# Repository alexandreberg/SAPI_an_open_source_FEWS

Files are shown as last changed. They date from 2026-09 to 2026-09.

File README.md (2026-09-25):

# SAPI — Sistema de Alerta Prévio de Inundações

**Flood Early Warning System** — a low-cost, open-source, LoRa-based platform for water-level
and rainfall monitoring, machine-learning flood forecasting and multi-channel alerts,
developed and validated as a Master's dissertation project (IFSC, Florianópolis, Brazil).

## Read this README in your language / Leia este README no seu idioma

| Language | File |
|---|---|
| 🇬🇧 English | **[README-en.md](README-en.md)** |
| 🇧🇷 Português | **[README-pt.md](README-pt.md)** |

> **Note / Nota** — The code, comments and most technical documentation in this repository
> are in **English**; the README and some documents in `docs/` are also in **Portuguese**,
> the language of the dissertation.
>
> O código, os comentários e a maior parte da documentação técnica deste repositório estão
> em **inglês**; o README e alguns documentos em `docs/` estão também em **português**, o
> idioma da dissertação.

## Quick links / Links rápidos

- Releases (firmware, models, hardware, web interface):
  <https://github.com/alexandreberg/SAPI_an_open_source_FEWS/releases>
- Project specification / Especificação do projeto: [`docs/system-overview.md`](docs/system-overview.md)
- Changelog: [`CHANGELOG.md`](CHANGELOG.md)
- Predictive models / Modelos preditivos:
  [`predictive-models/`](predictive-models/README.md)
- How this repository was built / Como este repositório foi construído:
  [`docs/PROVENANCE.md`](docs/PROVENANCE.md)

## License / Licença

<a href="LICENSE">AGPL v3</a>
<a href="LICENSES/CERN-OHL-S-2.0.txt">Open Source Hardware</a>

Software: [AGPL-3.0-or-later](LICENSE) · Hardware (`hardware/`):
[CERN-OHL-S-2.0](LICENSES/CERN-OHL-S-2.0.txt) · Third-party credits / Créditos: [`NOTICE`](NOTICE)

Copyright (C) 2024–2026 Alexandre Nuernberg.

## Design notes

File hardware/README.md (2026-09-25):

# Hardware — KiCad projects

KiCad 9 projects of the two custom shields used by the SAPI stations. Both are
fabrication-ready (gerbers in `gerber_to_order/`) and licensed under
[CERN-OHL-S-2.0](../LICENSES/CERN-OHL-S-2.0.txt).

| Project | Release | What it does |
|---|---|---|
| [`morpho-shield-v1.2/`](morpho-shield-v1.2/) | `shield-morpho-v1.2.0` | ST Morpho interface board: tipping-bucket rain-gauge pulse counting, serial and trigger/echo ultrasonic sensor interfaces (US-100, HC-SR04, AJ-SR04M), I²C sensor bus (SHT20, BMP280), ADC for solar-panel and battery voltages, ST-Link connector, switched 3.3 V/5 V rails, 5 spare GPIOs |
| [`lora-arduino-shield-v1.0/`](lora-arduino-shield-v1.0/) | `shield-lora-arduino-v1.0.0` | Arduino-footprint radio shield for RFM69HC and LilyGo LoRa32 modules (any frequency; SAPI uses 915 MHz), with a debug LED that can be disabled for low power, a reset button and reconfigurable GPIOs |

## Git LFS and the 3D models

The 3D models (`*.step`, `*.stp`, `*.stl`, `*.wrl`, and zipped models) are stored in
**Git LFS**, ~0.9 GB in total. To clone without them:

```bash
GIT_LFS_SKIP_SMUDGE=1 git clone https://github.com/alexandreberg/SAPI_an_open_source_FEWS.git
```

KiCad opens the projects without the models; only the 3D viewer needs them. Each release
also has the complete project, models included, as a `.tar.gz` attachment.

## Third-party content

The SAPI design files (schematics, layouts, gerbers, BOM) are the author's work. The
projects also contain material **not** authored here, which keeps its original terms and
is not covered by the CERN-OHL-S licence:

- **3D models** (80 files per project) downloaded from CAD-sharing sites — folders named
  `*.snapshot.N` follow their download naming — made in SolidWorks, CATIA, FreeCAD,
  PRO/ENGINEER, the ASCON kernel and KiCad StepUp. Among them: the STM32 BluePill model,
  BME280/BMP280 modules, an SW868 antenna, 2.54 mm jumpers and pin headers, tactile and
  push switches, an optocoupler.
- **Symbol and footprint libraries** from SnapEDA and Digi-Key (`Project_Libraries/`,
  `Libraries/`).
- **Datasheets** of the 74HC166, CD4020BC, CD4040BEE4 and TIL133
  (`morpho-shield-v1.2/datasheets/`).

Their licences were not individually verified. If you are a rights holder and want a file
removed, please open an issue.

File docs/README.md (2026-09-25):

# Documentation

Documents are in English unless marked **(pt)**; a few were written in Portuguese, the
language of the dissertation, and are kept as they are.

## Start here

- [`system-overview.md`](system-overview.md) — stations, gateway, communication,
  requirements, software stack, known limitations
- [`PROVENANCE.md`](PROVENANCE.md) — how this repository was built from the private
  development repository, what was changed and what was left out
- [`architecture/`](architecture/) — network topology and station location map
  ([PDF](architecture/mapa-localizacao-estacoes.pdf))

## Web interface

- [`webserver/deployment-guide.md`](webserver/deployment-guide.md) — installing on shared hosting
- [`webserver/webserver-design.md`](webserver/webserver-design.md) — design and database
- [`webserver/alert-systems-overview.md`](webserver/alert-systems-overview.md) — the alert
  systems (observed-level thresholds and predictive alerts)
- [`webserver/predictions-forecast-verification.md`](webserver/predictions-forecast-verification.md)
  — retrospective verification of fired forecasts
- [`webserver/compare-tool-guide.md`](webserver/compare-tool-guide.md) — the station comparison tool

## Predictive models

- [`predictive-models/production_pipeline_guide.md`](predictive-models/production_pipeline_guide.md) — M4 (LightGBM) in production
- [`predictive-models/production_pipeline_m6_guide.md`](predictive-models/production_pipeline_m6_guide.md) — M6 (MLR) in production
- [`predictive-models/limiares_e_catalogo_v3.md`](predictive-models/limiares_e_catalogo_v3.md) **(pt)** — thresholds and the v3 event catalogue
- [`predictive-models/artefatos_catalogo_v3.md`](predictive-models/artefatos_catalogo_v3.md) **(pt)** — the sensor artifacts excluded from the catalogue

The code, results and audit report are in [`../predictive-models/`](../predictive-models/).

## Hardware

- [`hardware/BOM_custos.md`](hardware/BOM_custos.md) **(pt)** — bill of materials and costs
- [`hardware/station-03-power-instability-2026-08/`](hardware/station-03-power-instability-2026-08/README.md)
  — diagnosis of the Station-03 power/connector fault of August 2026

The KiCad projects are in [`../hardware/`](../hardware/).

## Bench and field tests

- [`tests/us-100/`](tests/us-100/) — US-100 ultrasonic sensor, serial mode (tests 01–04) and
  trigger/echo mode, with photos and readings
- [`tests/m2m/`](tests/m2m/M2M_Test_Report.md) — NB-IoT/LTE-M cellular tests of the gateway
  ([pt](tests/m2m/M2M_Test_Report_Portuguese.md)); modem logs in the same folder, SIM and
  modem identifiers masked
- [`tests/notifications-m4-m6/`](tests/notifications-m4-m6/notification_test_m4_m6.md) —
  Telegram and e-mail notifications of the predictive alerts

## Licensing

- [`licensing/SAPI_Licensing_Report.md`](licensing/SAPI_Licensing_Report.md) — why
  AGPL-3.0-or-later for software and CERN-OHL-S-2.0 for hardware, and the dependency
  compatibility audit

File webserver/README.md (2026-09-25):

# Web interface

PHP/MariaDB application of SAPI: real-time and historical monitoring, station, contact and
alert management, the predictions dashboard, the endpoint that receives the gateway's
data, and the alert cron jobs. In operation at <https://ilha3d.com/sapi/>.

Releases: `webserver-v1.0.0` (first release, 2026-07-06) and `webserver-v1.1.0` (the
version deployed today).

## Layout

| Path | Contents |
|---|---|
| `public_html/sapi/` | The application: dashboard, admin panel, predictions, API, the gateway endpoint (`sensorData/receive-data.php`) |
| `cron/` | Alert engine (e-mail, Telegram) and level-filter cron jobs |
| `private_configs/` | **Templates only** (`*-sample.*`) of the files that hold the database, mail, API and Telegram credentials; they live outside the web root |
| `database/schema_20260313.sql` | Schema snapshot (structure only) |
| `migration_*.sql` | Schema migrations, applied after the snapshot in issue order |

## Deploying

The full guide is [`docs/webserver/deployment-guide.md`](../docs/webserver/deployment-guide.md).
In short:

1. Every path in the code uses `/home/<HOSTINGER_USER>/…`; replace `<HOSTINGER_USER>` with
   your own hosting account (or adapt the paths to your server).
2. Copy each `*-sample.*` file in `private_configs/` and `cron/credenciais-sample.php` to
   its real name (without `-sample`) and fill in your own values. The real names are in
   `.gitignore` — never commit them.
3. The API key in `private_configs/sapi/db_config.php` must match the gateway's
   `apiKey` (see [`../firmware/gateway-01/`](../firmware/gateway-01/README.md)).
4. Create the database from `database/schema_20260313.sql`, then apply
   `migration_issue52.sql` → `migration_issue57.sql` → `migration_issue108.sql` →
   `migration_issue110.sql` → `migration_m6_mlr.sql`.
5. Install the PHP dependencies with Composer (`composer.json`).

Design notes: [`docs/webserver/`](../docs/webserver/).

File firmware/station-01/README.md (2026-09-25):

# SAPM_Sensor_BluePill
This is a code for a flood alert system, FEWS (Flood Early Warning System) or in Portuguese SAPI (Sistema de Alerta Prévio de Inundações) the "M" in SAPM comes from de "Modular" version that will accept other types of sensors.
This version runs on STM32 BluePill.

It connects to a LoRa Gateway build with ESP32 **LILYGO-SIM7000G** wich code can be found [here:](https://github.com/alexandreberg/LILYGO-SIM7000G_LoRa_Gateway)

This is the code that is running in the Sensor-01 installed in the Bridge-02 in 01/01/2025.

The objective of this code is to generate data for the PCAM master thesis to have at least one year of data for analysis.

The code will be improved in the other sensors that will be installed.

## Folder structure:
```
C:.
├───Documentation                           // Documentation Folder
│   ├───Pictures                                    
│   │   └───SAPI_sensor_01                  // Pictures from the sensor PCB, case and fixing structure
│   └───Schematics
│       └───Transmissor_STM32_BluePill_V1   // Schematics of the board
├───src
PS C:\Projetos_GitHub\SAPM\SAPM_Sensor_BluePill>
```

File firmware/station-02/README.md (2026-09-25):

# Rain Gauge Nucleo F103RB (Estação-02)

This is the main production code for the Rain Gauge Station **estacao-02**, developed for a master's degree project.  
The station has been operational since **January 3rd, 2026**.

## 🛠 Hardware Architecture

The station is based on the **STM32 Nucleo F103RB** MCU and utilizes two specialized shields:
* **SAPI LoRa Arduino Shield**: Responsible for long-range wireless communication.
* **SAPI Morpho Shield**: Used for sensor interfacing and power management.

---

## 📊 Live Data & Graphics

You can monitor the real-time sensor data through the following links:

| Variable | Data Visualization Link |
| :--- | :--- |
| 🌡️ **Temperature** | [View Temperature (°C)](https://ilha3d.com/sapi/view.php?id_station=2&var=temperature_C) |
| 🎈 **Pressure** | [View Atmospheric Pressure](https://ilha3d.com/sapi/view.php?id_station=2&var=pressure) |
| 🌧️ **Precipitation** | [View Precipitation Pulses](https://ilha3d.com/sapi/view.php?id_station=2&var=precipitation_pulses) |
| 📡 **Signal (RSSI)** | [View Radio Signal Strength](https://ilha3d.com/sapi/view.php?id_station=2&var=rssi) |
| ☀️ **Panel Voltage** | [View Solar Panel Voltage](https://ilha3d.com/sapi/view.php?id_station=2&var=panel_voltage) |
| 🔋 **Battery** | [View Battery Voltage](https://ilha3d.com/sapi/view.php?id_station=2&var=bat_voltage) |

---

## 📷 Documentation

### General Overview
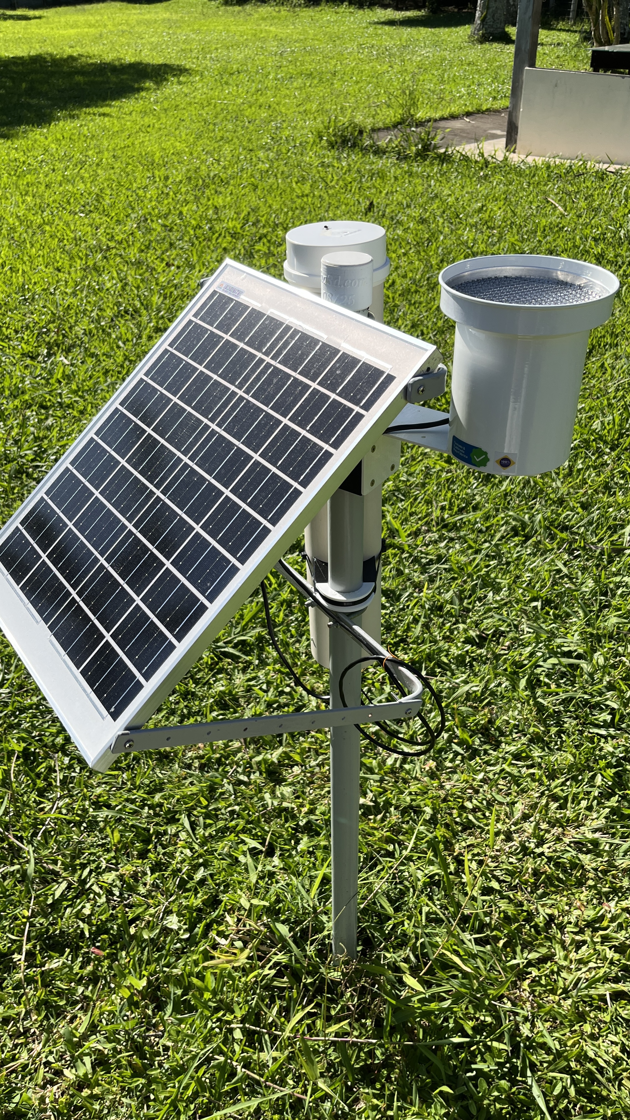
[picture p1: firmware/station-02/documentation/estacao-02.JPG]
General Overview


### MCU and Radio Shield
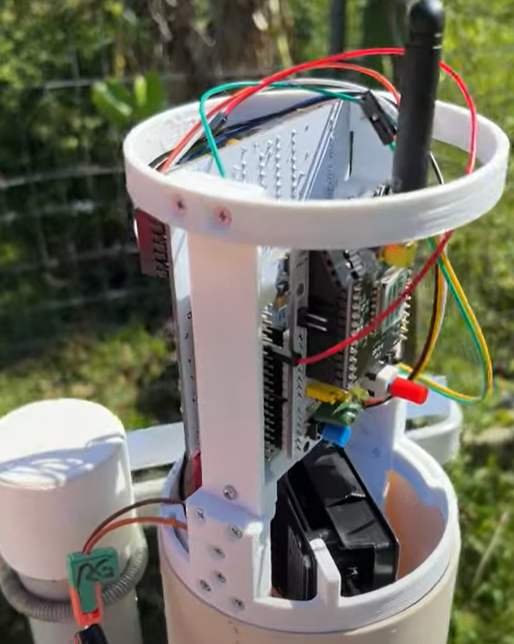
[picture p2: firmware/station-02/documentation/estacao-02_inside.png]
Inside View


### Internal Components
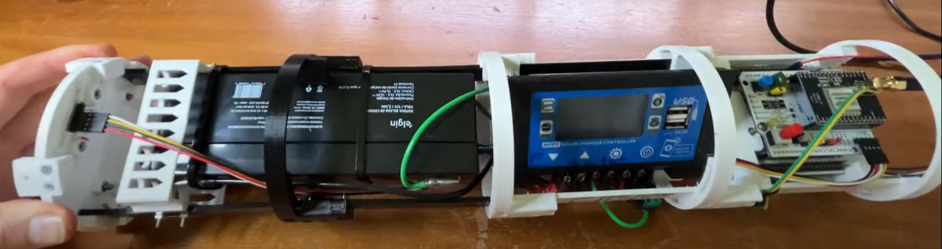
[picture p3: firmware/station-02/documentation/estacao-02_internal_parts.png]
Internal Parts


---
*Developed as part of a Master's Degree

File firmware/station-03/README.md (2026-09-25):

# Water Level Station - Nucleo L476RG (Estacao-03)

This is the main production code for the Water Level Station **estacao-03**, developed for a master's degree project.

## Hardware Architecture

The station is based on the **STM32 Nucleo L476RG** MCU and utilizes two specialized shields:
* **SAPI LoRa Arduino Shield**: Responsible for long-range wireless communication.
* **SAPI Morpho Shield**: Used for sensor interfacing and power management.

---

## GPIO Pin Mapping

### LoRa Radio (SX1276/RFM95W) - SPI Interface

| Pin | Function | Description |
|---|---|---|
| PA4 | LoRa_NSS | SPI Chip Select |
| PA5 | LoRa_SCK | SPI Clock |
| PA6 | LoRa_MISO | SPI Data In (Master In Slave Out) |
| PA7 | LoRa_MOSI | SPI Data Out (Master Out Slave In) |
| PA1 | LoRa_RST | Radio Reset |
| PB0 | LoRa_DIO0 | Interrupt (hardware interrupt pin) |
| PB3 | LoRa_Pwr_enable | Power supply enable (HW-613 module)  |

### Ultrasonic Sensor - Multi-sensor Support

The module supports 3 ultrasonic sensor types with a unified API:

| Sensor | Mode | Range | Baud | Command | Notes |
|---|---|---|---|---|---|
| HC-SR04  | Echo | 2-400 cm  | - | - | Default sensor |
| US-100 | Serial | 2-450 cm  | 9600 | 0x55 | Jumper required for serial mode |
| AJ-SR04M | Serial | 20-800 cm | 9600 | 0x01 | 120K resistor on R19 for mode 2 |

**Pin mapping:**

| Pin | Echo Mode | Serial Mode |
|---|---|---|
| PC11  | Trigger output | UART TX |
| PC10  | Echo input | UART RX |

**Sensor selection:** Change `US_SENSOR_TYPE` in `ultrasonic.cpp` or add build flag:
```ini
build_flags = -D US_SENSOR_TYPE=US_SENSOR_US100
```

**US-100 Serial Mode Note:** To use US-100 in serial mode, the jumper on the back of the sensor board must be installed (short the two pads). Without the jumper, the sensor operates in Echo mode (like HC-SR04).

### BME280/BMP280 Sensor - I2C Interface

| Pin | Function | Description |
|---|---|---|
| PB8 | SCL | I2C Clock |
| PB9 | SDA | I2C Data |

I2C Address: `0x76` (default, may be `0x77` depending on sensor)

### ADC Voltage Measurement

| Pin | Function | Description |
|---|---|---|
| PC0 | Vpanel (A5) | Solar panel voltage (20V max) |
| PC1 | Vbat (A4) | Battery voltage (15V max) |

Note: Uses voltage dividers for level shifting to 3.3V ADC range.

### Rain Gauge Interface (CD4040 Counter + 74HC166 Shift Register)

| Pin | Function | Description |
|---|---|---|
| PA8 | Counter Reset  | CD4040 reset (active HIGH) |
| PB10  | Clock | 74HC166 clock (CLK) |
| PB4 | Shift/Load | 74HC166 SH/!LD control |
| PB5 | Serial Out | 74HC166 QH (serial data output) |

### Status LED

| Pin | Function | Description |
|---|---|---|
| PA0 | LED | Status LED on SAPI Arduino Shield |

---

## Board Configuration

### VBAT Solder Bridge (SB45) - Recommended

On both **Nucleo L476RG** and **Nucleo F103RB** boards, solder the **SB45** jumper to connect VDD to VBAT.

**Why:** The RTC uses the LSE (Low Speed External) 32.768 kHz crystal oscillator. Without VBAT powered, the LSE oscillator must restart from scratch on every boot, which can take several hundred milliseconds to several seconds. During this time, the system may appear to hang at "Tentando inicializar o RTC com LSE..." message.

**Benefits of closing SB45:**
- LSE oscillator remains running during resets (watchdog, software reset)
- Instant RTC startup instead of waiting for crystal stabilization
- Backup registers are preserved across resets
- Only a complete power loss requires LSE to restart

**Location:** SB45 is located on the bottom side of the Nucleo board, near the STM32 MCU.

---

## GPIO Summary by Port

| Port A | Port B | Port C |
|---|---|---|
| PA0 - LED | PB0 - LoRa DIO0 | PC0 - Vpanel ADC |
| PA1 - LoRa RST | PB3 - LoRa Power | PC1 - Vbat ADC |
| PA4 - LoRa NSS | PB4 - RG Shift/Load | PC10 - US Echo |
| PA5 - LoRa SCK | PB5 - RG Serial Out | PC11 - US Trigger |
| PA6 - LoRa MISO | PB8 - I2C SCL | |
| PA7 - LoRa MOSI | PB9 - I2C SDA | |
| PA8 - RG Reset | PB10 - RG Clock | |

---

## Live Data & Graphics

You can monitor the real-time sensor data through the following links:

| Variable | Data Visualization Link |
| :--- | :--- |
| **Water Level** | [View Level (cm)](https://ilha3d.com/sapi/view.php?id_station=33&var=level) |
| **Temperature** | [View Temperature (C)](https://ilha3d.com/sapi/view.php?id_station=33&var=temperature_C) |
| **Pressure** | [View Atmospheric Pressure](https://ilha3d.com/sapi/view.php?id_station=33&var=pressure) |
| **Precipitation** | [View Precipitation Pulses](https://ilha3d.com/sapi/view.php?id_station=33&var=precipitation_pulses) |
| **Signal (RSSI)** | [View Radio Signal Strength](https://ilha3d.com/sapi/view.php?id_station=33&var=rssi) |
| **Panel Voltage** | [View Solar Panel Voltage](https://ilha3d.com/sapi/view.php?id_station=33&var=panel_voltage) |
| **Battery** | [View Battery Voltage](https://ilha3d.com/sapi/view.php?id_station=33&var=bat_voltage) |

---

*Developed as part of a Master's Degree project - SAPI (Sistema de Alerta Previo de Inundacoes)*

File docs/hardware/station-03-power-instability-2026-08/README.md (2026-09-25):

# Station-03 — intermittent power instability causing bad ~335cm readings (2026-08-20/22)

Field/bench notes for a real hardware incident on Station-03 (Nucleo L476RG,
US-100 ultrasonic sensor, serial mode). Documented here so the affected
period is clearly understood as a **hardware problem**, not a sensor
calibration error or a software bug in the delta filter / alert system.

## 1. Symptom

Starting ~2026-08-20 13:46, Station-03 began intermittently transmitting a
fixed, exact **335 cm** level reading, interleaved with the genuine ~46-48cm
level. The bad value never varied — always exactly `335`, never `334` or
`336` — which was itself a clue that this was not ordinary ultrasonic echo
noise (real echo noise, even spurious reflections, is expected to jitter at
least slightly). This caused a cascade of false "flood" alert emails from
`check_alerts.php` throughout 2026-08-20 evening and most of 2026-08-21 (see
Issue references below for the alerting-side fixes that were needed
regardless of the hardware cause).

## 2. Root cause investigation

Cross-referencing the `measurements` table's `reading_number` column against
`level_cm` was the key diagnostic step. `reading_number` is not an arbitrary
sequence — the firmware sets it directly from a persistent boot counter
(`sensorData.reading_number = bootCounter;`, `main.cpp:1056`) stored in an
STM32 RTC backup register (BR4), incremented on every `setup()` run and
**never cleared anywhere in the firmware**. Station-03 deliberately goes
through a full chip reset every reading cycle via `LowPower.shutdown()`
(STANDBY-equivalent deep sleep, woken by the RTC alarm) — this is normal,
by-design behavior, and `reading_number` climbing by ~2 every ~5 minutes
cycle-to-cycle reflects it correctly. Backup registers survive that kind of
reset. They only reset to 0 on a genuine loss of power to the backup domain
itself (VDD/VBAT dropping out) — not a normal RTC-wake reset, and not a
plain external reset (NRST/reset button) either.

Every time `reading_number` was observed dropping back down to a low number
in the DB (i.e. a genuine backup-domain power loss, not the normal wake
cycle), the very next reading was **deterministically** `level_cm = 335`,
self-correcting within 1-2 further readings (about one minute). This
happened at least 6 separate times across the incident:

- 4 times the evening of 2026-08-21, within a ~25-minute window, with no
  user action involved (spontaneous)
- Once more on 2026-08-22 morning, immediately following the sequence
  described in section 3 below

This is strong evidence that the bad reading is not sensor/echo noise at
all, but an artifact of the **very first** ultrasonic read attempt right
after a real power interruption — most likely the sensor (or its serial
link) not yet being ready/warmed-up at that exact moment, with the failure
response landing on `level_cm = 335` after being run through the firmware's
`level_cm = levelZero − distance_raw` conversion (Station-03's `levelZero` =
236cm; `236 + 99 = 335` matches the shape of a known US-100 error/timeout
sentinel value, `-99`, though this exact numeric path has not yet been
confirmed against the current `ultrasonic.cpp` source — see Issue #203).

## 3. What actually happened physically (confirmed with the user, 2026-08-22)

The 2026-08-22 morning occurrence was initially unclear — it looked like a
plain reset-button press alone had triggered the same backup-domain-clear
symptom, which would have been surprising (a plain NRST reset does not
normally clear STM32 backup registers). Clarified afterward: the actual
sequence was **power off → physically reconnect wiring for field
installation → power on** (producing the bad `335` reading as the first
sample after this genuine power cycle) **→ reset button pressed
afterward** (redundant, not the actual trigger). This is consistent with —
not contradictory to — the "genuine power loss" diagnosis; no NRST-only
anomaly needs to be assumed.

Prior to that, on 2026-08-21, the user found and reseated a loose
connection at the ultrasonic sensor's connector/cable. A ~30 minute test
with the enclosure open showed clean readings; closing the enclosure
brought the fault back — pointing at a mechanical contact issue sensitive
to the pressure/flex of closing the case. The connector/cable was
subsequently reseated more carefully and the enclosure resealed.

## 4. Confirmation the fix held

An unattended overnight test (enclosure sealed, ~2026-08-21 23:20 through
2026-08-22 09:31) showed `reading_number` climbing **continuously and
monotonically** from 1 to 233 — the normal +2-per-cycle pattern, ~5:19
between readings — across the full ~10 hour, 100+-cycle window, with
**zero** backup-domain resets and **zero** bad readings (`level_cm` stayed
stable at 30-31cm throughout). This is a clean, strong confirmation that
resealing the connector resolved the intermittent power dropout, at least
under bench/lab conditions.

The station was then moved to field (re)installation on 2026-08-22 (see
section 3's power-cycle event, which is part of that reinstallation).

## 5. Affected data marked invalid

All `measurements` rows for `id_station = 3` between **2026-08-20 13:46:00**
(when the noise began) and **2026-08-22 10:07:46** (the first reading after
the final field-reconnection power-up, `reading_number = 3`, exclusive —
that reading and everything after it is valid field data) were nulled out
and flagged `flag = 'b'` — **513 rows** — because the station was on the
bench for troubleshooting during that whole window, not deployed in the
field: none of that period's data (level, RSSI, temperature, humidity,
voltages) reflects real field/installation conditions, not just the level
readings that happened to look obviously wrong.

## 5b. Recurrence (2026-08-25)

The same `335 cm` fault signature reappeared on 2026-08-25, this time as a
sustained multi-hour oscillation rather than isolated blips, with no
power/reset signature observed on the battery-voltage trace this time. See
`2026-08-25-recurrence.md` in this same directory for the full observation
notes (documentation only — root-cause investigation deferred).

## 6. Follow-up (open)

- **Issue #202** — Station-03 has no simple, reliable way to get a live
  serial console when the ST-Link segment is detached (three
  partially-working paths exist; none worked cleanly this session). This
  made the whole investigation slower than necessary — root cause was
  reconstructed from DB timestamps after the fact instead of observed live.
- **Issue #203** — whether a firmware fix is warranted regardless of the
  hardware root cause (e.g. logging STM32 reset-cause flags at boot to
  distinguish power-on vs. external reset definitively going forward, and/or
  discarding or delaying the first ultrasonic reading after any detected
  backup-domain reset so a recurrence of this kind of power event — e.g. from
  field conditions the bench test didn't cover: rain, vibration, thermal
  cycling — can't reach the database again even if the mechanical fix
  doesn't hold forever).

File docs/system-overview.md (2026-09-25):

# SAPI — System overview

Technical specification of the SAPI flood early-warning system: stations, gateway,
communication, requirements and software stack. The dissertation is the authoritative
source; this document summarises it for people working with the code.

## Project

| | |
|---|---|
| Institution | Federal Institute of Santa Catarina (IFSC) — Florianópolis Campus |
| Program | Master's Program in Climate and Environment (*Stricto Sensu*) |
| Research line | Instrumentation and Technological Development |
| Author | Alexandre Nuernberg |
| Qualification | 2025-05-19 |

**General objective:** develop and validate a flood monitoring and early-warning system.

**Specific objectives:** (1) implement real-time monitoring of water level and
precipitation; (2) apply a machine-learning model to predict the flood water level;
(3) validate the system's prediction and alert performance in a real environment.

## Functional requirements

- Easy installation and operation
- Ultra-low-power components
- Grid-independent operation
- Water level **and** precipitation measurement (non-contact ultrasonic sensing and a
  tipping-bucket rain gauge)
- Multi-level alerts (Atenção / Alerta / Inundação) automatically sent to registered
  contacts — see [`webserver/alert-systems-overview.md`](webserver/alert-systems-overview.md)
- Long-range communication: the target is 5–10 km, enough to cover a stream's course or
  several points of a neighbourhood (LoRa reaches 1–15 km depending on terrain)
- Web interface for management, data visualisation and alert registration
- Low-cost components (the most expensive single item is the R$ 956 tipping-bucket rain
  gauge — see [`hardware/BOM_custos.md`](hardware/BOM_custos.md))

## Field deployment

All stations are in the Cachoeira do Bom Jesus neighbourhood, Florianópolis (north of the
island), on one urban stream. Two water-level stations are mounted on bridges; the rain
gauge stands on the lawn in front of the residence that also houses the gateway.

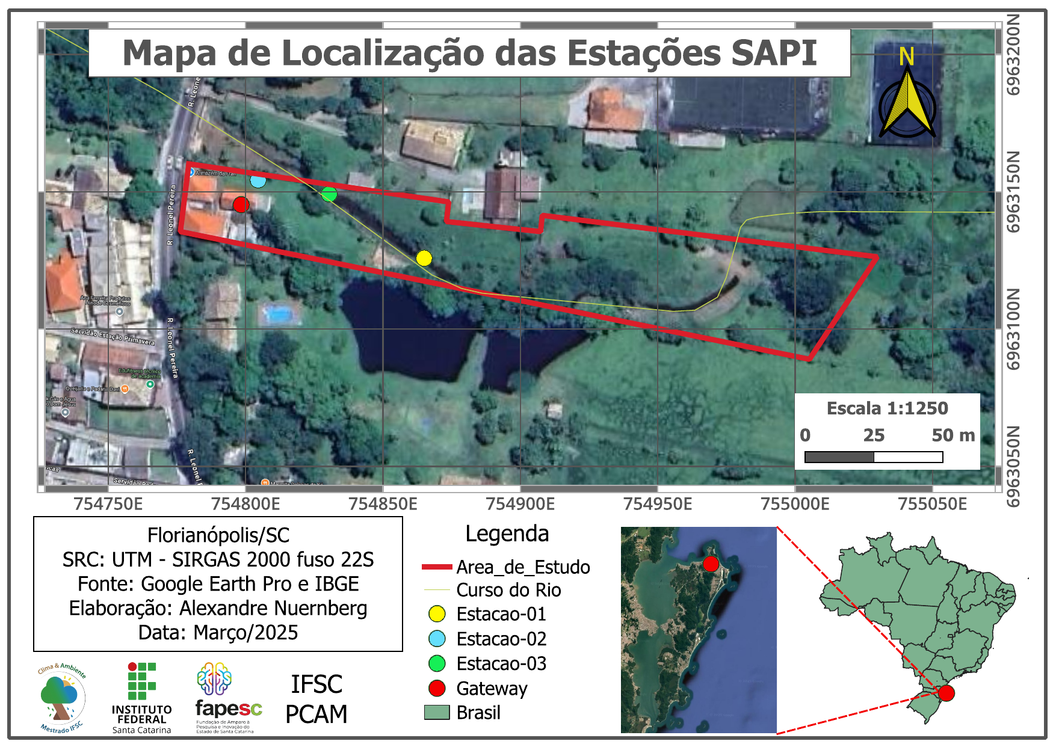
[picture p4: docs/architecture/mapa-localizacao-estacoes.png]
Station locations


### Station-01 — water level

| | |
|---|---|
| In operation since | 2024-12-30 |
| MCU | STM32F103C8T6 (BluePill, 64 KB flash) |
| Sensor | HC-SR04 ultrasonic (max. range 4.5 m), 11-reading median filter |
| Radio | LoRa RFM95W (SX1276), 915 MHz |
| Power | Grid, with a 4,200 mAh battery backup |
| Sampling | ~1 min |
| Installation | Bridge, ~70 m from the gateway |
| Position | 27°25'53.13"S, 48°25'18.83"W |
| Calibration | `levelZero` = 291.0 cm |
| Source / release | [`firmware/station-01/`](../firmware/station-01/) · `station-01-v1.0.0` |

### Station-02 — precipitation

| | |
|---|---|
| In operation since | 2026-01-02 |
| MCU | STM32 Nucleo F103RB |
| Shields | SAPI Shield Morpho V1.2 (power control, rain-gauge pulse storage) and SAPI LoRa Arduino Shield V1.0 |
| Sensors | Tipping-bucket rain gauge PB10 (0.25 mm/pulse), BMP280 (temperature, pressure), ADC for Vpanel and Vbat |
| Radio | LilyGo LoRa32 |
| Power | Solar, 12 V / 2.3 Ah sealed lead-acid battery, deep sleep |
| Sampling | ~15 min |
| Installation | Lawn in front of the residence (not on a bridge) |
| Source / release | [`firmware/station-02/`](../firmware/station-02/) · `station-02-v1.0.0` |

### Station-03 — water level

| | |
|---|---|
| In operation since | 2026-03-01 |
| MCU | STM32 Nucleo L476RG (ultra-low-power L4 series) |
| Sensors | US-100 ultrasonic in **serial mode** (its firmware compensates the speed of sound for temperature internally), SHT20 (ambient temperature and humidity, reported as telemetry only), ADC for Vpanel and Vbat |
| Radio | LilyGo LoRa32 |
| Power | Solar, 12 V / 4.3 Ah Li-ion battery, EPEVER Tracer2606BP charger |
| Sampling | ~5 min |
| Installation | Second bridge, ~30 m from the gateway (41 m from Station-01) |
| Calibration | `levelZero` = 236 cm (reads 199 cm at a river level of 37 cm, 2026-03-01) |
| Note | The ST-Link was removed from the Nucleo board to save power; flashing needs external SWD wiring |
| Source / release | [`firmware/station-03/`](../firmware/station-03/) · `station-03-v1.0.0` |

A power/connector fault in August 2026 produced spurious ~335 cm readings and a burst of
false alerts; it was diagnosed and repaired, and the affected data flagged invalid — see
[`hardware/station-03-power-instability-2026-08/`](hardware/station-03-power-instability-2026-08/README.md).

### Gateway-01

| | |
|---|---|
| Hardware | LilyGO T-SIM7000G (ESP32 + SIM7000G modem) with a LoRa32 radio |
| Location | Indoors, next to the Wi-Fi router |
| Function | Receives the LoRa packets, validates them and forwards them to the web server over HTTPS |
| Links | Wi-Fi (primary) and NB-IoT cellular failover |
| Source / release | [`firmware/gateway-01/`](../firmware/gateway-01/) · `gateway-01-v2.0.0` |

The NB-IoT failover (SSLClient/BearSSL, TLS 1.2 on both links) was validated in production
on 2026-03-08: 260 transmissions, 247 over Wi-Fi and 13 over NB-IoT, 100 % delivered. It is
inactive today because the M2M SIM used in the test was on loan and has been returned; the
gateway runs on Wi-Fi only until a permanent SIM is installed. LTE-M-only SIMs do not work
with this firmware. Test report: [`tests/m2m/`](tests/m2m/M2M_Test_Report.md).

## Communication

| | |
|---|---|
| Frequency | 915 MHz (Brazilian ISM band, ANATEL) |
| Serialisation | MessagePack (40–60 % smaller than JSON) |
| Authentication | HMAC-SHA256 with a pre-shared key |
| Payload | Binary sensor readings + timestamp + station id |
| Sampling interval | Configurable per station, 1–15 min |

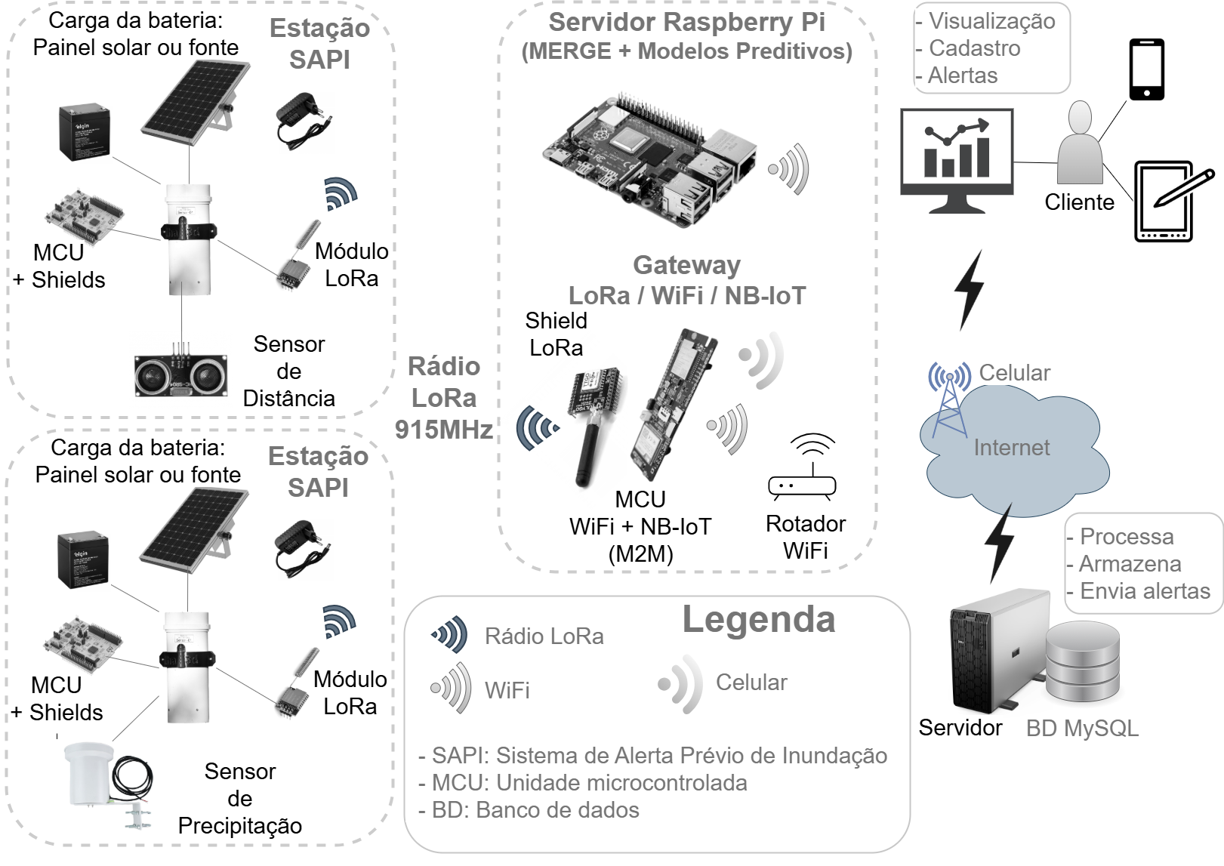
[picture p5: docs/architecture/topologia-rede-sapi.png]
Network topology


## Sensors

- **HC-SR04** (Station-01): low cost, 4.5 m range.
- **US-100** (Station-03): in serial mode it read reliably to 350–420 cm in the bench
  tests; in trigger/echo mode only to ~165 cm, too short for a bridge. See
  [`tests/us-100/`](tests/us-100/).
- **AJ-SR04M**: supported by the Morpho shield's interface, not yet tested.
- Ultrasonic sensors are prone to spurious readings from reflections and need in-situ
  calibration against a staff gauge.

## Microcontroller selection

Evaluated for the stations: deep-sleep consumption, processing capacity, ecosystem
support and physical volume — the 100 mm PVC housing limits the battery to ≤ 6.0 Ah, far
below the ≤ 22 Ah of larger professional stations, so active-mode consumption matters.

- **Rejected:** generic Arduino boards (auxiliary components keep sleep current in the mA
  range); Nordic nRF52/nRF53 (lowest active consumption, but a separate SDK ecosystem);
  ESP32 for the stations (higher active consumption in that energy budget — it is used for
  the grid-powered gateway).
- **Chosen:** STM32L476RG (Station-03, ultra-low-power L4 series); STM32F103C8T6 BluePill
  (Station-01, ~4 mA average in its operating cycle); STM32F103RB Nucleo (Station-02).

## Software stack

**Station firmware:** PlatformIO (Arduino framework for STM32), ARM GCC; libraries
`sandeepmistry/LoRa`, `hideakitai/MsgPack`, ArduinoJson; STOP2 low-power mode with RTC
alarm wake-up, unused pins set to analog, peripheral clock gating.

**Gateway firmware:** Arduino/ESP-IDF on the ESP32; continuous LoRa RX with
interrupt-driven packet handling, Wi-Fi auto-reconnect, NB-IoT failover.

**Gateway flow:** receive the LoRa packet → validate the HMAC → decode MessagePack →
forward to the server over Wi-Fi (or NB-IoT) → log the result.

**Server side:** PHP/MariaDB web interface and alert cron jobs on shared hosting
([`../webserver/`](../webserver/)); MERGE/CPTEC precipitation ingestion
([`../pipelines/merge2mysql/`](../pipelines/merge2mysql/)); M4 (LightGBM) and M6 (MLR)
forecasts on a Raspberry Pi ([`../predictive-models/`](../predictive-models/)).

## Known limitations and roadmap

- Firmware: no watchdog in every station yet; no persistent error log; the 48 h offline
  buffer in flash is specified but not implemented; LoRa retries without exponential
  backoff; firmware not yet unified across station types.
- Gateway: no packet acknowledgement; no local offline queue; no OTA updates; a permanent
  M2M SIM is still needed to use the NB-IoT failover.
- Web interface: mobile layout, data export formats and a station-health dashboard are
  pending.
- Hardware: AJ-SR04M sensor still to be tested; EPEVER charger still to be configured for
  lithium batteries.

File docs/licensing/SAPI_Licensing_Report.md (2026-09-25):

# SAPI — Open-Source Licensing Report

**Author**: Alexandre Nuernberg  
**Institution**: IFSC — Federal Institute of Santa Catarina, Florianópolis Campus  
**Program**: Master's Program in Climate and Environment  
**Date**: April 2026  
**Tracking issue**: #80

---

## 1. Introduction

The SAPI (Sistema de Alerta Prévio de Inundações) project is being published as open source as part of a master's thesis. The project encompasses several artifact types:

- **Embedded firmware** — C/C++ code for STM32 and ESP32 microcontrollers (PlatformIO/Arduino framework)
- **Web interface** — PHP server-side application for data visualization and alert management
- **Data processing scripts** — Python scripts for MERGE ingestion, data quality, and predictive modeling
- **Hardware designs** — KiCAD 9 PCB schematics (added in issue #151); Fusion 360 CAD files TBD

Choosing the correct license matters for three reasons specific to this project:

1. **Scientific reproducibility** — The thesis committee, reviewers, and future researchers must be able to inspect, replicate, and verify every component of the system that generated the thesis data.
2. **Public-good protection** — A flood early warning system serves the public interest. Keeping the ecosystem open ensures that improvements made by governments, NGOs, or companies flow back to the community.
3. **Academic traceability** — The license is part of the permanent record of what was published, when, and under what terms.

---

## 2. License Categories

### 2.1 Permissive Licenses (MIT, Apache 2.0, BSD)

Permissive licenses place almost no restrictions on what recipients can do with the code.

| Property | Detail |
|---|---|
| Can use commercially | Yes |
| Can modify | Yes |
| Must share modifications | **No** |
| Must credit original author | Yes (attribution) |
| Patent protection | Apache 2.0 includes explicit patent grant; MIT/BSD do not |

**Examples**: Arduino core, most Arduino libraries, Python packages (NumPy, pandas, scikit-learn), the Linux kernel modules ecosystem.

**Pro**: Maximum adoption. Zero friction for companies or governments wanting to use the code.  
**Con**: Nothing legally prevents a company from taking the code, improving it, and never sharing those improvements.

---

### 2.2 Weak Copyleft (LGPL — GNU Lesser General Public License)

LGPL is designed for **libraries**. It allows using the library inside proprietary software without triggering copyleft, but modifications *to the library itself* must be released.

| Property | Detail |
|---|---|
| Use as library in proprietary code | Yes (this is the key relaxation) |
| Modify and redistribute | Must share modifications to the LGPL component |
| Link dynamically from proprietary code | Allowed |

**Example**: Ultimaker's Cura slicer uses LGPL, which allows third-party plugin developers to sell proprietary paid plugins.

**Relevance to SAPI**: TinyGSM (LGPL 2.1) is used in the gateway firmware. SAPI's own code can be under AGPL v3 and still use TinyGSM because LGPL libraries are compatible with AGPL.

---

### 2.3 Strong Copyleft (GPL v3 — GNU General Public License)

GPL is the classic copyleft license. If you distribute a product that contains GPL code, you **must** release the complete corresponding source code under GPL v3.

| Property | Detail |
|---|---|
| Distribute binary product | Must release all source code |
| Modify and redistribute | Must release under GPL v3 |
| Network use (SaaS/server) | **Not covered** — the server-side loophole |
| Patent retaliation | Included |

**Server-side loophole**: If someone runs GPL software on a server and users access it over a network, they are not "distributing" the software in the legal sense. They are not required to release the source code. This is a significant gap for a project like SAPI that has a web interface.

---

### 2.4 Network Copyleft (AGPL v3 — GNU Affero General Public License)

AGPL v3 is GPL v3 with one additional clause (Section 13): if you run a modified version of the software **over a network** and users interact with it, you must offer them the complete source code. This closes the server-side loophole.

| Property | Detail |
|---|---|
| Distribute binary product | Must release source under AGPL v3 |
| Run modified version as web service | **Must offer source code to users** |
| Patent retaliation | Included (inherits from GPL v3) |
| Compatible with GPL v3 | Yes (one-way: AGPL can use GPL; GPL cannot use AGPL) |

**Why this matters for SAPI**: The web interface (PHP) runs on a server. If a municipal government or company deploys a modified version of SAPI's web interface, AGPL v3 requires them to publish their modifications. GPL v3 alone would not cover this scenario.

---

### 2.5 Hardware Licenses (for future reference)

Software licenses were not designed for hardware designs. Two dedicated options exist:

#### CERN Open Hardware Licence v2 (CERN OHL v2-S — Strongly Reciprocal)

The hardware equivalent of AGPL v3. Developed by CERN for scientific instruments.

- If you manufacture and distribute a product based on CERN OHL v2-S hardware designs, you must release the design sources.
- Covers: schematics, PCB layouts, mechanical drawings, BOMs (bills of materials).
- Widely used in open scientific hardware (particle physics, astronomy instruments).
- Website: [ohwr.org/cernohl](https://ohwr.org/cernohl)

#### Creative Commons BY-SA 4.0

Simpler and more widely understood. The "SA" (ShareAlike) clause is the copyleft equivalent for creative works including hardware documentation and schematics.

- Easier to communicate to non-engineers.
- Used by: Arduino (hardware), many maker community projects.
- **Limitation**: Not specifically designed for hardware; less precise about what "source files" means for PCBs.

#### Recommendation for SAPI hardware (when KiCAD/CAD files are added)

**CERN OHL v2-S** for PCB schematics and layouts (KiCAD files).  
**CC BY-SA 4.0** is an acceptable alternative if simplicity is preferred.  
For Fusion 360 / STEP files: publish both `.f3d` (full parametric editability) and `.step` (open ISO 10303 standard, readable by any CAD tool including FreeCAD). Fusion 360 licenses the tool, not your designs — you own and can freely distribute what you create.

---

## 3. Real-World Examples: The 3D Printer Case Study

The 3D printer ecosystem illustrates all license types in practice and the consequences of each choice.

| Company / Project | License | Behavior | Outcome |
|---|---|---|---|
| **Marlin firmware** | GPL v3 | Base firmware for most FDM printers | Everyone who builds on Marlin must release source |
| **Prusa Research** | GPL v3 | Fully embraces open source; publishes all firmware modifications on GitHub | True open source; community trusts and contributes back |
| **Creality** | GPL v3 (violated) | Used Marlin for years without releasing modifications | Community called them out; eventually released incomplete code under sustained pressure |
| **Ultimaker / Cura** | LGPL v3 | Slicer software; uses LGPL so plugin ecosystem can be proprietary | Paid plugins exist legally; base slicer stays open |
| **BambuLab** | Proprietary | Closed-source firmware; only recently opened parts under pressure | Community cannot audit or modify the printer |

**Key insight from Creality**: GPL copyleft enforcement depends on the community applying social and legal pressure. It is not automatic. For a public-good project like SAPI, the copyleft clause is most valuable as a clear signal of intent — and as a legal mechanism if a well-resourced actor ever commercializes the system.

---

## 4. Third-Party Dependency Audit

All SAPI dependencies must be **compatible** with AGPL v3. A dependency is compatible if its license allows it to be combined with AGPL v3 code. MIT, BSD, Apache 2.0, and LGPL are all compatible with AGPL v3.

### 4.1 Firmware (C/C++ — PlatformIO)

| Library | Author | License | Component | Compatible with AGPL v3 |
|---|---|---|---|---|
| Arduino-LoRa | Sandeep Mistry | MIT | Station-02, 03, Gateway-01 | ✅ Yes |
| TinyGSM | Volodymyr Shymanskyy | LGPL 2.1 | Gateway-01 | ✅ Yes |
| StreamDebugger | Volodymyr Shymanskyy | MIT | Gateway-01 | ✅ Yes |
| ArduinoJson | Benoit Blanchon | MIT | Gateway-01 | ✅ Yes |
| SSLClient | Open Source Labs (OSU) | MIT | Gateway-01 | ✅ Yes |
| ArduinoHttpClient | Arduino Libraries | Apache 2.0 | Gateway-01 | ✅ Yes |
| NewPing | Tim Eckel | MIT | Station-02 | ✅ Yes |
| RTClib | Adafruit / JeeLabs | MIT | Station-02, 03 | ✅ Yes |
| Adafruit BMP280 | Adafruit | BSD | Station-02, 03 | ✅ Yes |
| STM32duino Low Power | STMicroelectronics | BSD | Station-02, 03 | ✅ Yes |
| STM32duino RTC | STMicroelectronics | BSD | Station-02, 03 | ✅ Yes |
| DFRobot SHT20 | DFRobot | MIT | Station-03 | ✅ Yes |

### 4.2 Web Interface (PHP)

| Package | Author | License | Compatible with AGPL v3 |
|---|---|---|---|
| rybakit/msgpack | Eugene Batyaev | MIT | ✅ Yes |
| phpunit/phpunit (dev) | Sebastian Bergmann | BSD 3-Clause | ✅ Yes |
| phpmailer/phpmailer | PHPMailer contributors | LGPL-2.1 | ✅ Yes |

> Added `phpmailer/phpmailer` during issue #80 implementation — used by
> `webserver/composer.json` and `webserver/cron/composer.json` for
> alert emails, but was missing from the original April audit above.

### 4.3 Data Processing (Python)

| Package | License | Compatible with AGPL v3 |
|---|---|---|
| pandas | BSD 3-Clause | ✅ Yes |
| numpy | BSD 3-Clause | ✅ Yes |
| scipy | BSD 3-Clause | ✅ Yes |
| scikit-learn | BSD 3-Clause | ✅ Yes |
| matplotlib | PSF/BSD-style | ✅ Yes |
| sqlalchemy | MIT | ✅ Yes |
| python-dotenv | BSD 3-Clause | ✅ Yes |
| pymysql | MIT | ✅ Yes |
| mysql-connector-python | GPL 2.0 | ✅ Yes (GPL is compatible with AGPL) |
| darts | Apache-2.0 | ✅ Yes |
| lightgbm | MIT | ✅ Yes |
| requests | Apache-2.0 | ✅ Yes |

> Added `darts`, `lightgbm`, and `requests` during issue #80 implementation —
> these are the actual pinned dependencies of the production predictive-model
> pipelines (`predictive-models/production/requirements_production.txt`
> for Model4-LGBM, issue #108; `.../production_m6/requirements_production_m6.txt`
> for Model6-MLR, issue #120), which were deployed after the original April
> audit above and were missing from it.

**Conclusion**: All dependencies are compatible with AGPL v3. No license conflicts exist.

---

## 5. Decision and Rationale

### Chosen License: GNU Affero General Public License v3.0 (AGPL v3)

**Applied to**: All software components — embedded firmware (C/C++), web interface (PHP), data processing scripts (Python).

**Hardware**: **CERN OHL v2-S** applied to KiCAD 9 PCB designs (issue #151). Fusion 360 CAD files deferred.

### Why AGPL v3

| Factor | Analysis |
|---|---|
| Public-good mission | SAPI serves communities at flood risk. Copyleft ensures improvements by governments or companies flow back, not into proprietary products. |
| Web interface exists | GPL v3 alone has the server-side loophole. AGPL v3 covers it: if someone deploys a modified SAPI web interface, they must publish the source. |
| All dependencies compatible | Every library used (MIT, BSD, LGPL, Apache 2.0) is compatible with AGPL v3. No conflicts, no re-licensing required. |
| Single license for everything | One AGPL v3 covers firmware + web + Python. Simpler to communicate, simpler to enforce. |
| IP ownership clear | The project IP belongs entirely to the student/author. No institutional approval needed. |
| Academic reproducibility | The copyleft clause guarantees that derivative works remain inspectable — important for scientific verification. |

### What AGPL v3 does NOT restrict

- Reading, running, and studying the code — always free
- Contributing back via pull requests — always welcome
- Using the system for flood monitoring — always free, commercial or not
- Publishing papers that cite the system — always free

What it *does* require: anyone who **distributes** a modified version or **runs it as a network service** must publish their source code under AGPL v3.

---

## 6. Implementation Checklist

The following tasks must be completed to properly apply AGPL v3 to the repository. Tracked in issue #80.

- [x] Add `LICENSE` file at repository root — full AGPL v3 text (from [gnu.org/licenses/agpl-3.0.txt](https://www.gnu.org/licenses/agpl-3.0.txt))
- [x] Add SPDX license identifier header to each source file:
  - C/C++ firmware files: `// SPDX-License-Identifier: AGPL-3.0-or-later`
  - PHP files: `// SPDX-License-Identifier: AGPL-3.0-or-later`
  - Python files: `# SPDX-License-Identifier: AGPL-3.0-or-later`
- [x] Add copyright line to each file header: `// Copyright (C) 2024–2026 Alexandre Nuernberg`
- [x] Add license badge and section to `README.md`
- [x] Add `NOTICE` file at root crediting key third-party dependencies and their licenses
- [x] Add `LICENSES/` directory with CERN OHL v2-S text (hardware files now published in issue #151)

> Items above implemented in issue #80 (branch `feature/issue-80-agpl-license`).

### Recommended file header (C/C++ example)

```cpp
/**
 * @file    main.cpp
 * @brief   Station-03 firmware — water level monitoring with US-100 sensor
 *
 * SPDX-License-Identifier: AGPL-3.0-or-later
 * Copyright (C) 2024–2026 Alexandre Nuernberg <alexandreberg@gmail.com>
 *
 * This program is free software: you can redistribute it and/or modify
 * it under the terms of the GNU Affero General Public License as published by
 * the Free Software Foundation, either version 3 of the License, or
 * (at your option) any later version.
 *
 * This program is distributed in the hope that it will be useful,
 * but WITHOUT ANY WARRANTY; without even the implied warranty of
 * MERCHANTABILITY or FITNESS FOR A PARTICULAR PURPOSE. See the
 * GNU Affero General Public License for more details.
 *
 * You should have received a copy of the GNU Affero General Public License
 * along with this program. If not, see <https://www.gnu.org/licenses/>.
 */
```

### Recommended file header (Python example)

```python
# SPDX-License-Identifier: AGPL-3.0-or-later
# Copyright (C) 2024–2026 Alexandre Nuernberg <alexandreberg@gmail.com>
#
# This program is free software: you can redistribute it and/or modify
# it under the terms of the GNU Affero General Public License as published
# by the Free Software Foundation, either version 3 of the License, or
# (at your option) any later version.
```

---

## 7. Hardware Licensing

KiCAD 9 PCB designs (SAPI LoRa Arduino Shield V1.0 and Rain Gauge ST Morpho Shield V1.2) were added to the repository in issue #151 under **CERN OHL v2-S**. Fusion 360 / STEP mechanical CAD files are still to be added.

### Applied License — CERN OHL v2-S

- Full name: *CERN Open Hardware Licence Version 2 — Strongly Reciprocal*
- Hardware equivalent of AGPL v3 (strong copyleft for physical designs)
- Requires: anyone who manufactures and distributes a product based on the designs must release their design sources
- Used by: CERN scientific instruments, many open scientific hardware projects
- Text: [ohwr.org/project/cernohl](https://ohwr.org/project/cernohl)

### Alternative considered — Creative Commons BY-SA 4.0

- Simpler, more widely understood
- ShareAlike clause is the copyleft equivalent for creative works
- Less precise about what constitutes "source" for hardware (gerber files? KiCAD project? BOM?)
- Used by: Arduino hardware, many maker projects

### Note on Fusion 360 and STEP files

Autodesk licenses the **software** (Fusion 360), not the **designs** you create with it. You own your designs and may distribute them under any license. For maximum compatibility:

- Publish `.f3d` files for full parametric editability (requires Fusion 360)
- Publish `.step` files (ISO 10303) for tool-agnostic compatibility — readable by FreeCAD, SolidWorks, Onshape, and any other CAD application

This is analogous to writing a document in Microsoft Word and distributing the PDF — Microsoft owns Word, but you own the document.

---

## 8. License Logos (for presentations)

Official-source logo files (not tiny web badges) are kept in
[`docs/licensing/logos/`](logos/) for use in slides, posters, and the
dissertation defense presentation.

| File | Represents | Size | Source | License of the logo itself |
|---|---|---|---|---|
| `logos/agplv3-with-text-162x68.png` | Software license (AGPL-3.0-or-later) | 162×68 px, the largest raster size FSF publishes | [gnu.org/graphics/agplv3-with-text-162x68.png](https://www.gnu.org/graphics/agplv3-with-text-162x68.png) | Public domain (FSF license-logos page) |
| `logos/lgpl-agpl-v3-logos.svg` | Software license (AGPL-3.0-or-later), vector source | Scalable — crop/extract the AGPL mark in Inkscape/Illustrator for print-quality enlargement beyond 162×68 | [gnu.org/graphics/lgpl-agpl-v3-logos.svg](https://www.gnu.org/graphics/lgpl-agpl-v3-logos.svg) | Public domain (FSF license-logos page) |
| `logos/open-source-hardware-logo.svg` | Hardware license (CERN-OHL-S-2.0) — generic stand-in, see note below | Scalable vector | [Wikimedia Commons](https://commons.wikimedia.org/wiki/File:Open-source-hardware-logo.svg) | CC-SA / public domain (simple geometric mark) |

**Important note on the hardware logo**: unlike the GNU project, **CERN does not
publish a dedicated logo/mark for CERN-OHL-S-2.0** specifically (checked
[ohwr.org/licences](https://ohwr.org/licences/), CERN's OHL site, and the
Wikipedia article — none carry a license-specific graphic, only the license
text/PDF). The gear logo above is the community "Open Source Hardware" (OSHW)
mark designed by Macklin Chaffee, used generically to indicate hardware that
complies with the Open Source Hardware Definition — it is **not**
CERN-specific and doesn't name the exact license variant. If the presentation
needs the license identified unambiguously, pair the gear icon with the text
"CERN-OHL-S-2.0" rather than presenting the gear alone as if it were an
official CERN mark.

---

## 9. References

| Resource | URL |
|---|-----|
| AGPL v3 full text | https://www.gnu.org/licenses/agpl-3.0.html |
| GPL v3 full text | https://www.gnu.org/licenses/gpl-3.0.html |
| LGPL v2.1 full text | https://www.gnu.org/licenses/lgpl-2.1.html |
| Choose a License (GitHub) | https://choosealicense.com |
| SPDX License List | https://spdx.org/licenses/ |
| CERN OHL v2 | https://ohwr.org/cernohl |
| Creative Commons BY-SA 4.0 | https://creativecommons.org/licenses/by-sa/4.0/ |
| Open Source Initiative | https://opensource.org/licenses |
| License compatibility chart | https://www.gnu.org/licenses/license-compatibility.html |

---

*This document was produced as part of the SAPI master's thesis research. It serves as both a decision record and a reference for contributors and reviewers.*

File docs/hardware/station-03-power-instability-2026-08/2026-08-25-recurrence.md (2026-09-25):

# Station-03 — recurrence of bad ~335cm level readings (2026-08-25)

Follow-up to the original incident writeup in this same directory
(`README.md`, 2026-08-20/22). The same fault signature — a fixed, exact
**335 cm** level reading — reappeared today, 2026-08-25. This note records
what was observed from the web dashboard (screenshots reviewed at
`/tmp/prob-est-03/`, taken ~07:04–07:11 local time) **before** any
troubleshooting action was taken, per the user's request to document first
and investigate later. No root cause is claimed here — see "Open questions"
below.

## 1. Symptom this time: sustained oscillation, not isolated blips

Unlike the 2026-08-20/22 incident (isolated bad `335` samples,
self-correcting within 1-2 cycles after a backup-domain power-loss reset),
today's level chart shows a **sustained square-wave oscillation** between
the genuine baseline (~47-48 cm) and the clamped `335 cm` ceiling, repeating
across many consecutive cycles from **~05:28 UTC through at least ~10:04
UTC** (the end of the available window at screenshot time) — roughly 4.5+
hours. `335.00` is also the exact all-time max in the chart's stats panel
(N=113, Média 133.99, Min 47.00, Máx 335.00), confirming every bad sample
hit the same clamp value as before, not a range of noisy values.

This produced the expected cascade of false alerts: the alert inbox shows
`[SAPI] FLOOD` emails at 04:35 and 05:20 (reporting the `335 cm` value and
an "INUNDAÇÃO" threshold crossing), interleaved with `[SAPI] Normalizado`
emails — consistent with the alert system correctly reacting to bad data
it has no way to distinguish from a real level, not a bug in the alerting
logic itself (see the existing `check_alerts.php` debounce/hysteresis work,
Issues #193/#195/#197, for that separate concern).

## 2. Everything else on the station stayed fully operational

Cross-checking every other channel transmitted by Station-03 over the exact
same time window:

- **Surface temperature** (read from the *same* US-100 sensor's internal
  temperature-compensation function, over the same serial link as the
  distance measurement): continuous throughout, no dropouts, no clamping —
  tracked a plausible slow diurnal curve (13°C → 10°C overnight, back up to
  ~12°C by mid-morning). This is the strongest single piece of evidence that
  the US-100 module itself was powered and its serial link was alive and
  responding correctly — only the *echo-distance* half of the sensor's
  function failed, not the sensor as a whole.
- **Air temperature**: continuous, unaffected, normal diurnal shape.
- **Relative humidity**: continuous, unaffected, smooth curve 78% → ~98%.
- **RSSI**: stable around -73 dBm (min -74, max -69) for the entire window —
  no LoRa link dropouts, no correlation with the level oscillation.
- **Battery voltage**: smooth, monotonic discharge from 12.10V to 11.71V —
  no brownout dips, no discontinuities that would suggest a power-loss/reset
  event (contrast with the previous incident, where bad readings tracked
  backup-domain resets visible via `reading_number`).
- **Panel voltage**: normal solar profile — flat ~0V overnight, ramping up
  to ~13V starting ~09:00 UTC as the sun rose. Normal, unaffected.

**Conclusion of this observation pass**: the fault is isolated to the US-100
ultrasonic **distance/echo** measurement path specifically. The station's
power system, MCU, LoRa radio/gateway link, and even the *other* function of
the same US-100 module (its internal temperature reading) all continued
operating normally through the entire affected window. This is consistent
with the framing needed for the dissertation/incident record: this is not a
station-wide outage, and not (on this evidence alone) a station power
problem — it did not reproduce the previous incident's power/reset
signature.

## 3. Action taken / planned (not yet done as of this note)

- User plans to press the physical reset button on Station-03 this evening
  after arriving home, to see whether that alone normalizes the readings.

## 4. Open questions for later investigation (explicitly deferred — not being pursued now)

Per the user, this note is observation-only; the following is recorded so it
isn't lost, not as a plan being executed:

- **US-100 hardware fault**: the *original* US-100 unit (in service since
  station install) is the one currently installed. Notably, the
  *replacement* unit swapped in at some point reportedly showed the *same*
  symptom, then the original was put back and the symptom is recurring again
  now — i.e. two different physical US-100 units have both exhibited this
  failure mode at different times. That weakens (but doesn't rule out) a
  single-defective-unit explanation and points more toward something shared
  between both units' installations (wiring, connector, bus noise, or
  firmware) — worth keeping in mind when this is investigated, without
  concluding it here.
- **Wiring / SPI-bus noise**: the cabling from the SAPI Shield Morpho to the
  US-100 connector was fully redone last time using wire-wrap connections.
  Worth checking for noise/continuity issues on that signal path.
- **Firmware**: whether this is a recurrence of the same root cause tracked
  in Issue #203 (bad first-reading-after-reset), a related firmware issue,
  or something new — cannot be determined from the dashboard screenshots
  alone; needs `reading_number` continuity from the `measurements` table
  (as was done for the original incident) and/or live serial console access
  (Issue #202, still open) to investigate properly.

No `measurements` rows have been flagged invalid for this recurrence yet —
that should happen once the affected window is confirmed bounded (i.e. after
tonight's reset and any further troubleshooting settles the station back to
normal), following the same procedure as section 5 of the original
`README.md`.

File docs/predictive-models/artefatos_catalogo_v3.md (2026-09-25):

# Artefatos de sensor no catálogo v3 — exclusão e remoção do treino (Issue #227, 2026-09-11)

> Resumo das decisões e dos números vigentes para a dissertação:
> `base_reescrita_dissertacao.md`.

## 1. Como foi encontrado

O PDF de auditoria (`output_audit/auditoria_eventos_A3.pdf`) foi regenerado para o
catálogo v3 (35 eventos) com uma informação nova por evento: a chuva acumulada nas
6, 12 e 24 h anteriores ao pico, somada da mesma série que alimenta M4/M6 (MERGE
antes de 02/01/2026, Estação-02 depois). Ver `limiares_e_catalogo_v3.md`, Seção 8.

Com isso, o autor fez a inspeção visual de todos os eventos, comparando o nível
bruto com o filtrado. O resultado está na Seção 2.

## 2. Inspeção visual, evento a evento (nível bruto × filtrado)

| Evento | Observação do autor | Classificação |
|---|---|---|
| E01, E02, E04, E05, E08, E10, E18 | Pequena queda do nível logo antes da subida (Seção 7) | Evento real |
| E09 | Nível bruto muito ruidoso; o ruído somado criou uma falsa elevação | **Artefato** |
| E11 | Quatro picos espúrios passaram pelo filtro | Evento real, com ruído residual |
| E12 | Dado faltante antes da subida; queda antes de subir | Evento real |
| E13, E14, E15, E16, E17, E19, E21, E23 | Outliers do bruto agrupados pelo filtro numa falsa subida; chuva zero | **Artefato** |
| E20 | Pico espúrio na descida; subida correta | Evento real |
| E22, E24 | Muito ruidosos; picos negativos não filtrados (E22 tem um pico positivo já na descida) | Evento real, com ruído residual |
| E25 | Dois picos distintos; alguns picos espúrios, positivos na subida | Evento real, com ruído residual |
| E26, E34 | Filtragem correta | Evento real |
| E32, E33 | Quase sem Estação-01 no bruto — série vinda da Estação-03 (87 % e 93 % da janela) | Evento real |
| E35 | Cinco picos em cerca de 12 h | Evento real |

O ruído que passa pelo filtro (E11, E20, E22, E24, E25) é tratado na Issue #228.
Os eventos com vários picos são tratados na Issue #229.

## 3. Premissa física

Conhecimento de campo do autor, que mora no local: **não existe inundação ali sem
chuva** de uma certa intensidade ou duração. Pelo barulho e pela intensidade da chuva,
ele consegue estimar se haverá risco de inundação. Logo, uma subida de nível sem chuva
registrada é um artefato de sensor ou uma falha no dado de precipitação, e nunca uma
cheia sem chuva.

## 4. Regra de exclusão

| Período | Fonte da chuva | Regra |
|---|---|---|
| A partir de 02/01/2026 (janela de 24 h inteira) | Estação-02, pluviômetro no local | Chuva em 24 h antes do pico < 5 mm → artefato, **automático** |
| Antes de 02/01/2026 | MERGE (satélite) | Só por **inspeção visual**, lista explícita no código (E09) |

**Validação.** A regra reproduz exatamente os 9 artefatos da inspeção visual. O único
evento extra que ela marcaria é o E12 (3,7 mm, período MERGE), que visualmente não é
artefato — e por isso a regra não é aplicada automaticamente no período MERGE.

**Por que o MERGE não pode decidir sozinho.** O E04 é uma cheia real de 98 cm com
só 5,3 mm em 24 h no MERGE. Nessa época não havia nem a Estação-02 nem o pluviômetro
de copo. Comparações anteriores já mostravam o MERGE errando o horário da chuva ou não
registrando chuva que houve.

**Por que 24 h e não 6 h.** Com 6 h, o E22 (evento real) seria excluído. A Estação-02
mediu 46 mm entre 00h e 06h de 20/03/2026 e depois ficou **sem leituras de 08h21 a
10h07**, justamente quando o MERGE registrou 4,8 + 4,0 mm. Nas 6 h antes do pico
(12h25), a série do modelo marca 0 mm. Neste caso quem perdeu a chuva foi o
pluviômetro, na lacuna, e não o MERGE.

**Eventos excluídos**

| Evento | Pico (UTC) | Pico (cm) | Chuva em 24 h (mm) | Fonte | Critério |
|---|---|---|---|---|---|
| E09 | 2025-12-26 23:25 | 59 | 1,6 | MERGE | Inspeção visual |
| E13 | 2026-01-05 05:00 | 58 | 0,0 | Estação-02 | Automático |
| E14 | 2026-01-08 09:45 | 74 | 0,0 | Estação-02 | Automático |
| E15 | 2026-01-16 06:10 | 68 | 0,0 | Estação-02 | Automático |
| E16 | 2026-01-17 09:10 | 69 | 0,0 | Estação-02 | Automático |
| E17 | 2026-01-18 03:35 | 69 | 0,8 | Estação-02 | Automático |
| E19 | 2026-02-03 21:15 | 68 | 0,2 | Estação-02 | Automático |
| E21 | 2026-03-13 21:30 | 60 | 0,0 | Estação-02 | Automático |
| E23 | 2026-03-30 03:15 | 52 | 0,0 | Estação-02 | Automático (lacuna de 6h46 na janela, mas 0 mm nas janelas completas de 6 e 12 h) |

Os 9 continuam no `event_windows_v3.csv`, marcados com `split_set = excluded` e
`exclusion = artifact`, com o motivo nas notas. Assim a numeração E01–E35 não muda e
continua batendo com o PDF e com os documentos anteriores. Duas colunas novas:
`p24h_mm` e `exclusion`.

Catálogo resultante: **17 eventos de treino, 9 de teste e 9 excluídos**. Nenhum evento
de teste foi afetado: todos têm pelo menos 18,5 mm em 24 h.

## 5. Por que tirar do catálogo não basta — e o que foi feito

Desde a Issue #223, M4 e M6 treinam em modo contínuo: sobre a série de nível inteira
até `TRAIN_END` (01/05/2026), e não sobre as janelas do catálogo. Tirar os eventos do
catálogo deixaria os artefatos no treino, ensinando ao modelo que o nível pode subir
até 74 cm sem chuva, o que enfraquece justamente a variável que dá antecipação à
previsão.

O que foi implementado (`real_utils.py`, idêntico nas pastas M4 e M6):

1. **Série de nível.** `load_real_data()` apaga o nível dentro das janelas de análise
   dos eventos com `exclusion = artifact`: 813 passos de 5 min (cerca de 68 h). O resto
   da série fica idêntico.
2. **Treino.** `build_continuous_training_segment()` preenchia qualquer lacuna repetindo
   o último valor válido, o que pintaria um nível plano inventado no lugar do artefato.
   Agora o período de treino é dividido em **10 trechos contínuos** em volta das 9
   janelas, e os modelos são ajustados sobre a lista de trechos, sem dado inventado. O
   treino passou de 140.013 para 139.200 passos.
3. **Inferência.** `mask_artifact_rows()` apaga o observado e as previsões dos dois
   modelos dentro das janelas. O M6 preenche as próprias entradas para prever, então
   sem isso ele teria previsões sobre um trecho que não é nível de rio. As janelas ficam
   fora de todas as métricas e da simulação de alertas.
4. **Catálogo.** `build_event_catalogue.py` calcula a chuva de 24 h de cada episódio
   (`real_utils.load_precip_5min()`, a mesma série dos modelos) e aplica a regra da
   Seção 4. Uma chave da lista manual que deixe de corresponder a um episódio após uma
   reconstrução gera aviso, em vez de ser ignorada em silêncio.
5. **PDF de auditoria.** Os 35 eventos continuam no relatório. Os 9 excluídos aparecem
   com selo vermelho "EXCLUÍDO" e um aviso explicando que o trecho foi removido. O
   painel filtrado mostra o que foi removido.

## 6. Resultado — métricas antes e depois

**Comparação justa.** Os artefatos estavam todos no período de treino. No registro
inteiro, eles contavam como "eventos" (um alerta dentro deles era verdadeiro positivo) e
tinham erros grandes, então os números do registro inteiro mudam só porque os artefatos
saíram. A comparação abaixo usa apenas o **período fora da amostra (a partir de
01/05/2026)**, com os mesmos instantes e os mesmos 9 eventos de teste antes e depois.
A REQM segue a definição de `scan_audit_findings.py --calibration`.

### 6.1 REQM fora da amostra (cm) — 37.857 a 37.893 passos

| Modelo | +30 | +60 | +90 | +120 |
|---|---|---|---|---|
| M4 antes → depois | 1,02 → 1,05 | 1,66 → 1,65 | 2,11 → 2,11 | 2,50 → 2,55 |
| M6 antes → depois | 0,80 → **0,72** | 1,39 → **1,28** | 1,89 → **1,80** | 2,32 → **2,24** |

- **M6 melhora em todos os horizontes**, de 0,08 a 0,11 cm (4 a 10 %), e o viés negativo
  diminui (+120: −0,67 → −0,63 cm).
- **M4 fica igual:** variação de ±0,05 cm, dentro do ruído.
- A REQM média por evento de teste segue o mesmo padrão: M6 cai de 1,99 para 1,71 cm em
  +30 e de 6,27 para 6,04 em +120; o M4 fica praticamente igual (2,46 → 2,52; 6,11 → 6,22).

### 6.2 Alarme no período de teste (persistência de 3 passos = 15 min)

| Modelo | Atenção 60 (VP/FP/FN) | Alerta 75 | Inundação 90 |
|---|---|---|---|
| M4 antes | 8 / 1 / 0 | 4 / 0 / 1 | 1 / 0 / 2 |
| M4 depois | 8 / 1 / 0 | 5 / 1 / 0 | 1 / 0 / 2 |
| M6 antes | 6 / 0 / 2 | 4 / 0 / 1 | 2 / 0 / 1 |
| M6 depois | **7 / 0 / 1** | **5 / 0 / 0** | **3 / 0 / 0** |

O M6 passa a detectar todos os eventos de teste em Alerta e em Inundação, sem nenhum
falso alarme. O M4 ganha um acerto em Alerta, mas também um falso alarme, e continua sem
alcançar Inundação em 2 de 3 eventos.

### 6.3 Lead time em Inundação (min, horizontes +30 / +60 / +90 / +120)

| Evento | M4 antes | M4 depois | M6 antes | M6 depois |
|---|---|---|---|---|
| E31 (97 cm) | nunca previu | nunca previu | −5 / −20 / −20 / −35 | **+5 / −5 / −5 / −5** |
| E33 (92 cm) | −60 / — / — / — | −60 / −30 / — / — | 0 / −5 / — / — | 0 / 0 / −5 / −5 |
| E35 (101 cm) | nunca previu | −50 / — / — / — | 0 / −15 / −15 / −15 | **+5 / 0 / 0 / 0** |

Em Alerta, os lead times do M6 também sobem para perto de zero (E32 e E35: de −15 para
0 min até +90), e os do M4 continuam positivos (de +10 a +145 min).

**Leitura.** A limitação central registrada em `limiares_e_catalogo_v3.md` §5.3
continua: **em Inundação, nenhum modelo antecipa de fato.** Mas o M6 deixa de avisar
atrasado (até −35 min) e passa a avisar em cima da hora (−5 a +5 min) em todos os 3
eventos.

O ganho concentrado no M6 é coerente com o mecanismo descrito na Seção 5: um modelo
linear usa os mesmos coeficientes no registro inteiro, e subidas sem chuva no treino
puxavam para baixo o peso da precipitação. Árvores (M4) conseguem isolar essas regiões,
então sofriam menos. É uma interpretação plausível, ainda não verificada diretamente (por
exemplo, comparando os coeficientes de chuva do M6 antes e depois).

### 6.4 Instabilidade do lead time do M4

Com o retreino, 37 valores de lead time do M4 nos eventos de teste mudaram, alguns em
mais de 3 horas: no E30, Atenção em +90 foi de −30 para +175 min; no E34, de 0 para
+180 min. O painel +90 min do E34 (PDF, Página B) mostra a causa. O "cruzamento
previsto" é um **pico isolado** da previsão do M4 às 11h35, no meio de uma curva ruidosa,
e não uma antecipação sustentada.

O cálculo de lead time usa o primeiro instante em que a previsão toca o limiar, sem
exigir persistência. A análise de alarme exige 15 min seguidos. Valores de lead time
próximos do limite de causalidade (180 min) devem ser conferidos no PDF antes de serem
citados. A correção (exigir persistência também no cruzamento previsto) foi registrada
na Issue #229, que já revisa a regra de cruzamento.

### 6.5 Registro inteiro (referência — a população mudou)

| | M4 antes | M4 depois | M6 antes | M6 depois |
|---|---|---|---|---|
| REQM +30 (cm) | 1,053 | 1,003 | 1,215 | 0,971 |
| REQM +120 (cm) | 1,875 | 1,827 | 2,366 | 2,239 |

Alarme no registro inteiro, depois (persistência de 15 min):

| Modelo | Limiar | VP | FP | FN | Precisão | Recall | F1 |
|---|---|---|---|---|---|---|---|
| M4 | Atenção 60 | 17 | 8 | 0 | 0,680 | 1,000 | 0,810 |
| M4 | Alerta 75 | 10 | 2 | 0 | 0,833 | 1,000 | 0,909 |
| M4 | Inundação 90 | 4 | 0 | 2 | 1,000 | 0,667 | 0,800 |
| M6 | Atenção 60 | 16 | 4 | 1 | 0,800 | 0,941 | 0,865 |
| M6 | Alerta 75 | 10 | 1 | 0 | 0,909 | 1,000 | 0,952 |
| M6 | Inundação 90 | 6 | 0 | 0 | 1,000 | 1,000 | 1,000 |

Não compare estas contagens com a tabela anterior da §5.2 de
`limiares_e_catalogo_v3.md`: lá, os artefatos contavam como eventos a detectar.

## 7. A queda antes da subida

Em vários eventos o nível cai um pouco imediatamente antes de subir. Medindo a queda na
1,5 h anterior ao início da subida, em todos os eventos:

| Série | Queda média | Eventos com queda ≥ 2 cm |
|---|---|---|
| Bruto (mediana de 5 min, sem filtro) | 0,5 cm | 6 |
| Filtrado (o que alimenta os modelos) | 0,7 cm | 7 |
| Estação-03 (US-100), onde há dado | ≤ 1 cm | 0 |

- A queda, de 1,5 a 3 cm, **já está no dado bruto** (E01–E03, E08, E10, E18). Não é
  efeito de plotagem nem, na maioria dos casos, do filtro.
- **Exceção — E05:** no início da subida, o sensor soltou um pico alto (139 cm) junto
  com leituras baixas (26 e 30 cm; linha de base 33 cm). O filtro rejeitou o pico alto
  (salto maior que 40 cm), mas não as leituras baixas (só ~7 cm abaixo), e a média de
  5 min puxou o nível para 28,7 cm. O mesmo par alto + baixo aparece no E10.
- **Causa física não estabelecida.** A hipótese de resfriamento do ar pela chuva
  afetando o HC-SR04 (sem compensação de temperatura) não foi confirmada: a queda não
  aparece nos eventos de 2026 em nenhuma das estações, e a temperatura (medida em graus
  inteiros) não acompanha.
- Impacto pequeno (1,5 a 3 cm em cerca de 7 de 35 eventos). Registrado na Issue #228.

## 8. Pendências relacionadas

- **Issue #228** — redesenho do filtro. Rajadas e picos, positivos e negativos, ainda
  passam. Premissa do autor: o nível de um rio nunca varia bruscamente num intervalo
  curto, nem para cima nem para baixo. Discussão ainda aberta: Kalman, filtro secundário
  ou restrição física de taxa de variação.
- **Issue #229** — lead time por ocorrência de cruzamento de limiar, para eventos com
  vários picos (E25, E31, E33, E34, E35). A folga de reativação a comparar é de 5, 8 ou
  10 cm.
- **Produção.** `production/` ainda treina só com janelas de evento (pendência da
  #223). A remoção dos artefatos precisa acompanhar quando a produção for retreinada.

## 9. Reprodução

```bash
cd predictive-models/
V=/home/ilha3d/SAPI/LightGBM_Production/.venv/bin/python3

$V build_event_catalogue.py                       # regra de exclusão -> event_windows_v3.csv
(cd results_final_m6_mlr && $V 01_model6_mlr_continuous.py)
(cd results_final_m4_lgbm && $V 01_model4_continuous.py)
(cd results_final_m4_lgbm && $V 04_lead_time_m4.py)
(cd results_final_m6_mlr  && $V 04_lead_time_m6.py && $V 05_rmse_per_event.py && $V 06_compare_fullsim.py)
$V scan_audit_findings.py --calibration
$V plot_events_audit_pdf.py
```

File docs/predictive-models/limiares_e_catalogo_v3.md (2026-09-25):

# Recalibração dos limiares e reconstrução do catálogo — Issue #225 (2026-09-09)

*Complementa `lead_time_horizontes_longos_investigacao.md` (Issue #223, viés de treino).
Aquela correção arrumou **como** o modelo era treinado; esta arruma **contra o que** ele é
avaliado.*

## 1. A linha de base do rio não é estacionária

| Estação-01 | Mediana | p90 | % do tempo ≥45 cm | % ≥50 cm |
|---|---|---|---|---|
| jul/2025 | 29 cm | 32 cm | 0 % | 0 % |
| dez/2025 | 35 cm | 42 cm | 8,3 % | 4,5 % |
| abr/2026 | 39 cm | 48 cm | 23,6 % | 6,6 % |
| jul/2026 | **45 cm** | 49 cm | **54,4 %** | 9,5 % |
| set/2026 | **47 cm** | 58 cm | **74,2 %** | **32,3 %** |

Subida de ~18 cm em 14 meses. A Estação-03 confirma: mediana de 50 cm em setembro,
acima de 45 cm 100 % do tempo. Como são **instrumentos diferentes medindo a mesma
água**, a concordância descarta deriva de instrumento — a subida está no rio. De maio a
setembro a E01 subiu +7,0 cm e a E03 +8,0 cm; se fosse artefato do sensor não
compensado da E01, ela teria subido *mais*, não menos.

**Consequência**: os limiares de 50/60/75 cm ficaram sem significado uniforme. Em
jul/2025 os 50 cm estavam 21 cm acima da mediana; em set/2026, 3 cm — e eram
ultrapassados 31 % do tempo. Deixaram de separar evento de escoamento normal.

## 2. Novos limiares: 60 / 75 / 90 cm

Escolhidos sobre a distribuição dos 42 episódios de dez/2024 a set/2026, ancorados nas
descontinuidades naturais em vez de números redondos:

```
162, 101, 101, 98, 97 │ 84, 79, 77, 75, 74 │ 69 ... 60 │ 59 ... 45
                       ↑ vão de 13 cm       ↑ vão de 5 cm
```

| Limiar | Eventos | Treino | Teste | % do tempo acima em set/26 |
|---|---|---|---|---|
| Atenção 60 cm | 23 | 16 | 7 | 9,0 % |
| Alerta 75 cm | 9 | 6 | 3 | 2,8 % |
| Inundação 90 cm | 5 | 3 | 2 | 1,1 % |

Qualquer valor entre 85 e 96 cm seleciona os mesmos 5 eventos maiores; 90 foi escolhido
por coincidir com a Atenção do sistema operacional, criando ponte entre a escala de
avaliação e a de alerta real.

**Os limiares são fixos por princípio.** Uma estação hidrometeorológica não move seus
níveis de alerta entre anos secos e chuvosos. A deriva da base fica documentada como
limitação, não é compensada.

**Trocar limiar não exige retreinar.** Os modelos preveem nível em centímetros; os
limiares entram depois, onde previsão vira alerta. Mudá-los re-roda os scripts de
avaliação, nunca o treino. Isso viabiliza um controle de operador para esses níveis,
ajustando-os em direção aos estágios reais à medida que o histórico cresce — registrado
aqui para virar requisito rastreável.

## 3. Detecção de episódios por amplitude, não por magnitude absoluta

Com a base derivando, um corte fixo se comporta de forma completamente diferente nas
duas pontas do registro. A 45 cm o detector devolveu **133 "eventos"**, 112 deles em
2026, pico mediano de 46 cm, alguns durando 11 dias — estava rastreando fluxo normal.

`build_event_catalogue.py` segmenta por **amplitude ≥12 cm sobre a mediana móvel de 7
dias**. Isso é dispositivo de recorte, não limiar: decide onde um episódio começa e
termina; os níveis de alerta seguem absolutos e o campo `level` sai deles.

Os dois critérios concordam no registro atual (31 eventos por absoluto ≥55 cm contra 36
por amplitude ≥15 cm, mesmo pico mediano de 65–66 cm nos dois anos), o que é o argumento
de que o limiar fixo continua defensável apesar da deriva.

`flash_flood` passa a ser decidido por taxa de subida ≥50 cm/h em 30 min, calibrada
contra os rótulos do v2: os três casos inequívocos atingem 67,9 / 70,5 / 155,0 cm/h
contra 32,0 da cheia gradual mais rápida. Isso reclassifica o E05 do v2 como `flood` —
ele mede 8,0 cm/h na própria janela, tendo herdado o rótulo do episódio do qual foi
separado.

**Catálogo v3: 35 episódios, 26 treino / 9 teste** (`event_windows_v3.csv`).

## 4. Emenda das lacunas da E01 com a E03

A Estação-01 ficou fora do ar de 13 a 16 de agosto (zero leituras) para conserto de
hardware, mais falhas parciais em 06, 07, 09, 10, 12 e 17 — exatamente durante os
maiores eventos de agosto, que a E03 registrou.

| | Cobertura (mai–set) | Maior lacuna |
|---|---|---|
| E01 sozinha | 93,6 % | **120,6 h** |
| E03 sozinha | 91,7 % | 44,3 h |
| **E01 ou E03** | **99,5 %** | — |

As lacunas quase não coincidem. **Redundância de estação leva a disponibilidade de
93,6 % para 99,5 %** — resultado de engenharia citável, e argumento direto a favor de o
projeto ter duas estações de cota.

### 4.1 Offset por faixa, não constante

| Faixa | n | Offset (E03 − E01) |
|---|---|---|
| 0–50 cm | 35.216 | **+2,00** |
| 50–60 cm | 4.030 | +2,00 |
| 60–75 cm | 1.026 | +1,00 |
| 75–90 cm | 265 | **−0,75** |
| ≥90 cm | 56 | **−1,80** |

A E01 lê progressivamente mais alto em relação à E03 conforme o rio sobe, invertendo o
sinal em cota de cheia. **Isso tem causa física**: a única régua linimétrica está
parafusada embaixo da E03; a E01 fica 30 m a montante, mais perto da chegada da água,
onde a superfície é mais turbulenta durante cheias. Um HC-SR04 sem compensação lendo
superfície agitada retorna o eco forte mais próximo — a crista de uma onda — e portanto
superestima o nível, tanto mais quanto mais agitada a superfície.

Isso **reconcilia a tabela de validação por régua com as estatísticas de sobreposição**:
o +2,65 cm da régua para a E01 vem de 26 leituras ponderadas para dias de inundação,
enquanto o +2,00 cm da sobreposição reflete as condições ordinárias que dominam o
registro. Os dois medem regimes diferentes, não se contradizem.

Validação cruzada em 5 blocos temporais:

| Método | REQM global | REQM ≥70 cm | Viés ≥70 cm |
|---|---|---|---|
| Constante | 2,58 | 4,10 | **−2,23** |
| **Por faixa** | 2,64 | **3,36** | **−0,02** |
| Regressão linear | 2,86 | 5,52 | −4,31 |

Escolher pelo REQM global escolheria errado. O offset por faixa é marginalmente pior no
global e decisivamente melhor onde a emenda é usada. **Isso mudou o E33 de 88 para
92 cm, ou seja de Alerta para Inundação.**

### 4.2 Proveniência é gravada

A lacuna está no período de **teste**, então um valor preenchido não é só entrada do
modelo — é a verdade contra a qual ele é pontuado. Cada amostra carrega `source` e cada
linha do catálogo carrega `donor_pct`.

Contexto que relativiza a ressalva: contra a régua, a **E01 tem REQM de 4,04 cm e viés
de +2,65 cm** (n=26), contra 0,90 / +0,40 da E03 (n=5). O resíduo de ~3,3 cm da emenda
**não é pior que o erro de medição da própria série hospedeira**. As colunas de
proveniência são transparência, não sinal de dado inferior. Qualquer evento a menos de
~4 cm de um limiar está dentro da incerteza instrumental, preenchido ou não.

A E01 segue como referência **por antiguidade de série, não por qualidade metrológica**:
20 meses contra 6 da E03, que é o instrumento calibrado e compensado.

## 5. Métricas finais

> **Atualização (2026-09-11, Issue #227):** os números desta seção são anteriores à
> exclusão dos 9 eventos que eram artefato de sensor (E09, E13–E17, E19, E21, E23) e à
> remoção desses trechos do treino. Os valores vigentes estão em
> `artefatos_catalogo_v3.md`, Seção 6. Resumo: o M6 melhora em todos os horizontes fora
> da amostra, e em Inundação passa a detectar os 3 eventos de teste em cima da hora; o M4
> fica igual. A conclusão da §5.3 (nenhum modelo antecipa em Inundação) continua valendo.

### 5.1 Calibração fora da amostra (37.857 passos, mai–set/2026)

| Modelo | Horiz. | Viés | REQM | Previsto ≥60 cm | Observado |
|---|---|---|---|---|---|
| M4 | +30 | −0,16 | 1,02 | 4,69 % | 5,15 % |
| M4 | +120 | −0,52 | 2,50 | 3,79 % | 5,16 % |
| M6 | +30 | −0,19 | **0,80** | 4,87 % | 5,15 % |
| M6 | +120 | −0,67 | **2,32** | 4,44 % | 5,16 % |

Viés levemente **negativo**, crescente com o horizonte: os modelos subestimam um pouco.
Lado seguro para REQM, não para alarme.

**Fora da amostra o M6 vence em todos os horizontes.** Na simulação completa o M4
aparece melhor (1,05 contra 1,22 em +30), mas isso é ajuste dentro da amostra — ali o M4
faz 0,77 contra 1,31 do M6. Qualquer afirmação de desempenho relativo deve citar a
métrica fora da amostra, de `scan_audit_findings.py --calibration`.

### 5.2 Alarme operacional (debounce 3 passos / 15 min)

| Modelo | Limiar | VP | FP | FN | Precisão | Recall | F1 |
|---|---|---|---|---|---|---|---|
| M4 | Atenção 60 | 19 | 7 | 4 | 0,731 | 0,826 | 0,776 |
| M4 | Alerta 75 | 9 | 1 | 1 | 0,900 | 0,900 | 0,900 |
| M4 | Inundação 90 | 4 | 0 | 2 | 1,000 | 0,667 | 0,800 |
| M6 | Atenção 60 | 20 | 4 | 3 | 0,833 | 0,870 | 0,851 |
| M6 | Alerta 75 | 9 | **0** | 1 | **1,000** | 0,900 | **0,947** |
| M6 | Inundação 90 | 5 | **0** | 1 | **1,000** | 0,833 | **0,909** |

### 5.3 Limitação central: no nível mais alto não há antecipação

| Evento | M4 Inundação (90 cm) | M6 Inundação (90 cm) |
|---|---|---|
| E31 (97 cm) | **nunca previu** | −5 / −20 / −20 / −35 min |
| E33 (92 cm) | −60 min | 0 / −5 / — / — |
| E35 (101 cm) | **nunca previu** | 0 / −15 / −15 / −15 min |

**O M4 não alcança o limiar de 90 cm nas previsões** (2 falsos negativos de 3 eventos).
**O M6 alcança, mas avisa em cima da hora ou atrasado** — todos os lead times ≤0.

Em Alerta o M4 antecipa de verdade (0 a 75 min) enquanto o M6 é sistematicamente
negativo (−5 a −15 min). Resumindo: **o M4 antecipa quando avisa, mas falha em avisar; o
M6 quase nunca falha em detectar, mas praticamente não antecipa.**

Isso é consequência direta de a calibração ter sido corrigida. O viés positivo antigo
produzia "antecipação" porque o modelo vivia acima do limiar; removido o viés, aparece o
que o modelo de fato consegue — e no extremo superior ele rastreia em vez de antecipar.

## 6. Comparabilidade

Os números aqui **não são comparáveis** aos anteriores à Issue #225: mudaram os limiares
(50/60/75 → 60/75/90), o corte de treino (fev → mai/2026), o catálogo (20 curados à mão
→ 35 segmentados) e a série de nível (com emenda). A única comparação limpa antes/depois
é a do PR #224, restrita aos mesmos instantes fora da amostra.

## 7. Reprodução

```bash
cd predictive-models/
V=/home/ilha3d/SAPI/LightGBM_Production/.venv/bin/python3

# 1) dump novo -> CSVs por estação (usa o venv de predictive_model, que tem dotenv)
../predictive_model/.venv/bin/python3 ../predictive_model/00_load_sql_dump.py \
    /home/ilha3d/SAPI/DB/<dump>.sql

# 2) filtro de 3 passes da Issue #211
$V reprocess_level_spike_return_filter.py

# 3) emenda com a E03 (lê o corrigido, escreve o gapfilled)
$V build_gapfilled_level.py

# 4) catálogo
$V build_event_catalogue.py

# 5) modelos (M6 ~5 min, M4 ~25 min no RPi)
(cd results_final_m6_mlr && $V 01_model6_mlr_continuous.py)
(cd results_final_m4_lgbm && $V 01_model4_continuous.py)

# 6) métricas
(cd results_final_m4_lgbm && $V 04_lead_time_m4.py)
(cd results_final_m6_mlr  && $V 04_lead_time_m6.py && $V 05_rmse_per_event.py && $V 06_compare_fullsim.py)
$V scan_audit_findings.py --calibration

# 7) PDF de auditoria + chuva acumulada (~4 min, o parsing do dump domina)
$V plot_events_audit_pdf.py
```

**Armadilha**: `config.LEVEL_CSV` aponta para a *saída* do `build_gapfilled_level.py`.
Esse script usa `HOST_CSV` explícito para não ler o próprio resultado. Não troque por
`config.LEVEL_CSV`.

## 8. Chuva acumulada antes do pico (PDF de auditoria, 2026-09-11)

`plot_events_audit_pdf.py` regenera `output_audit/auditoria_eventos_A3.pdf` para os 35
eventos (72 páginas) e imprime, no cabeçalho de cada evento e em três colunas do
catálogo, a chuva acumulada nas 6, 12 e 24 h anteriores ao pico catalogado. A tabela
também sai em `output_audit/precip_acumulada_eventos.csv`.

- **Fonte**: a mesma série de 5 min que alimenta M4/M6 (`real_utils.load_real_data()`):
  MERGE antes de 02/01/2026, Estação-02 depois. Soma dos passos em (pico − H, pico].
- **Cobertura**: o pipeline preenche falta de dado, então 0 mm pode ser ausência de dado.
  O script marca com `*` as janelas com lacuna na fonte — Estação-02 com intervalo entre
  leituras > 30 min (a falta vira 0 mm) ou hora MERGE ausente (o `ffill` repete a hora
  anterior). Marcados: E02 e E11 (MERGE, 5 h e 1 h; efeito ≤0,1 mm), E22 (1h46), E23
  (6h46) e E33 (48 min) na Estação-02.

**Achado**: oito eventos têm ≤0,8 mm nas 24 h antes do pico — E13, E14, E15, E16, E17,
E19, E21 e E23 — e só o E23 com lacuna na fonte. Todos estão no conjunto de treino. No
E14 (74 cm, tipo enxurrada) e no E23 o nível bruto alterna em degraus quadrados entre a
linha de base e ~50–74 cm, o padrão de eco do HC-SR04 da Issue #211, e o degrau passa
pelo filtro. Os demais ainda precisam de inspeção visual nas Páginas A. Se confirmados
como artefato, são episódios de sensor, e não de cheia, dentro do catálogo e do treino.

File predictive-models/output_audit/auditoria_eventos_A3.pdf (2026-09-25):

# SAPI — Relatório de Auditoria Visual

## Eventos de Treino e Teste — Lead Time e RMSE (M4 LightGBM vs. M6 MLR)

## O que é este relatório

Auditoria visual e numérica dos 37 eventos de cheia catalogados em event_windows_v3.csv (17 de treino, 11 de teste, 9 excluídos como artefato de sensor). Para cada evento, mostra o nível bruto medido, o nível filtrado que alimenta os modelos, a chuva antes do pico e as previsões dos modelos M4 (LightGBM) e M6 (regressão linear), para verificar se o dado está limpo, se o evento é explicado por chuva e se os modelos antecipam a cheia.

## Como ler as páginas de cada evento

Página A — nível bruto (em cima) e nível filtrado (embaixo), com os três limiares de alerta e o pico do evento marcados.

Página B — tabela de erro (RMSE) e de tempo de antecipação, seguida de 4 gráficos, um por horizonte de previsão (+30, +60, +90 e +120 min), comparando o nível real com a previsão de cada modelo.

Chuva — o cabeçalho traz a chuva acumulada nas 6, 12 e 24 h antes do pico. Um * e um aviso em vermelho indicam falha de dado na fonte de chuva.

Excluídos — episódios que não são cheia, e sim leituras falsas do sensor (sem chuva). Aparecem no relatório para conferência, mas ficaram fora do treino e das métricas.

Subida máx. 30 min — a maior subida do nível em qualquer intervalo de 30 min do evento, e não a média da subida inteira (E08: 78 cm em 30 min, numa subida total de 129 cm em 1h15). É Enxurrada quando chega a 25 cm.

O selo no canto de cada página indica o conjunto do evento:
TREINO | TESTE | EXCLUÍDO

ATENÇÃO: UM EVENTO PODE TER MAIS DE UM CRUZAMENTO DE LIMIAR. Cada evento do catálogo é uma cheia completa, que pode ter vários picos. Sempre que o nível cruza um limiar, desce pelo menos 5 cm abaixo dele e volta a cruzá-lo, isso conta
como um novo cruzamento, numerado #1, #2, #3... Cada cruzamento tem o seu próprio tempo de antecipação: na tabela da Página B há uma linha para cada um, com o horário em que o nível cruzou; nos gráficos, o número aparece ao lado do ●.
Exemplo — Evento 31: o nível passou de 90 cm às 13:10, desceu a 81 cm e voltou a passar de 90 cm às 20:10, resultando em Inundação #1 e Inundação #2.

## Tempo de antecipação (lead time)

É a diferença entre o horário em que o nível real cruzou o limiar (●) e o horário em que o alarme do modelo disparou (▲ M4, ▼ M6). O alarme dispara quando a previsão fica acima do limiar por 15 min seguidos, como no sistema em operação. Valor positivo = o modelo avisou antes do cruzamento; negativo = avisou depois; — = o modelo não alarmou para aquele cruzamento. O sinal ≥ indica que o alarme já estava ligado quando começou a busca, que vai até 180 min antes do cruzamento.

## Configuração que gerou estes números

Limiares | Atenção 60 cm, Alerta 75 cm, Inundação 90 cm
Horizontes de previsão | +30 min, +60 min, +90 min, +120 min
Treino / teste | treino no registro contínuo até 01/05/2026 (sem os artefatos); teste depois dessa data
Cruzamentos e alarme | novo cruzamento após descer 5 cm; alarme após 15 min acima do limiar; busca até 180 min antes
Chuva | MERGE (satélite) até 01/01/2026, sem correção de escala (fator 1,0); depois, Estação-02, cada transmissão de 15 min repartida em 3 passos de 5 min
Nível | Estação-01 (sensor HC-SR04), filtro de picos em 3 passes; falhas preenchidas com a Estação-03
Dado bruto | dump SQL dump_20260912.sql

## Códigos que geraram os dados deste relatório

reprocess_level_spike_return_filter.py — Reprocessa o nível bruto (Issue #211): filtro elástico de produção + filtro de 40cm + spike-and-return. build_gapfilled_level.py — Preenche as falhas da Estação-01 com a Estação-03, com offset por faixa de nível e proveniência (Issue #225). build_event_catalogue.py — Reconstrói o catálogo de eventos a partir da série corrigida (Issue #225).
results_final_m4_lgbm/01_model4_continuous.py — Treina o M4 (LightGBM) e roda a inferência contínua. results_final_m6_mlr/01_model6_mlr_continuous.py — Treina o M6 (Regressão Linear) e roda a inferência contínua. results_final_m4_lgbm/lead_time_utils.py — Regra do tempo de antecipação por cruzamento, usada pelos scripts abaixo e por este relatório (Issue #229). 04_lead_time_m4.py / 04_lead_time_m6.py — Calculam o tempo de antecipação de cada cruzamento, por modelo e horizonte. results_final_m6_mlr/05_rmse_per_event.py — Calcula o RMSE por evento nos eventos de teste.
plot_events_audit_pdf.py — Gera este relatório.
scan_audit_findings.py — Varredura automática de achados (divergências, outliers, lead times extremos).

Gerado em: 2026-09-12 15:19 — AppTest/raspberry/predictive_model_darts/ (branch feature/catalogue-v3-e36)

Capa e catálogo somam 2 páginas, para que as Páginas A e B de cada evento fiquem lado a lado na visualização "2 páginas por vez".

Evt | Início análise | Fim análise | Pico (UTC) | Pico (cm) | Conjunto | Tipo | Subida máx. 30 min (cm) | Nível atingido | P6h | P12h | P24h | Notas
01 | 2025-01-16 21:45 | 2025-01-18 18:50 | 2025-01-17 14:35 | 79 | Treino | Cheia | 7 | Alerta | 53.0 | 96.1 | 192.6
02 | 2025-01-25 17:55 | 2025-01-26 07:45 | 2025-01-26 00:05 | 66 | Treino | Cheia | 6 | Atenção | 25.8 | 25.8* | 52.5*
03 | 2025-02-17 22:10 | 2025-02-18 08:05 | 2025-02-18 03:30 | 48 | Treino | Cheia | 1 | Normal | 18.8 | 19.3 | 20.7
04 | 2025-04-10 14:15 | 2025-04-11 22:55 | 2025-04-10 19:35 | 98 | Treino | Enxurrada | 34 | Inundação | 4.5 | 4.7 | 5.3
05 | 2025-06-23 03:55 | 2025-06-23 22:20 | 2025-06-23 10:10 | 56 | Treino | Cheia | 5 | Normal | 3.2 | 4.5 | 5.4
06 | 2025-06-26 16:00 | 2025-06-27 09:00 | 2025-06-26 22:25 | 58 | Treino | Cheia | 6 | Normal | 4.3 | 6.1 | 6.9
07 | 2025-10-29 00:55 | 2025-10-29 09:25 | 2025-10-29 06:00 | 45 | Treino | Cheia | 1 | Normal | 16.6 | 19.6 | 19.6
08 | 2025-12-09 09:55 | 2025-12-10 18:35 | 2025-12-09 15:00 | 163 | Treino | Enxurrada | 78 | Inundação | 27.3 | 31.5 | 31.5
09 | 2025-12-26 19:25 | 2025-12-27 02:25 | 2025-12-26 23:25 | 59 | Excluído | Cheia | 0 | Normal | 1.2 | 1.4 | 1.6 | ARTEFATO: nível bruto muito ruidoso; o ruído somado pelo filtro criou uma falsa…
10 | 2025-12-29 18:15 | 2025-12-30 18:00 | 2025-12-29 23:10 | 101 | Treino | Enxurrada | 35 | Inundação | 9.7 | 11.0 | 20.3
11 | 2025-12-30 21:50 | 2025-12-31 16:35 | 2025-12-31 11:30 | 58 | Treino | Cheia | 10 | Normal | 3.1 | 5.4* | 6.7*
12 | 2026-01-01 17:10 | 2026-01-02 05:50 | 2026-01-01 22:55 | 58 | Treino | Cheia | 3 | Normal | 3.5 | 3.6 | 3.7
13 | 2026-01-05 01:00 | 2026-01-05 07:40 | 2026-01-05 05:00 | 58 | Excluído | Cheia | 0 | Normal | 0.0 | 0.0 | 0.0 | ARTEFATO: 0.0 mm em 24 h antes do pico (Estação-02) (Issue #227)
14 | 2026-01-08 03:20 | 2026-01-08 12:10 | 2026-01-08 09:45 | 74 | Excluído | Enxurrada | 34 | Atenção | 0.0 | 0.0 | 0.0 | ARTEFATO: 0.0 mm em 24 h antes do pico (Estação-02) (Issue #227)
15 | 2026-01-16 01:50 | 2026-01-16 10:25 | 2026-01-16 06:10 | 68 | Excluído | Cheia | 0 | Atenção | 0.0 | 0.0 | 0.0 | ARTEFATO: 0.0 mm em 24 h antes do pico (Estação-02) (Issue #227)
16 | 2026-01-17 05:10 | 2026-01-17 11:40 | 2026-01-17 09:10 | 69 | Excluído | Cheia | 0 | Atenção | 0.0 | 0.0 | 0.0 | ARTEFATO: 0.0 mm em 24 h antes do pico (Estação-02) (Issue #227)
17 | 2026-01-17 23:25 | 2026-01-18 06:05 | 2026-01-18 03:35 | 69 | Excluído | Cheia | 0 | Atenção | 0.0 | 0.8 | 0.8 | ARTEFATO: 0.8 mm em 24 h antes do pico (Estação-02) (Issue #227)
18 | 2026-01-18 18:20 | 2026-01-19 09:00 | 2026-01-19 00:40 | 63 | Treino | Cheia | 6 | Atenção | 42.4 | 42.4 | 42.4
19 | 2026-02-03 17:10 | 2026-02-03 23:40 | 2026-02-03 21:15 | 68 | Excluído | Cheia | 0 | Atenção | 0.2 | 0.2 | 0.2 | ARTEFATO: 0.2 mm em 24 h antes do pico (Estação-02) (Issue #227)
20 | 2026-02-24 23:35 | 2026-02-25 15:50 | 2026-02-25 05:10 | 68 | Treino | Cheia | 6 | Atenção | 23.2 | 23.2 | 28.5
21 | 2026-03-13 17:20 | 2026-03-13 23:55 | 2026-03-13 21:30 | 60 | Excluído | Cheia | 0 | Normal | 0.0 | 0.0 | 0.0 | 8% da janela vem da E03 (Issue #225); ARTEFATO: 0.0 mm em 24 h antes do pico (Estação-02)…
22 | 2026-03-20 00:50 | 2026-03-20 14:35 | 2026-03-20 12:25 | 62 | Treino | Cheia | 11 | Atenção | 0.0* | 46.0* | 46.0* | 2% da janela vem da E03 (Issue #225)
23 | 2026-03-29 23:00 | 2026-03-30 08:40 | 2026-03-30 03:15 | 52 | Excluído | Cheia | 0 | Normal | 0.0 | 0.0 | 0.0* | 3% da janela vem da E03 (Issue #225); ARTEFATO: 0.0 mm em 24 h antes do pico (Estação-02),…
24 | 2026-04-06 09:05 | 2026-04-07 05:20 | 2026-04-06 15:25 | 59 | Treino | Cheia | 4 | Normal | 26.3 | 27.3 | 43.6 | 2% da janela vem da E03 (Issue #225)
25 | 2026-04-07 05:20 | 2026-04-08 23:20 | 2026-04-08 04:25 | 84 | Treino | Cheia | 16 | Alerta | 25.0 | 25.0 | 47.1 | 5% da janela vem da E03 (Issue #225)
26 | 2026-04-26 10:40 | 2026-04-26 21:45 | 2026-04-26 15:50 | 49 | Treino | Cheia | 2 | Normal | 33.2 | 35.8 | 35.8
27 | 2026-05-09 17:55 | 2026-05-10 01:30 | 2026-05-09 22:15 | 54 | Teste | Cheia | 0 | Normal | 15.4 | 18.9 | 44.4 | 1% da janela vem da E03 (Issue #225)
28 | 2026-06-20 15:35 | 2026-06-21 02:40 | 2026-06-20 21:30 | 60 | Teste | Cheia | 4 | Atenção | 35.5 | 38.7 | 38.9
29 | 2026-06-30 04:20 | 2026-07-01 01:55 | 2026-06-30 12:25 | 65 | Teste | Cheia | 3 | Atenção | 20.0 | 30.6 | 30.6
30 | 2026-07-01 03:50 | 2026-07-02 00:50 | 2026-07-01 12:50 | 61 | Teste | Cheia | 2 | Atenção | 10.6 | 16.2 | 18.2
31 | 2026-07-11 07:35 | 2026-07-12 20:10 | 2026-07-11 13:40 | 97 | Teste | Cheia | 17 | Inundação | 43.2 | 43.2 | 47.2 | 1% da janela vem da E03 (Issue #225)
32 | 2026-08-12 11:40 | 2026-08-13 12:00 | 2026-08-12 19:55 | 80 | Teste | Cheia | 9 | Alerta | 37.0 | 40.8 | 48.6 | 87% da janela vem da E03 (Issue #225)
33 | 2026-08-13 14:55 | 2026-08-16 09:20 | 2026-08-15 16:30 | 92 | Teste | Cheia | 11 | Inundação | 17.3* | 30.8* | 56.5* | 93% da janela vem da E03 (Issue #225)
34 | 2026-08-29 10:30 | 2026-08-30 07:50 | 2026-08-29 15:55 | 77 | Teste | Cheia | 12 | Alerta | 21.0 | 21.0 | 22.0
35 | 2026-08-30 09:10 | 2026-09-01 20:25 | 2026-09-01 02:20 | 101 | Teste | Cheia | 11 | Inundação | 27.9 | 33.4 | 54.7
36 | 2026-09-10 03:40 | 2026-09-10 13:05 | 2026-09-10 08:20 | 59 | Teste | Cheia | 1 | Normal | 21.1 | 23.0 | 23.0
37 | 2026-09-11 11:00 | 2026-09-12 16:10 | 2026-09-11 17:20 | 100 | Teste | Cheia | 15 | Inundação | 39.0 | 42.8 | 43.5

## SAPI — Catálogo de Eventos (event_windows_v3.csv) — Auditoria de Lead Time e RMSE

Subida máx. 30 min: maior subida do nível em qualquer intervalo de 30 min do evento (valor de pico, não a média da subida inteira); Enxurrada quando chega a 25 cm. Limiares: Atenção=60cm, Alerta=75cm, Inundação=90cm — Fonte do dado bruto: dump SQL local — Fonte do dado filtrado/modelos: pipeline real_utils.py

P6h/P12h/P24h: chuva acumulada (mm) nas 6/12/24 h antes do pico, da série que alimenta os modelos (MERGE antes de 02/01/2026, Estação-02 depois).
* = janela com lacuna na fonte — ver aviso na página do evento. Excluído = artefato de sensor, fora do treino e das métricas (Issue #227).

① Nível bruto — direto do dump SQL, sem filtro de delta. Escala vertical fixada pela série FILTRADA: outliers de sensor saem da área visível em vez de esmagar a escala.

② Nível filtrado — pipeline real_utils.py (o que alimenta M4/M6)

Evento 01 — Página A — Qualidade do dado (bruto vs. filtrado) | TREINO
Janela: 2025-01-16 21:45 → 2025-01-18 18:50 UTC | Tipo: Cheia | Nível atingido: Alerta

Pico: 79 cm às 2025-01-17 14:35 UTC (11:35 horário local)

Chuva acumulada antes do pico (MERGE): 6 h = 53.0 mm | 12 h = 96.1 mm | 24 h = 192.6 mm

Notas: subida máx. em 30 min: 7 cm

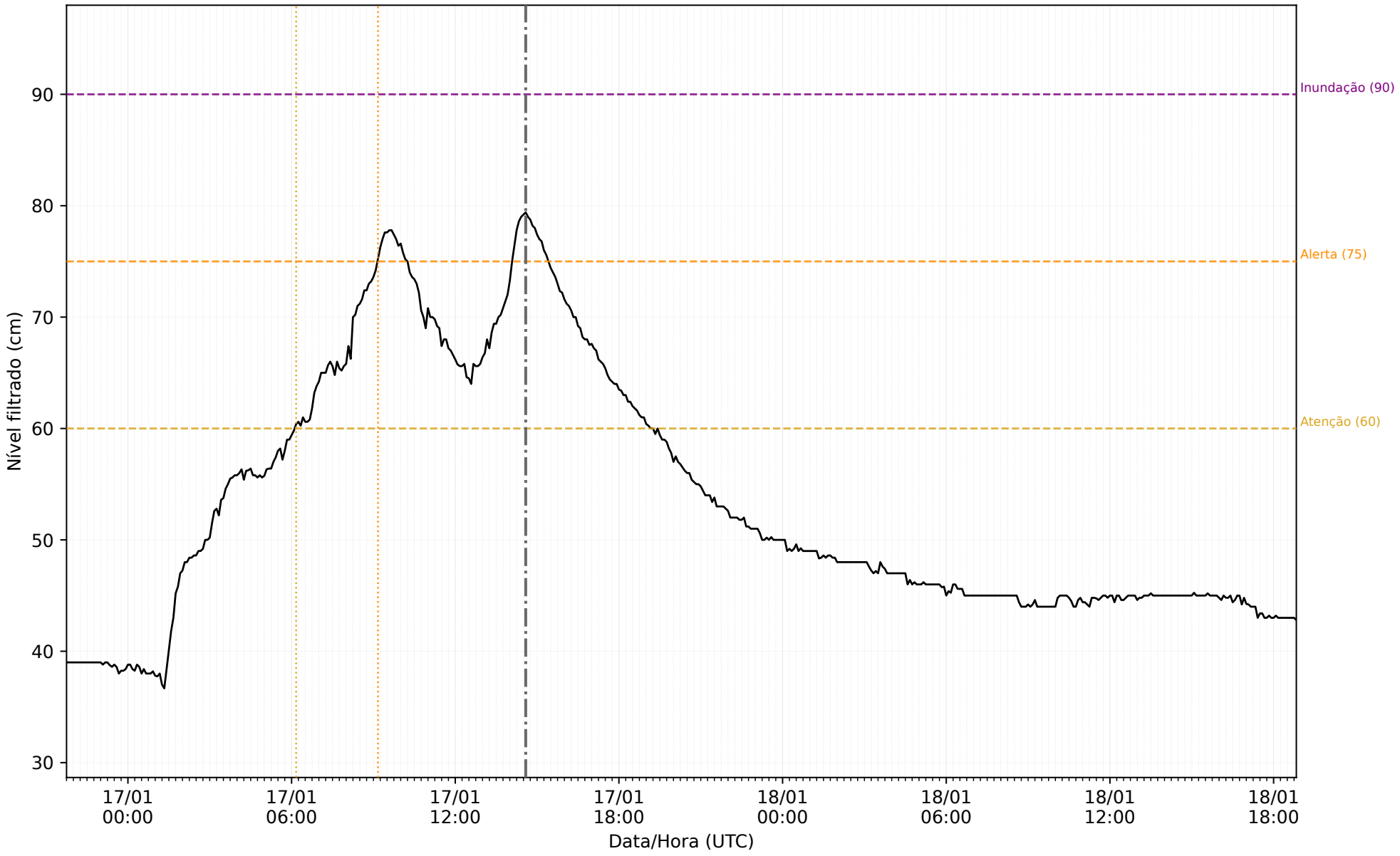
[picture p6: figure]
Data/Hora (UTC); Nível filtrado (cm); Atenção (60); Alerta (75); Inundação (90)

Observado | Pico catalogado | Atenção (60 cm) | Alerta (75 cm) | Inundação (90 cm)

40

50

60

70

80

90

100

+30 min

(cm)

Atenção (60)

Alerta (75)

Inundação (90)

Atenção: ● 17/01 06:10 | M4 05:50 (+20min) | M6 06:15 (-5min)
Alerta #1: ● 17/01 09:10 | M4 08:50 (+20min) | M6 09:20 (-10min)
Alerta #2: ● 17/01 14:05 | M4 13:50 (+15min) | M6 14:15 (-10min)
#1 | #2

40

50

60

70

80

90

100

+60 min

(cm)

Atenção (60)

Alerta (75)

Inundação (90)

Atenção: ● 17/01 06:10 | M4 05:05 (+65min) | M6 06:15 (-5min)
Alerta #1: ● 17/01 09:10 | M4 08:25 (+45min) | M6 09:20 (-10min)
Alerta #2: ● 17/01 14:05 | M4 13:15 (+50min) | M6 14:15 (-10min)
#1 | #2

40

50

60

70

80

90

100

+90 min

(cm)

Atenção (60)

Alerta (75)

Inundação (90)

Atenção: ● 17/01 06:10 | M4 05:05 (+65min) | M6 06:15 (-5min)
Alerta #1: ● 17/01 09:10 | M4 07:50 (+80min) | M6 09:20 (-10min)
Alerta #2: ● 17/01 14:05 | M4 12:50 (+75min) | M6 14:20 (-15min)
#1 | #2

17/01

17/01

17/01

17/01

18/01

18/01

18/01

18/01

40

50

60

70

80

90

100

+120 min

(cm)

Atenção (60)

Alerta (75)

Inundação (90)

Atenção: ● 17/01 06:10 | M4 04:10 (+120min) | M6 06:15 (-5min)
Alerta #1: ● 17/01 09:10 | M4 07:20 (+110min) | M6 09:20 (-10min)
Alerta #2: ● 17/01 14:05 | M4 12:10 (+115min) | M6 não atingido
#1 | #2

Evento 01 — Página B — Auditoria de previsão M4 (LightGBM) vs. M6 (MLR) | TREINO
Janela: 2025-01-16 21:45 → 2025-01-18 18:50 UTC | Tipo: Cheia | Nível atingido: Alerta

Pico: 79 cm às 2025-01-17 14:35 UTC (11:35 horário local)

Chuva acumulada antes do pico (MERGE): 6 h = 53.0 mm | 12 h = 96.1 mm | 24 h = 192.6 mm

Notas: subida máx. em 30 min: 7 cm

Sem métricas de backtest disponíveis — evento de treino

- = nível real cruzou o limiar (#1, #2 = cruzamentos repetidos); ▲ M4 / ▼ M6 = alarme do modelo disparou (previsão acima do limiar por 15 min); ≥ = alarme já ligado no início da busca. Curvas na hora em que a previsão foi emitida.

Observado
Previsto M4

Pico catalogado

Cruzamento observado
Cruzamento previsto M4
Atenção (60 cm)

Alerta (75 cm)
Inundação (90 cm)

① Nível bruto — direto do dump SQL, sem filtro de delta. Escala vertical fixada pela série FILTRADA: outliers de sensor saem da área visível em vez de esmagar a escala.

② Nível filtrado — pipeline real_utils.py (o que alimenta M4/M6)

Evento 02 — Página A — Qualidade do dado (bruto vs. filtrado) | TREINO
Janela: 2025-01-25 17:55 → 2025-01-26 07:45 UTC | Tipo: Cheia | Nível atingido: Atenção

Pico: 66 cm às 2025-01-26 00:05 UTC (21:05 horário local)

Chuva acumulada antes do pico (MERGE): 6 h = 25.8 mm | 12 h = 25.8 mm* | 24 h = 52.5 mm*

⚠ Chuva nas 24 h antes do pico: MERGE sem 5 h de dados (o pipeline repete o valor da última hora disponível, o acumulado é aproximado)

Notas: subida máx. em 30 min: 6 cm

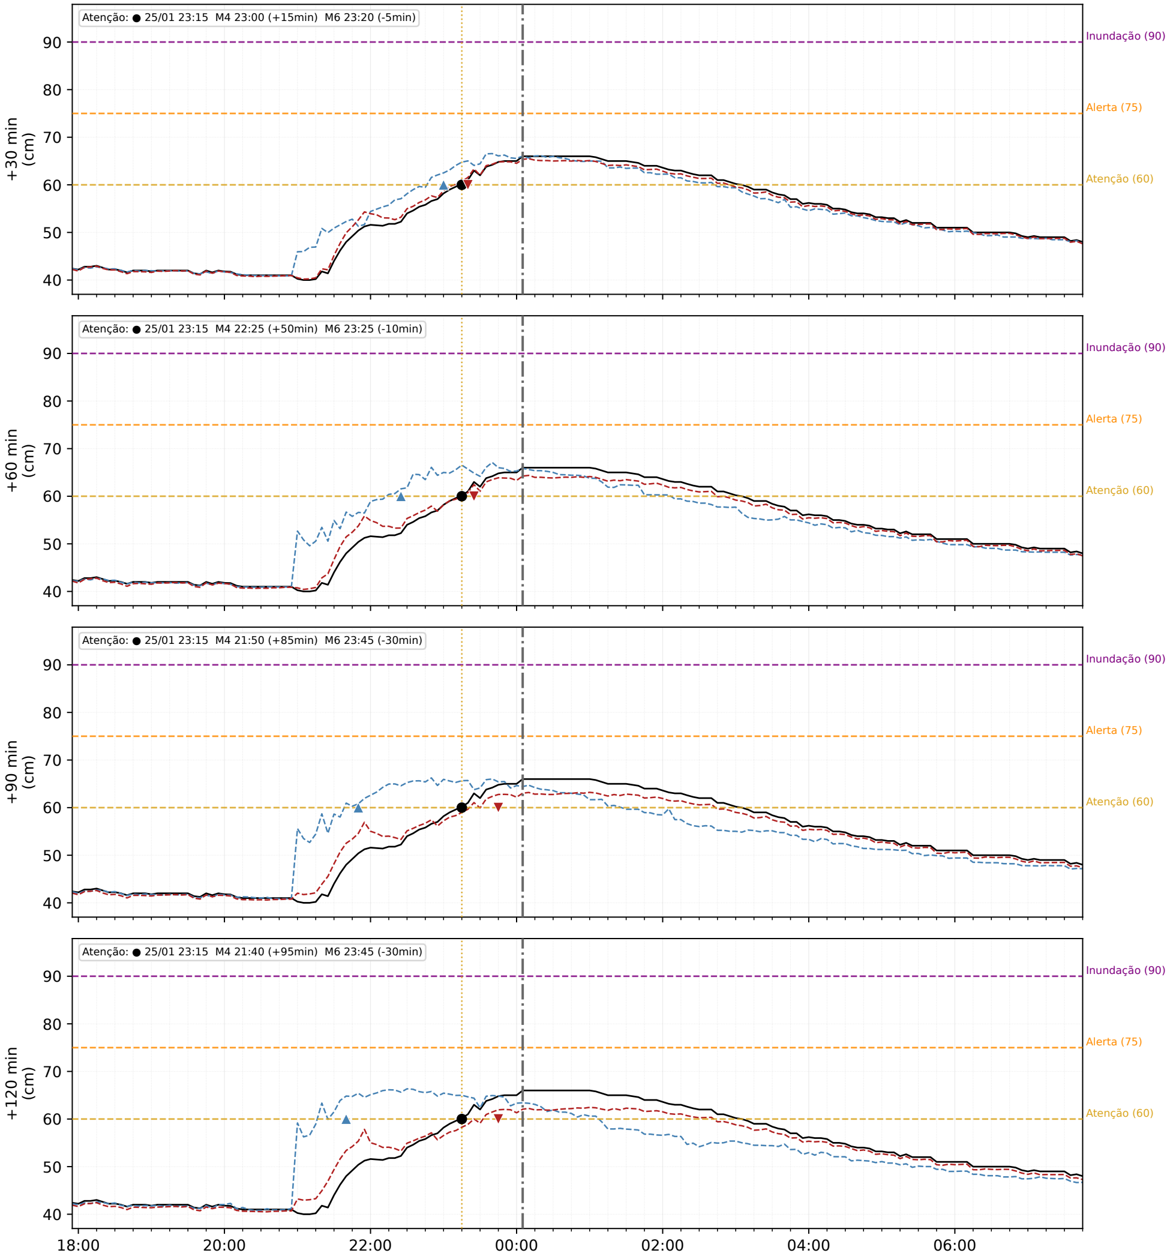
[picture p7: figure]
+30 min; Atenção (60); Alerta (75); Inundação (90); +60 min; +90 min; +120 min

Atenção: ● 25/01 23:15 M4 23:00 (+15min) M6 23:20 (-5min)

Atenção: ● 25/01 23:15 M4 22:25 (+50min) M6 23:25 (-10min)

Atenção: ● 25/01 23:15 M4 21:50 (+85min) M6 23:45 (-30min)

Atenção: ● 25/01 23:15 M4 21:40 (+95min) M6 23:45 (-30min)

Evento 02 — Página B — Auditoria de previsão M4 (LightGBM) vs. M6 (MLR) | TREINO
Janela: 2025-01-25 17:55 → 2025-01-26 07:45 UTC | Tipo: Cheia | Nível atingido: Atenção

Pico: 66 cm às 2025-01-26 00:05 UTC (21:05 horário local)

Chuva acumulada antes do pico (MERGE): 6 h = 25.8 mm | 12 h = 25.8 mm* | 24 h = 52.5 mm*

⚠ Chuva nas 24 h antes do pico: MERGE sem 5 h de dados (o pipeline repete o valor da última hora disponível, o acumulado é aproximado)

Notas: subida máx. em 30 min: 6 cm

Sem métricas de backtest disponíveis — evento de treino

- = nível real cruzou o limiar (#1, #2 = cruzamentos repetidos); ▲ M4 / ▼ M6 = alarme do modelo disparou (previsão acima do limiar por 15 min); ≥ = alarme já ligado no início da busca. Curvas na hora em que a previsão foi emitida.

30

40

50

60

70

80

90

Nível bruto (cm)

Atenção (60)

Alerta (75)

Inundação (90)

① Nível bruto — direto do dump SQL, sem filtro de delta. Escala vertical fixada pela série FILTRADA: outliers de sensor saem da área visível em vez de esmagar a escala.

② Nível filtrado — pipeline real_utils.py (o que alimenta M4/M6)

Evento 03 — Página A — Qualidade do dado (bruto vs. filtrado) | TREINO
Janela: 2025-02-17 22:10 → 2025-02-18 08:05 UTC | Tipo: Cheia | Nível atingido: Normal

Pico: 48 cm às 2025-02-18 03:30 UTC (00:30 horário local)

Chuva acumulada antes do pico (MERGE): 6 h = 18.8 mm | 12 h = 19.3 mm | 24 h = 20.7 mm

Notas: subida máx. em 30 min: 1 cm

Evento 03 — Página B — Auditoria de previsão M4 (LightGBM) vs. M6 (MLR) | TREINO
Janela: 2025-02-17 22:10 → 2025-02-18 08:05 UTC | Tipo: Cheia | Nível atingido: Normal

Pico: 48 cm às 2025-02-18 03:30 UTC (00:30 horário local)

Chuva acumulada antes do pico (MERGE): 6 h = 18.8 mm | 12 h = 19.3 mm | 24 h = 20.7 mm

Notas: subida máx. em 30 min: 1 cm

Sem métricas de backtest disponíveis — evento de treino

- = nível real cruzou o limiar (#1, #2 = cruzamentos repetidos); ▲ M4 / ▼ M6 = alarme do modelo disparou (previsão acima do limiar por 15 min); ≥ = alarme já ligado no início da busca. Curvas na hora em que a previsão foi emitida.

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

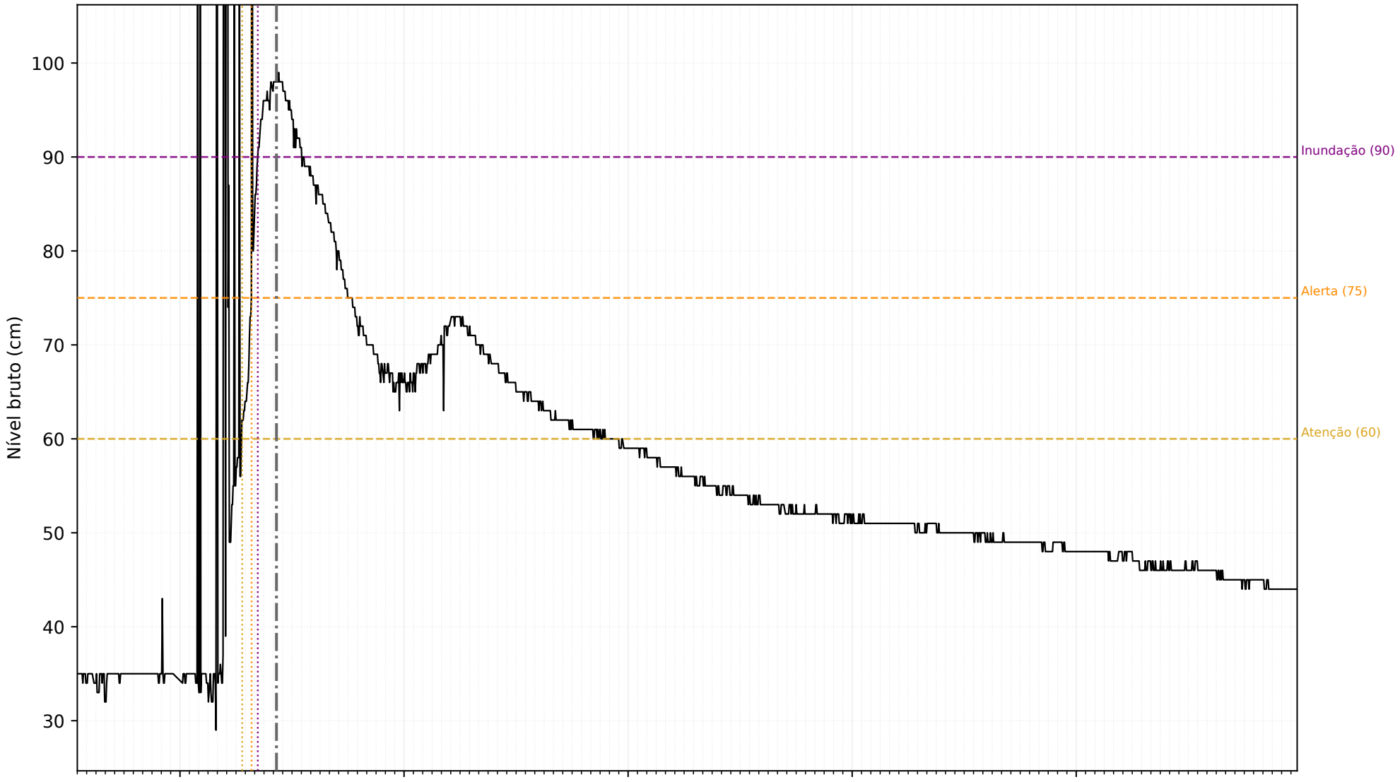
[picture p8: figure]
Nível bruto (cm); Atenção (60); Alerta (75); Inundação (90)

② Nível filtrado — pipeline real_utils.py (o que alimenta M4/M6)

Evento 04 — Página A — Qualidade do dado (bruto vs. filtrado) | TREINO
Janela: 2025-04-10 14:15 → 2025-04-11 22:55 UTC | Tipo: Enxurrada | Nível atingido: Inundação

Pico: 98 cm às 2025-04-10 19:35 UTC (16:35 horário local)

Chuva acumulada antes do pico (MERGE): 6 h = 4.5 mm | 12 h = 4.7 mm | 24 h = 5.3 mm

Notas: subida máx. em 30 min: 34 cm

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
+30 min

(cm)

Atenção (60)

Alerta (75)

Inundação (90)

Atenção: ● 10/04 18:40 Alerta: ● 10/04 18:55 | M4 18:25 (+15min) M4 18:35 (+20min) | M6 19:00 (-5min) | M6 18:40 (+0min)
Inundação: ● 10/04 19:05 | M4 18:45 (+20min) | | | M6 19:10 (-5min)

40

60

80

100

120

+60 min

(cm)

Atenção (60)

Alerta (75)

Inundação (90)

Atenção: ● 10/04 18:40 | M4 17:35 (+65min) | M6 18:40 (+0min)
Alerta: ● 10/04 18:55 | M4 18:15 (+40min) | M6 19:05 (-10min)
Inundação: ● 10/04 19:05 | M4 18:25 (+40min) | M6 19:15 (-10min)

40

60

80

100

120

+90 min

(cm)

Atenção (60)

Alerta (75)

Inundação (90)

Atenção: ● 10/04 18:40 | M4 17:25 (+75min) | M6 18:50 (-10min)
Alerta: ● 10/04 18:55 | M4 17:35 (+80min) | M6 19:05 (-10min)
Inundação: ● 10/04 19:05 | M4 17:50 (+75min) | M6 não atingido

10/04

10/04

11/04

11/04

11/04

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
+120 min

(cm)

Atenção (60)

Alerta (75)

Inundação (90)
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

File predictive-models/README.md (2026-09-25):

# predictive-models

Darts-based predictive models for SAPI — M4 (LightGBM) and M6 (multiple linear
regression) — plus the data pipeline that feeds them and the production deployment.

## Directory structure

| Path | Purpose | Status |
|---|---|---|
| `config.py` | Shared paths and constants for the data pipeline below | **Active** |
| `build_event_catalogue.py` | Segments the level series into episodes → `event_windows_v3.csv` | **Active** |
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

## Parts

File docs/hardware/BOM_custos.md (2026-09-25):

# BOM de Custos — Hardware SAPI

Levantamento de custos por hardware do SAPI, para citação na dissertação (fornecedor + preço + data de consulta). Relacionado à issue #173.

**Hardware/eletrônica da Estação-01 (BluePill/F103C8T6) fica de fora** deste levantamento — mesmo precedente do capítulo de Produtos Técnico-Tecnológicos (PTT) da qualificação, que não trata o MCU descontinuado como produto-alvo. A **estrutura física/ferragem de fixação da Estação-01 é contabilizada** (ver seção própria), pois pode ser reaproveitada para hospedar hardware novo (tipo Estação-03) caso essa estação seja futuramente atualizada.

## Metodologia

- **Preço unit.** = (preço do item + imposto de importação) ÷ quantidade da embalagem, quando o anúncio vende em lote/multipack. O imposto é somado porque escala com o valor declarado independentemente de consolidação de pedido — ao contrário do frete, ele não dilui quando vários itens são comprados juntos.
- **Frete propositalmente excluído** do preço unitário e do subtotal de cada linha, salvo exceção explícita — ver [nota sobre frete](#nota-sobre-frete).
- **Fonte**: AliExpress (salvo indicação contrária — Mercado Livre ou JLCPCB são citados por linha). Preços capturados/informados em 2026-07-07.
- Colunas **Link** e **Data** foram removidas da planilha por pedido — o essencial para citação (fornecedor + valor) já está registrado; link de produto fica pendente de recuperação posterior se necessário.
- Capacitores cerâmicos (disco, qualquer valor 0,1–10 µF) usam o mesmo kit de 500 peças / 10 valores como fonte de preço em ambas as tabelas.
- **Cotação USD→BRL usada: R$5,16 (dólar paralelo, 2026-07-07)** — aplicada apenas à linha de PCB (JLCPCB), único item cotado em dólar.
- Fios e cabos soltos/genéricos não são contabilizados nesta planilha (decisão do autor), exceto onde um cabo específico foi explicitamente precificado (ex.: cabo manga externo, cabos internos dupont, cabinho flexível 22AWG).

---

## Tabela 1 — SAPI Shield Morpho V1.2

`hardware/morpho-shield-v1.2/`

| Ref. | Item | Qtd | Fornecedor | Preço unit. | Subtotal |
|---|---|---|---|---|---|
| C1,C2,C3,C4,C5,C7,C8 | Capacitor disco 1uF | 7 | AliExpress (kit 500pçs/10 valores 0,1–10uF) | R$0,063 | R$0,44 |
| C6,C9 | Capacitor disco 0.1uF | 2 | AliExpress (idem) | R$0,063 | R$0,13 |
| D1,D2 | Diodo Schottky SS36 (SMD) | 2 | AliExpress (Elecset Tech Store, kit 150pçs/15 valores) | R$0,212 | R$0,42 |
| J1,J2 | Soquete Morpho 2×19 (conecta no Nucleo) | 2 | AliExpress (alinsin Store, conector 2×40 fêmea reto) | R$2,09 | R$4,18 |
| J3 | Borne Phoenix 2 vias (pluviômetro) | 1 | AliExpress (alinsin Store) | R$1,61 | R$1,61 |
| J5,J6 | Borne Phoenix 2 vias (+12V/+20V) | 2 | AliExpress (alinsin Store) | R$1,61 | R$3,23 |
| J7 | Header 1×05 horizontal | 1 | AliExpress (header macho 1×40, rateado por pino) | R$0,17 | R$0,17 |
| J8 | Header 1×06 (STLINK) | 1 | AliExpress (idem) | R$0,20 | R$0,20 |
| J9 | Header 1×05 vertical | 1 | AliExpress (idem) | R$0,17 | R$0,17 |
| J10 | Header 1×02 (UART) | 1 | AliExpress (idem) | R$0,07 | R$0,07 |
| J11 | Header 1×02 vertical | 1 | AliExpress (idem) | R$0,07 | R$0,07 |
| US1 | Header 1×05 (sensor ultrassônico) | 1 | AliExpress (idem) | R$0,17 | R$0,17 |
| JP1,JP2,JP6,JP7 | Jumper 3 pinos SPDT | 4 | AliExpress (kit 100un) | R$0,09 | R$0,35 |
| JP3,JP4,JP8,JP9,JP10,JP11,JP12 | Jumper/header 2 pinos | 7 | AliExpress (header macho 1×40, rateado por pino) | R$0,07 | R$0,48 |
| JP5 | Solder jumper 3 vias | 1 | (pad na placa, sem peça) | — | — |
| R1 | Resistor 470R | 1 | AliExpress (kit 2600pçs/130 valores 1/4W 1%) | R$0,028 | R$0,03 |
| R2,R3 | Resistor 10k | 2 | AliExpress (idem) | R$0,028 | R$0,06 |
| R4 | Resistor 470k | 1 | AliExpress (idem) | R$0,028 | R$0,03 |
| R5 | Resistor 150k | 1 | AliExpress (idem) | R$0,028 | R$0,03 |
| R6 | Resistor 680k | 1 | AliExpress (idem) | R$0,028 | R$0,03 |
| R7 | Resistor 100k | 1 | AliExpress (idem) | R$0,028 | R$0,03 |
| H1,H2,H3 | Parafuso/furo de montagem M3 12mm | 3 | AliExpress (kit 100pçs, aço preto, cabeça panela phillips) | R$0,144 | R$0,43 |
| U1 | Optoacoplador TIL113 (DIP-6) | 1 | AliExpress (KUNYO Xinsheng Excellence Technology Store) | R$1,87 | R$1,87 |
| U2 | CD4040 — contador binário 12 estágios (DIP-16) | 1 | AliExpress (Supplier of electronic components Store) | R$1,10 | R$1,10 |
| U3 | 74HC166 — registrador de deslocamento 8 bits (DIP-16) | 1 | AliExpress (kit 10un) | R$0,95 | R$0,95 |
| U4 | Header 1×04 2,54mm (conector p/ módulo de temperatura — sensor varia por estação, ver Estação-02) | 1 | AliExpress (header macho 1×40, rateado por pino) | R$0,14 | R$0,14 |
| U5,U6,U7 | Módulo chave MOSFET HW-613 | 3 | AliExpress (Gangda Tong Store — preço do módulo DC-DC step-down usado como proxy, ver nota¹) | R$3,10 | R$9,30 |
| U1 (soquete, opcional) | Soquete IC DIP-6 para U1 | 1 | AliExpress (alinsin Store, kit 10un) | R$0,75 | R$0,75 |
| U2,U3 (soquete, opcional) | Soquete IC DIP-16 para U2/U3 | 2 | AliExpress (alinsin Store, kit 10un) | R$1,13 | R$2,26 |
| — | PCB (fabricação, JLCPCB) | 1 | JLCPCB (pedido combinado com Tabela 2, ver nota²; US$3,52 × R$5,16) | R$18,19 | R$18,19 |
| **Total** | | | | | **R$46,89** |

¹ O anúncio localizado para U5–U7 é um módulo DC-DC step-down 12-24V→5V (20 unidades), não o HW-613 exato — usado como estimativa por instrução direta; confirmar peça exata depois.
² Ver nota sobre PCB abaixo da Tabela 2.

> **U4**: o módulo de sensor de temperatura (ex. BMP280) não é item fixo do shield — apenas o header 2,54mm fica na placa. A definição do sensor varia por estação; na Estação-02 é o BMP280 (precificado na tabela própria, abaixo).

> Soquetes DIP são opcionais (não são Ref. do schematic — facilitam retrabalho no lugar de solda direta de U1/U2/U3), mas já entram no Total acima por terem sido incluídos como linhas.

## Tabela 2 — SAPI LoRa Arduino Shield V1.0

`hardware/lora-arduino-shield-v1.0/`

| Ref. | Item | Qtd | Fornecedor | Preço unit. | Subtotal |
|---|---|---|---|---|---|
| C1 | Capacitor disco 100nF | 1 | AliExpress (kit 500pçs/10 valores 0,1–10uF) | R$0,063 | R$0,06 |
| D2 | LED 3mm | 1 | AliExpress (kit 1000un) | R$0,046 | R$0,05 |
| J1 | Header 1×08 (Power) | 1 | AliExpress (header macho 1×40, rateado por pino) | R$0,27 | R$0,27 |
| J2 | Header 1×10 (Digital/PWM) | 1 | AliExpress (idem) | R$0,34 | R$0,34 |
| J3 | Header 1×06 (Analog) | 1 | AliExpress (idem) | R$0,20 | R$0,20 |
| J4 | Header 1×08 (Digital/PWM) | 1 | AliExpress (idem) | R$0,27 | R$0,27 |
| J7 | Header 1×05 horizontal (Power) | 1 | AliExpress (idem) | R$0,17 | R$0,17 |
| JP1–JP4 | Jumper 3 pinos SPDT | 4 | AliExpress (kit 100un) | R$0,09 | R$0,35 |
| JP11,JP12 | Header/jumper 2 pinos | 2 | AliExpress (header macho 1×40, rateado por pino) | R$0,07 | R$0,14 |
| R7 | Resistor 10k | 1 | AliExpress (kit 2600pçs/130 valores 1/4W 1%) | R$0,028 | R$0,03 |
| S1 | Botão tátil 6×6mm | 1 | AliExpress (kit 100un) | R$0,32 | R$0,32 |
| SW4 | Chave DPDT push (reset) | 1 | AliExpress (kit 100un — frete incluído por exceção, ver nota sobre frete) | R$0,31 | R$0,31 |
| U4 **ou** U8 | Módulo rádio: **LILYGO LoRa32 (escolhido — opção mais cara das duas alternativas)** | 1 | AliExpress (lilygo Official Store — "LILYGO® TTGO Accessories Shield LoRa 868/915Mhz") | R$104,04 | R$104,04 |
| — | PCB (fabricação, JLCPCB) | 1 | JLCPCB (pedido combinado com Tabela 1, ver nota²; US$3,52 × R$5,16) | R$18,19 | R$18,19 |
| **Total** | | | | | **R$124,74** |

> **AE1 (antena LoRa 915MHz) removida** da tabela — já vem embutida no módulo de rádio (LILYGO LoRa32), não é item separado.

> **Nota sobre PCB**: fabricação combinada das duas placas na JLCPCB, 5 unidades de cada shield, total US$18,55 + 90% de impostos = US$35,25 para as 10 placas → US$3,5245/placa → **R$18,19/placa** (câmbio R$5,16/US$, dólar paralelo, 2026-07-07), aplicado como Preço unit. em ambas as tabelas (Qtd 1 = uma placa por shield).

---

## Itens de Inventário Manual — por Estação

Estação-02 = pluviométrica (báscula), Estação-03 = cota de nível. Cada uma soma seu próprio MCU + fonte de energia + rádio + case/estrutura; itens abaixo não incluem o custo das placas Shield Morpho/LoRa (Tabelas 1 e 2 — uma de cada por estação).

### Estação-02 (pluviométrica)

| Item | Fornecedor | Preço unit. | Qtd | Subtotal |
|---|---|---|---|---|
| NUCLEO-F103RB STM32 Nucleo-64 | AliExpress (frete incluído por exceção — ver nota) | R$189,11 | 1 | R$189,11 |
| Módulo BMP280 (breakout HW-611, temperatura/pressão) | AliExpress (kit 5un) | R$3,77 | 1 | R$3,77 |
| Controlador de Carga Morningstar Sunkeeper 6A 100W | Mercado Livre (já com imposto+frete) | R$74,00 | 1 | R$74,00 |
| Bateria VRLA 12V 2,3Ah Xb 1223 (Intelbras, ~2200mAh) | Mercado Livre (já com imposto+frete) | R$137,26 | 1 | R$137,26 |
| Pluviômetro de báscula digital PB10 | Mercado Livre (Usinainfo — frete somado por exceção, ver nota) | R$952,62 | 1 | R$952,62 |
| Interruptor rocker KCD1-110 (seletor V painel / V bateria) | AliExpress (xin cheng electronic — assumido pacote de 10un*) | R$2,17 | 2 | R$4,34 |
| Painel Solar Ztroon 20W Fotovoltaico Monocristalino PERC¹ | Mercado Livre (já com imposto+frete) | R$126,00 | 1 | R$126,00 |
| Abrigo meteorológico para sensores TPH | AliExpress (78,00 + 16,00 imp + 41,28 frete somado por exceção) | R$135,28 | 1 | R$135,28 |
| Filamento PETG XT Branco 1,75mm (partes internas/suportes)² | 3dfila.com.br (já com imposto+frete) | R$96,90/kg × 1,5kg | 1,5kg | R$145,35 |
| Tubo PVC Esgoto 100mm Amanco (50cm, de barra de 6m R$119,90) | Loja física/local (já com imposto+frete) | R$19,983/m | 0,5m | R$9,99 |
| Cap PVC Esgoto 100mm Amanco | Loja física/local (já com imposto+frete) | R$9,60 | 1 | R$9,60 |
| Parafuso Phillips Máquina Panela MA 3×16 Inox + porca sextavada (suporte bateria interna) | Loja física/local | R$0,27/un (0,16+0,11) | 4 | R$1,08 |
| Parafuso Phillips Máquina Panela MA 3×16 Inox + porca sextavada (prendedor da tampa do case) | Loja física/local | R$0,27/un | 4 | R$1,08 |
| Parafuso Phillips Máquina Panela MA 3×16 Inox + porca sextavada (controlador de carga) | Loja física/local | R$0,27/un | 2 | R$0,54 |
| Parafuso Phillips Máquina Panela MA 3×30 Inox + porca sextavada (suporte do case) | Loja física/local | R$0,87/un (0,76+0,11) | 6 | R$5,22 |
| Parafuso Phillips Máquina Panela MA 3×20 Inox + porca sextavada (suporte do case) | Loja física/local | R$0,60/un (0,49+0,11) | 4 | R$2,40 |
| Parafuso Phillips Máquina Panela MA 3×30 Inox + porca sextavada (trava da placa Nucleo) | Loja física/local | R$0,87/un | 1 | R$0,87 |
| Auto Atarraxante Phillips Chata 2.2×6,5 Aço Carbono Zincado (presilhas da tampa) | Loja física/local | R$0,05/un | 8 | R$0,40 |
| Auto Atarraxante Phillips Panela 2.2×13 Aço Carbono Zincado (colunas/standoffs) | Loja física/local | R$0,06/un | 40 | R$2,40 |
| Conector painel GX12 2 pinos (par macho+fêmea) | AliExpress (Widsey Store, kit 5un) | R$5,14 | 1 | R$5,14 |
| Conector painel GX12 5 pinos (par macho+fêmea) | AliExpress (Widsey Store, kit 5un) | R$5,65 | 2 | R$11,31 |
| Push-button de reset geral (tampa do case) | AliExpress (TLZWLA Official Store) | R$8,97 | 1 | R$8,97 |
| Cabo dupont fêmea-fêmea 2,54mm 5pin 50cm (conexão interna entre placas) | AliExpress (Electrical Wire Store, kit 10un) | R$5,56 | 4 | R$22,26 |
| Cabinho flexível eletrônica 22AWG (0,30mm), várias cores — fiação interna (rolo 100m) | Mercado Livre (frete incluso) | R$0,60/m | 15m | R$9,00 |
| Abraçadeira Nylon Preto 50cm, resistente UV 30kg, modelo SQ-4280 (pacote 100un) | Mercado Livre (frete incluso) | R$0,331/un | 4 | R$1,32 |
| **Subtotal Estação-02 (itens manuais, exclui Shield Morpho/LoRa; exclui ferragem do post — ver seção própria)** | | | | **R$1.859,31** |

### Estação-03 (cota de nível)

| Item | Fornecedor | Preço unit. | Qtd | Subtotal |
|---|---|---|---|---|
| Nucleo L476RG | AliExpress (W Official Store) com frete incluso| R$245,78 | 1 | R$245,78 |
| EPEVER Tracer2606BP-10A/12V 24V Auto (MPPT) | AliExpress (Solar & Wind Store) | R$383,55 | 1 | R$383,55 |
| Bateria de lítio 12V 4400mAh c/ BMS Sanyo | Mercado Livre (já com imposto+frete) | R$94,04 | 1 | R$94,04 |
| SHT20 (IP65, Style A) | AliExpress (UICPAL Official Store) | R$55,64 | 1 | R$55,64 |
| US-100 (sensor ultrassônico, já em operação) | AliExpress (loja não especificada na cotação) | R$29,28 | 1 | R$29,28 |
| Interruptor rocker KCD1-110 (seletor V painel / V bateria) | AliExpress (xin cheng electronic — assumido pacote de 10un*) | R$2,17 | 2 | R$4,34 |
| Painel Solar Ztroon 20W Fotovoltaico Monocristalino PERC¹ | Mercado Livre (já com imposto+frete) | R$126,00 | 1 | R$126,00 |
| Abrigo meteorológico para sensores TPH | AliExpress (78,00 + 16,00 imp + 41,28 frete somado por exceção) | R$135,28 | 1 | R$135,28 |
| Filamento PETG XT Branco 1,75mm (partes internas/suportes)² | 3dfila.com.br | R$96,90/kg × 1,5kg | 1,5kg | R$145,35 |
| Tubo PVC Esgoto 100mm Amanco (50cm, de rolo de 6m R$119,90) | Loja física/local | R$19,983/m | 0,5m | R$9,99 |
| Cap PVC Esgoto 100mm Amanco | Loja física/local | R$9,60 | 1 | R$9,60 |
| Parafuso Phillips Máquina Panela MA 3×16 Inox + porca sextavada (suporte bateria interna) | Loja física/local | R$0,27/un (0,16+0,11) | 4 | R$1,08 |
| Parafuso Phillips Máquina Panela MA 3×16 Inox + porca sextavada (prendedor da tampa do case) | Loja física/local | R$0,27/un | 4 | R$1,08 |
| Parafuso Phillips Máquina Panela MA 3×16 Inox + porca sextavada (controlador de carga) | Loja física/local | R$0,27/un | 2 | R$0,54 |
| Parafuso Phillips Máquina Panela MA 3×30 Inox + porca sextavada (suporte do case) | Loja física/local | R$0,87/un (0,76+0,11) | 6 | R$5,22 |
| Parafuso Phillips Máquina Panela MA 3×20 Inox + porca sextavada (suporte do case) | Loja física/local | R$0,60/un (0,49+0,11) | 4 | R$2,40 |
| Parafuso Phillips Máquina Panela MA 3×30 Inox + porca sextavada (trava da placa Nucleo) | Loja física/local | R$0,87/un | 1 | R$0,87 |
| Parafuso Phillips Máquina Panela MA 3×20 Inox + porca sextavada (tampa da placa do sensor ultrassônico US-100) | Loja física/local | R$0,60/un | 4 | R$2,40 |
| Auto Atarraxante Phillips Chata 2.2×6,5 Aço Carbono Zincado (presilhas da tampa) | Loja física/local | R$0,05/un | 8 | R$0,40 |
| Auto Atarraxante Phillips Panela 2.2×13 Aço Carbono Zincado (colunas/standoffs) | Loja física/local | R$0,06/un | 40 | R$2,40 |
| Conector painel GX12 2 pinos (par macho+fêmea) | AliExpress (Widsey Store, kit 5un) | R$5,14 | 1 | R$5,14 |
| Conector painel GX12 5 pinos (par macho+fêmea) | AliExpress (Widsey Store, kit 5un) | R$5,65 | 2 | R$11,31 |
| Push-button de reset geral (tampa do case) | AliExpress (TLZWLA Official Store) | R$8,97 | 1 | R$8,97 |
| Cabo dupont fêmea-fêmea 2,54mm 5pin 50cm (conexão interna entre placas) | AliExpress (Electrical Wire Store, kit 10un) | R$5,56 | 4 | R$22,26 |
| Cabinho flexível eletrônica 22AWG (0,30mm), várias cores — fiação interna (rolo 100m) | Mercado Livre (frete incluso) | R$0,60/m | 15m | R$9,00 |
| **Subtotal Estação-03 (itens manuais, exclui Shield Morpho/LoRa; exclui ferragem — ver seção própria; régua e pluviômetro de copo NÃO entram aqui, são equipamento de calibração)** | | | | **R$1.311,92** |

¹ Especificações do painel Ztroon 20W: Pmax 20W, Vmp 21,25V, Imp 0,95A, Voc 24,72V, Isc 0,99A, eficiência 16,2%, célula monocristalina PERC (36 células, config. 4×9), 275×450×17mm, 0,12m², 1,25kg.
² Fonte: [3dfila.com.br/produto/filamento-petg-branco](https://3dfila.com.br/produto/filamento-petg-branco/). Preço por kg assumido a partir do rolo padrão de 1kg — confirmar peso do rolo anunciado antes de fechar a compra.
\* KCD1-110: (17,99 + 3,73 imp)/10 — pacote de 10 peças (preço corrigido pelo autor 2026-07-07).

**Custo estimado por estação completa** = Subtotal manual da estação + Tabela 1 (Shield Morpho, R$46,89) + Tabela 2 (Shield LoRa, R$124,74), já com PCB convertido para R$. **Estação-02 ≈ R$2.030,94. Estação-03 ≈ R$1.483,55.** Ambos **excluem** a ferragem do post/estrutura de fixação — ver [Resumo de Custos](#resumo-de-custos) e a seção de Ferragem por Estação, abaixo.

### Gateway

Sem case dedicado (impresso em PETG) — usa a mesma lógica de tubo/cap PVC das estações, em tamanho menor.

| Item | Fornecedor | Preço unit. | Qtd | Subtotal |
|---|---|---|---|---|
| LilyGo T-SIM7000G | AliExpress (lilygo Official Store) (já com imposto+frete) | R$395,51 | 1 | R$395,51 |
| Cap PVC Esgoto 100mm Amanco | Loja física/local (já com imposto+frete) | R$9,60 | 1 | R$9,60 |
| Tubo PVC Esgoto 100mm Amanco (40cm) | Loja física/local (já com imposto+frete) | R$19,983/m | 0,4m | R$7,99 |
| Filamento PETG XT Branco 1,75mm (case impresso) | 3dfila.com.br (já com imposto+frete) | R$96,90/kg | 1kg | R$96,90 |
| Cartão de memória microSD 32GB (SanDisk Ultra Classe 10, 100MB/s, c/ adaptador SD) | Mercado Livre (frete grátis) | R$49,51 | 1 | R$49,51 |
| Fonte de alimentação USB-C | Não especificado (frete+imposto inclusos) | R$40,00 | 1 | R$40,00 |
| **Subtotal Gateway (itens com preço; sem ferragem — Gateway é indoor, sem post)** | | | | **R$599,51** |

> **Chip M2M**: custo recorrente de R$10,00/mês (assinatura de dados) — não é item de BOM único, não entra no subtotal acima. Anotar à parte no orçamento operacional.

### Ferragem por Estação

**Fonte: Zinca Rápido Comércio de Ferragens, Orçamento #881518, 07/07/2026** (`/var/tmp/BOMlist/ferragens.jpeg`) — cobre parte da estrutura tubular da Estação-01 e da Estação-03. **Correção 2026-07-07**: "Ferragem E1" era mesmo **Estação-01** (não Estação-02, como assumido antes) — o hardware BluePill continua fora do escopo, mas essa estrutura é contabilizada por poder ser reaproveitada com eletrônica nova tipo Estação-03.

**Estação-01** (retrofit estrutural — post/braço de fixação na ponte; eletrônica reaproveitaria os valores já precificados na Estação-03 se essa substituição avançar):

| Item | Preço unit. (loja) | Observação |
|---|---|---|
| Conexão T 3/4" com rosca | R$15,91/un | 2 unidades necessárias → R$31,82 |
| Tubo de ferro galvanizado rosca 3/4" CH2,25mm (barra) | R$24,695/m (barra 6m R$148,17) | ~7m necessários → R$172,87 (custeado por metro, não por barra inteira) |
| Fonte de alimentação 12V 2A bivolt estabilizada (LED) | R$11,50/un | Mercado Livre, frete grátis |
| Barra Fe galvanizado 1½"×3/16" — corte 2×25cm+2×10cm (70cm) | R$12,848/m (barra 6m R$77,09) | Loja física/local |
| Barra Fe galvanizado 3/4"×3/16" — corte 6×15cm+4×5cm+100cm (210cm) | R$8,065/m (barra 6m R$48,39) | Loja física/local |
| **Subtotal parcial (2×T + tubo + fonte + barras)** | | **R$242,12** (31,82 + 172,87 + 11,50 + 8,99 + 16,94) |

**Estação-03** (adicional à ferragem já listada — 3m cano 3/4" + 1 joelho — e ao suporte do painel solar):

| Item | Preço unit. (loja) | Observação |
|---|---|---|
| Conexão cotovelo 90° fêmea 3/4" | R$12,44/un | Bate com a pendência "1 joelho 3/4"" |
| Tubo de ferro galvanizado rosca 3/4" (mesma barra da Estação-01) | R$24,695/m (barra 6m R$148,17) | ~3m necessários → R$74,09 (custeado por metro, não por barra inteira) |
| Barra Fe galvanizado 1½"×3/16" — corte 2×25cm (50cm) | R$12,848/m (barra 6m R$77,09) | Loja física/local |
| Barra chata Fe galvanizado 1/2"×1/8" — corte 4×50cm (suporte painel solar) | R$2,678/m (barra 6m R$16,07) | Loja física/local |
| **Subtotal parcial (cotovelo + tubo + barras)** | | **R$98,31** (12,44 + 74,09 + 6,42 + 5,36) |

**Compartilhado / uso ainda não alocado entre as duas:**

| Item | Preço unit. (loja) | Observação |
|---|---|---|
| Serviço de zincagem | R$2,20/kg (4,74kg cotados) | R$10,43 — galvanização das barras cortadas sob medida (Estação-01 + Estação-03) |
| Ferro laminado cantoneira 3/4"×1/8" (CA3418) | R$42,28/un (barra) | Uso não especificado na lista original — confirmar destino |
| **Subtotal Compartilhado (zincagem + cantoneira)** | | **R$52,71** (10,43 + 42,28) |

**Estação-02** (post de fixação do pluviômetro de báscula PB10 — apenas 2m de tubo de ferro galvanizado 1½", sem T/joelho):

| Item | Preço unit. (loja) | Observação |
|---|---|---|
| Tubo de ferro galvanizado 1½" (barra 6m R$132,04) | R$22,007/m | 2m necessários → R$44,01 |
| Barra chata Fe galvanizado 1/2"×1/8" (mesmo preço já usado, barra 6m R$16,07) | R$2,678/m | 3m necessários → R$8,04 |
| Parafuso para Madeira Phillips Chata 3.0×30 Aço Carbono Bicromatizado | R$0,12/un | 8 unidades → R$0,96 |
| **Subtotal (tubo + barra + parafusos)** | | **R$53,01** (44,01 + 8,04 + 0,96) |

> **Estação-01 e Estação-03**: como as barras de tubo de ferro galvanizado 3/4" são sempre vendidas em comprimento fixo de 6m, optou-se por custear pelo metro/cm efetivamente necessário ao projeto (Estação-01: 7m × R$24,695/m = R$172,87; Estação-03: 3m × R$24,695/m = R$74,09), em vez de tentar prever quantas barras inteiras a loja vai vender.
>
> **Já precificado nesta rodada** (2026-07-07/09, loja física/local, preço por metro a partir de barras de 6m): barra Fe galvanizado 1½"×3/16" (R$77,09/barra), barra Fe galvanizado 3/4"×3/16" (R$48,39/barra), barra chata Fe galvanizado 1/2"×1/8" (R$16,07/barra), tubo de ferro galvanizado 1½" (R$132,04/barra) — ver linhas nas tabelas de Estação-01/02/03 acima e na seção de calibração abaixo. Fonte de alimentação 12V 2A bivolt (Estação-01, retrofit) também precificada — Mercado Livre, kit 2un R$22,99, frete grátis. O cabo de energia 1,5mm² par 5m **não é contabilizado** (fios/cabos soltos fora do escopo, por decisão do autor).

### Equipamentos de Calibração de Campo

**Não entram no custo de nenhuma estação** — são instrumentos de referência/aferição, não hardware instalado:

| Item | Fornecedor | Preço unit. | Qtd | Subtotal |
|---|---|---|---|---|
| Régua limnimétrica — adesivo vinil para piso 20×200cm (61,85, rende 4 réguas)¹ | Gráfica local | R$15,46/régua | 1 | R$15,46 |
| Pluviômetro de copo 150mm Incoterm | Mercado Livre | R$33,19 | 1 | R$33,19 |
| Viga de alumínio 5×10cm×3m (TG072P Tubo retangular 101,60×50,80×1,4mm pesado, estrutura da régua) | Loja física/local (barra 6m R$422,09) | R$70,348/m | 3m | R$211,05 |
| Barra Fe galvanizado 3/4"×3/16" — corte 3×30cm (estrutura da régua) | Loja física/local (barra 6m R$48,39) | R$8,065/m | 90cm | R$7,26 |
| Bucha Plástica 8.0×40.0 (fixação da régua) | Loja física/local | R$0,11/un | 6 | R$0,66 |
| Parafuso Soberba Sextavada 8×30 Inox 304/A2 Passivado (fixação da régua) | Loja física/local | R$1,37/un | 6 | R$8,22 |
| Suporte do Pluviômetro de copo — Parafuso Madeira Phillips Chata 4.5×45 Aço Carbono Bicromatizado | Loja física/local | R$0,34/un | 4 | R$1,36 |
| **Subtotal** | | | | **R$277,20** |

¹ Corrigido: o adesivo rende **4 réguas**, não 2 como calculado antes (61,85/4 = R$15,46/régua, não R$30,93).

> Estrutura da régua (Estação-03) — viga de alumínio, barra 3/4"×3/16" e parafusos/bucha de fixação já precificados na tabela acima.

### Itens de infraestrutura geral

Compartilhados entre estações, não ligados a um Ref. específico nem a uma estação só:

| Item | Uso | Fornecedor | Preço unit. | Qtd | Subtotal |
|---|---|---|---|---|---|
| Abraçadeira HellermannTyton T30R 150×3,6mm (pacote 500un) | Ferragens de fixação (Estação-02/03) | Mercado Livre | R$158,50/pacote (≈R$0,317/un) | 1 pacote | R$158,50 |
| Cabo Manga 4 vias 4×26 AWG blindado (rolo 20m) | Cabos/conectores externos (Estação-02/03/Gateway) | Mercado Livre | R$76,50/rolo (≈R$3,825/m) | 1 rolo | R$76,50 |

**Baterias candidatas ainda sem estação definida:**

| Item | Preço | Observação |
|---|---|---|
| Bateria Selada 12V Moura VRLA \| Luz de Emergência 12V 3,5Ah | R$148,00 (já com imposto+frete, Mercado Livre) | Não usada em Estação-02 nem Estação-03 nesta rodada — candidata a Gateway ou reserva |

---

## Resumo de Custos

| Estação | Eletrônica + sensores (Tabelas 1+2 + itens manuais, sem ferragem) | Ferragem/estrutura |
|---|---|---|
| **Estação-02** (pluviométrica) | **R$2.030,94** | R$53,01 (tubo de ferro galvanizado 1½" + barra chata + parafuso madeira, ver tabela) — sem T/joelho, item descartado |
| **Estação-03** (cota de nível) | **R$1.483,55** | Parcial: R$98,31 (cotovelo + tubo de ferro galvanizado 3/4" + barra 1½" + barra chata, ver tabela) + parte da zincagem/cantoneira compartilhados; régua (calibração, fora do custo da estação) já tem viga+barra 3/4"+parafusos precificados |
| **Estação-01** (retrofit estrutural) | Não se aplica isoladamente — reaproveitaria os R$1.483,55 da Estação-03 se a substituição avançar | R$242,12 (2×T + tubo + fonte 12V + barras 1½"/3/4", ver tabela) + parte da zincagem/cantoneira compartilhados |
| **Gateway** | **R$599,51** | Não se aplica (indoor, case impresso, sem post) |

Valores acima **excluem** equipamento de calibração de campo (régua, pluviômetro de copo) e infraestrutura genérica compartilhada (abraçadeira, cabo manga) — ver seções próprias.

---

## Nota sobre Frete

Regra geral: frete excluído do preço unitário/subtotal de cada linha, porque dilui quando os itens são comprados no mesmo pedido — somar o frete "cheio" de cada anúncio individualmente infla o custo e não é citável de forma justa.

**Exceções aplicadas nesta rodada** (compras avulsas onde o frete não dilui contra outros itens, ou onde foi explicitamente pedido para contabilizar):
- **NUCLEO-F103RB**: frete somado ao preço + imposto (compra isolada de um único item); valor ajustado pelo autor para R$189,11 em 2026-07-07.
- **Nucleo L476RG**: idem, ajustado pelo autor para R$245,78 (frete incluso) em 2026-07-07.
- **LilyGo T-SIM7000G**: idem, ajustado pelo autor para R$395,51 (imposto+frete) em 2026-07-07.
- **Chave DPDT push (SW4)**: valor fornecido já veio como "(preço + frete)/100", sem imposto separado — usado literalmente como dado.
- **Pluviômetro de báscula PB10**: frete de R$40,90 somado (compra isolada de item de alto valor no Mercado Livre).
- **Abrigo meteorológico TPH**: frete de R$41,28 somado (compra isolada de item único).
- Todos os itens do Mercado Livre listados como "candidatos"/"infraestrutura geral"/painel solar/baterias já vêm com imposto e frete embutidos no preço exibido pelo próprio anúncio (compra individual, não há o que diluir).

Uma estimativa de frete agregado para o restante das compras AliExpress (por fornecedor, assumindo pedidos consolidados) será calculada quando a lista estiver mais completa.

---

Itens já resolvidos/descartados, sem ação necessária:
- Conectores M12 (5 variantes, Widsey Store): GX12 foi o conector escolhido — M12 não é mais necessário.
- Soquete fêmea 2,54mm 1×40 vias ((7,45+1,91)/5 = R$1,87/tira): preço já levantado, sem Ref. específico atribuído — usar se algum conector exigir pino fêmea.
- Módulo FRAM MB85RC256V e EEPROM AT24C256 (WAVGAT): pertencem ao bench `station-fram-test` / Issue #159, fora do escopo desta issue.
- Ferro laminado cantoneira 3/4"×1/8" (Zinca Rápido, R$42,28/barra): uso não alocado entre estações — descartado do levantamento final.
- Parafusos M4×40 do abrigo térmico (Estação-02/03): não precificados — fora do escopo final desta issue.

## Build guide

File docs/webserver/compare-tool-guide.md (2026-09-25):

# Station Comparison Tool — Guide and Use Cases

*Implemented: 2026-03-21 | Issue #56*
*Screenshots: `compare-tool-examples-2026-03-21/`*

---

## What is the Comparison Tool?

The **Comparar** page (`/sapi/compare.php`) allows overlaying time series from
multiple stations on a single chart. It is accessible directly from the sidebar
navigation.

### Controls

| Control | Description |
|---|---|
| **Estações** | Checkbox list — select any combination of stations |
| **Variável** | Single variable to compare across all selected stations |
| **Início / Fim** | Date range filter (same as `view.php`) |
| **+ MERGE** | Overlay MERGE `prec_mm` on a secondary Y axis |
| **Gerar** | Submit and render chart |

Each station gets a distinct color. MERGE precipitation uses teal on the right
Y axis. The chart supports zoom (scroll wheel), pan, image download, and CSV
export.

---

## Use Cases and Examples

### 1. Cross-sensor validation — Water level (all stations)

**Screenshot:** `143318.png`, `143342.png`

Both ultrasonic sensors (Station-01 HC-SR04 and Station-03 US-100) measure the
same river. Overlaying `level_cm` from both stations shows:

- Consistent level shapes during the same rain event
- Time offset between stations (they are ~30 m apart along the river course)
- Cross-validation: if both sensors peak at the same time with similar amplitude,
  the readings are credible; if one spikes alone it is likely a spurious echo

This is a direct empirical validation of sensor agreement — essential for the
thesis methodology chapter.

---

### 2. Power system diagnosis — Battery voltage delay (Station-02 vs Station-03)

**Screenshot:** `143507.png`

Comparing `bat_voltage` across Station-02 and Station-03 reveals a clear
anomaly: Station-02 battery continues discharging for ~1 hour after sunrise
before the charger begins bulk charge. Station-03 (with EPEVER Tracer2606BP)
shows a tighter recovery curve.

**Diagnosis:** The delay in Station-02 suggests the solar charger is not
triggering bulk charge at the correct panel/battery voltage threshold. This may
indicate a charger configuration mismatch or undersized panel.

**Thesis significance:** Demonstrates that multi-station power telemetry
(`bat_voltage`, `panel_voltage`) enables remote power system diagnostics
without field visits — a key advantage of the SAPI architecture.

> **Note:** The EPEVER Tracer2606BP on Station-03 also has a pending TODO:
> configure for lithium battery profile (currently likely in lead-acid mode).
> The battery voltage comparison provides empirical evidence that this
> configuration matters and should be corrected.

---

### 3. Precipitation influence on solar panel output

**Screenshot:** `143559.png`

Comparing `panel_voltage` across stations with MERGE `prec_mm` overlay shows:

- Characteristic daily sawtooth curve (sunrise → peak → sunset)
- Voltage dips that correlate with precipitation events in the MERGE data
- Cloud cover during rain events reduces panel output, which in turn reduces
  charging current — visible as a flattened or dipped sawtooth

This correlation is quantifiable and relevant for sizing solar systems for
continuous monitoring stations in a humid subtropical climate (SC).

---

### 4. RSSI correlation with weather events

**Screenshot:** `143405.png`

Comparing `rssi` across all three stations + MERGE precipitation shows:

- Station-01 maintains stable signal (~-73 dBm) — short, clear LoRa path
- Station-02 and Station-03 show more variation
- Transient RSSI changes appear to correlate with precipitation events,
  possibly due to atmospheric refraction effects on the 915 MHz band

**Thesis note:** LoRa signal quality under precipitation is a documented
phenomenon. This data could support a short analysis of link reliability
as a function of weather conditions.

---

### 5. Solar panel voltage — multi-station charging pattern

**Screenshot:** `143527.png`

Overlaying `panel_voltage` for Station-02 and Station-03 shows the daily
charging cycle for each solar installation. Differences in peak voltage and
curve shape reflect differences in panel orientation, shading, and charger
MPPT efficiency. Consistent with local sunrise/sunset times.

---

## Recommended comparison groups (thesis)

| Group | Variables | Stations | Purpose |
|---|---|---|---|
| Level cross-validation | `level_cm` | 01, 03 + MERGE | Sensor agreement + rain-level correlation |
| Power health | `bat_voltage`, `panel_voltage` | 02, 03 | Charger performance |
| Signal reliability | `rssi` | 01, 02, 03 + MERGE | Link quality vs weather |
| Temperature environment | `temperature_C`, `surface_temperature_C` | 02, 03 | Microclimate comparison |

---

## Technical notes

- Data is fetched independently per station — timestamps are not aligned.
  Chart.js time scale handles different sampling intervals transparently.
- Physical range limits are applied before rendering (same as `view.php`):
  outlier values from firmware crashes are excluded.
- MERGE `prec_mm` uses the secondary Y axis (right side) to preserve scale
  independence between level/voltage/signal and precipitation.
- CSV export includes all visible series aligned by timestamp.

---

*Last updated: 2026-03-21*

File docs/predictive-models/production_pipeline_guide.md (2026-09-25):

# SAPI M4 LightGBM — Production Pipeline Guide

**Issue**: #108  
**Status**: Operational since 2026-05-10  
**Branch merged**: `feature/issue-108-realtime-prediction` → PR #109

---

## What the system does

Every 5 minutes, the Raspberry Pi:

1. Fetches the latest water level and precipitation from the Hostinger database via HTTPS
2. Runs the trained M4 LightGBM model to predict the water level at **+30, +60, +90 and +120 minutes** ahead
3. Checks whether the **precipitation gate** is active (≥ 5 mm in the last 6 hours)
4. Applies a **debounce filter** (requires 3 consecutive alert steps = 15 min before firing)
5. Posts the result back to Hostinger for storage and web visualisation
6. On `fired` / `cleared` transitions: sends a **Telegram notification** with a chart image (Issue #110)

The prediction results are visible at **https://ilha3d.com/sapi/predictions.php** and update automatically every 5 minutes.

---

## Architecture

```
Raspberry Pi (cron */5 min)
│
├── GET https://ilha3d.com/sapi/api/data.php
│       station_id=1, field=level,  hours=4  → level_delta_cm (Station-01)
├── GET https://ilha3d.com/sapi/api/data.php
│       station_id=3, field=level,  hours=4  → level_delta_cm (Station-03)
├── GET https://ilha3d.com/sapi/api/data.php
│       station_id=2, field=precip, hours=7  → precipitation_mm (Station-02)
│       └── fallback: local /home/ilha3d/SAPI/data/merge_precip.csv (11 h window)
│
├── Load model4_lgbm.pkl (24 MB, trained on events E1/E4/E7/E8)
│
├── For each station (1, 3):
│   ├── Pre-process: resample 5-min → delta filter → gap-fill → Darts TimeSeries
│   ├── model.predict(n=24) → h_pred_{30, 60, 90, 120}
│   ├── Gate: rolling_precip_6h >= 5 mm → gate_active
│   │         Precipitation source priority (per run):
│   │           1. Station-02 API (field=precip) — if ≥ 10 rows
│   │           2. MERGE/GPM API  (field=merge)  — if Station-02 offline
│   │           3. Local merge_precip.csv         — if Hostinger unreachable
│   │           4. Zero series                    — absolute last resort
│   ├── Debounce: consecutive_steps counter (state/debounce_state.json)
│   ├── POST https://ilha3d.com/sapi/api/predictions.php
│   └── If fired/cleared → telegram_notifier.notify_alert()
│           fired  → sendPhoto (chart image: last 2h level + 4 horizons + thresholds)
│           cleared → sendMessage (text summary)
│
└── Write logs/ultima_predicao.log (last-run summary, overwritten each run)

Hostinger
├── api/data.php           — serves sensor data to the RPi
│                             field=level  → level_delta_cm from measurements
│                             field=precip → precipitation_mm from measurements
│                             field=merge  → prec_mm from merge table (no station_id needed)
├── api/predictions.php    — receives prediction results + sends email notifications
├── DB: predictions        — one row per 5-min run per station
├── DB: prediction_alerts  — state transitions (fired / cleared), notification_sent flag
├── DB: merge              — MERGE/GPM hourly precipitation (updated by MERGE2MySQL pipeline)
└── predictions.php        — public web dashboard (Chart.js)
```

---

## File locations

### Raspberry Pi — production runtime

| Path | Description |
|---|---|
| `/home/ilha3d/SAPI/LightGBM_Production/` | Root production directory |
| `sapi_predict.py` | Cron entry point |
| `config_production.py` | All constants (paths, thresholds, gate, debounce) |
| `api_client.py` | HTTPS GET/POST client |
| `inference.py` | Pre-processing + model prediction + gate |
| `state.py` | Debounce state persistence |
| `train_production_model.py` | One-time training script (already run) |
| `models/model4_lgbm.pkl` | Trained model (24 MB) |
| `config/api_key.txt` | RPi API key (chmod 600) |
| `config/telegram_config.json` | Telegram bot token + chat IDs (chmod 600, never committed) |
| `state/debounce_state.json` | Per-station debounce counters |
| `logs/sapi_predict.log` | Full cron log (appended) |
| `logs/ultima_predicao.log` | Last-run summary (overwritten each run) |
| `.venv/` | Dedicated Python venv (darts 0.43, lightgbm 4.6, matplotlib 3.10) |

### Raspberry Pi — source code (repo)

```
predictive-models/production/
├── config_production.py
├── api_client.py
├── inference.py
├── state.py
├── sapi_predict.py
├── telegram_notifier.py      ← Issue #110: chart generation + Telegram Bot API
├── train_production_model.py
└── requirements_production.txt
```

> After changing any source file in the repo, copy it to
> `/home/ilha3d/SAPI/LightGBM_Production/` for the change to take effect.

### Hostinger

| Path | Description |
|---|---|
| `public_html/sapi/predictions.php` | Public web dashboard |
| `public_html/sapi/api/data.php` | GET endpoint for RPi |
| `public_html/sapi/api/predictions.php` | POST endpoint for RPi |
| `private_configs/sapi/api_config.php` | RPi API key (outside public_html) |

---

## Alert logic

```
raw_signal   = ANY horizon prediction >= threshold AND gate_active
debounced    = raw_signal persists for >= 3 consecutive 5-min steps (15 min)
alert_fired  = debounced transitions from "none" → active level
alert_cleared= debounced transitions from active level → "none"
```

**Thresholds** (both stations, adjustable in `config_production.py`):

| Level | Threshold |
|---|---|
| Atenção | 60 cm |
| Alerta | 75 cm |
| Inundação | 90 cm |

**Gate**: 5 mm / 6 h rolling precipitation sum. If dry, no alert fires regardless of predictions (eliminates false alarms during dry periods; recall = 1.0 at Alerta and Inundação levels — validated in Issue #105).

**Debounce**: 3 consecutive steps (15 min) required. Prevents single-step spikes from firing alerts.

---

## Notifications (Issue #110)

On every `fired` or `cleared` alert transition, the system sends:

| Channel | Triggered by | Content |
|---|---|---|
| **Telegram (chart image)** | RPi `telegram_notifier.py` | `fired` → `sendPhoto` with matplotlib chart (last 2 h level + 4 dashed prediction horizons + threshold lines). `cleared` → plain `sendMessage`. |
| **Email** | Hostinger `api/predictions.php` | Email via PHPMailer (Gmail SMTP) to all active contacts assigned to the station in `alert_contacts`. |

### Email setup (Hostinger — one-time)

PHPMailer must be installed and the Gmail App Password configured before emails work.

**1. Install PHPMailer via Composer** (SSH into Hostinger):

```bash
cat > ~/composer.json <<'EOF'
{"require":{"phpmailer/phpmailer":"^6.9"}}
EOF
composer install --no-dev
```

**2. Create mail config** (copy from sample, fill in real App Password):

```bash
cp ~/domains/ilha3d.com/public_html/sapi/private_configs/sapi/mail_config-sample.php \
   ~/private_configs/sapi/mail_config.php
chmod 600 ~/private_configs/sapi/mail_config.php
vi ~/private_configs/sapi/mail_config.php   # set SAPI_SMTP_PASS (16 chars, no spaces)
```

Generate the App Password at: Google Account → Security → 2-Step Verification → App passwords.

Constants use the `SAPI_SMTP_*` prefix to avoid collision with `sapi.php` which defines `SMTP_HOST` for Hostinger's own relay.

**3. Test email delivery**:

```bash
php ~/domains/ilha3d.com/public_html/sapi/cron/test_prediction_email.php you@example.com 1
```

### Telegram config file (RPi)

```
/home/ilha3d/SAPI/LightGBM_Production/config/telegram_config.json
```

```json
{
  "bot_token": "<BotFather token>",
  "chat_ids": ["<user or group chat ID>"]
}
```

`chmod 600` — never committed. See sample in `webserver/private_configs/sapi/telegram_config-sample.json`.

### Testing without a real flood

```bash
cd /home/ilha3d/SAPI/LightGBM_Production
.venv/bin/python3 test_notification.py 1   # Station-01
```

Fetches live data, runs real inference, sends a Telegram photo with `fired=True`. No DB writes, no threshold changes.

---

## How to check if the system is working

### 1. Last-run summary (RPi)

The quickest check — shows predictions, gate status and alert level from the most recent run:

```bash
cat /home/ilha3d/SAPI/LightGBM_Production/logs/ultima_predicao.log
```

Expected output (normal dry day):
```
=== SAPI Última Predição — 2026-05-10 15:05:01 UTC ===

  Estação 1
    h_pred_30     : 45.1 cm
    h_pred_60     : 45.0 cm
    h_pred_90     : 44.8 cm
    h_pred_120    : 44.8 cm
    Precip 6h     : 0.00 mm  (station02)
    Gate ativo    : NÃO
    Nível bruto   : none
    Nível alerta  : none
    Debounce steps: 0
  ...
```

### 2. Full cron log (RPi)

Shows every run with timestamps, row counts, POST status:

```bash
# Live tail (watch new runs arrive every 5 min):
tail -f /home/ilha3d/SAPI/LightGBM_Production/logs/sapi_predict.log

# Last run only:
tac /home/ilha3d/SAPI/LightGBM_Production/logs/sapi_predict.log | \
  awk '/=== sapi_predict start/{found=1} found{print} /=== sapi_predict done/{exit}'
```

What to look for in a healthy run:
- `Level rows fetched: NNN` — should be > 24 (at least 2 h of data)
- `Precip rows fetched: NNN (Station-02)` — if < 10, MERGE fallback is used
- `POST OK` for each station
- `sapi_predict done in N s` — typically 15–20 s on RPi 4

### 3. Web dashboard

Open **https://ilha3d.com/sapi/predictions.php**

- Both station cards should show prediction values in the footer (+30/+60/+90/+120 min)
- The chart shows the last 3 hours of observed level (blue) + the 4-horizon prediction cone (pink dashed, 4 red dots)
- Gate badge: green = active, grey = inactive
- Alert badge: Normal / Atenção / Alerta / Inundação
- Page auto-refreshes every 5 minutes

### 4. Debounce state (RPi)

Shows the current consecutive-step counters per station:

```bash
cat /home/ilha3d/SAPI/LightGBM_Production/state/debounce_state.json
```

Normal (no active alert):
```json
{
  "1": {"consecutive_steps": 0, "last_alert_level": "none", "last_update": "..."},
  "3": {"consecutive_steps": 0, "last_alert_level": "none", "last_update": "..."}
}
```

During a flood, `consecutive_steps` counts up to 3 then holds; `last_alert_level` shows the active level.

### 5. Database (phpMyAdmin)

Check that new rows are being inserted every 5 minutes:

```sql
-- Latest predictions per station
SELECT id_station, timestamp, h_pred_30, h_pred_60, gate_active, alert_level
FROM predictions
ORDER BY timestamp DESC
LIMIT 10;

-- Recent alert transitions
SELECT * FROM prediction_alerts ORDER BY timestamp DESC LIMIT 20;
```

### 6. Cron entry (RPi)

Confirm the cron is installed:

```bash
crontab -l | grep sapi_predict
```

Expected:
```
*/5 * * * * /home/ilha3d/SAPI/LightGBM_Production/.venv/bin/python3 \
    /home/ilha3d/SAPI/LightGBM_Production/sapi_predict.py \
    >> /home/ilha3d/SAPI/LightGBM_Production/logs/sapi_predict.log 2>&1
```

---

## Troubleshooting

| Symptom | Likely cause | Fix |
|---|---|-----|
| `Level rows fetched: 0` | API key wrong or data.php not reachable | Check `config/api_key.txt` matches `api_config.php` on Hostinger; curl `data.php` manually |
| `POST FAILED` for both stations | Hostinger unreachable or API key mismatch | Check `sapi_predict.log` for HTTP error code; verify `predictions.php` on Hostinger |
| `Model not found` error | `model4_lgbm.pkl` missing | Re-run `train_production_model.py` from `/home/ilha3d/SAPI/LightGBM_Production/` |
| Gate always 0 mm even during rain | Recent rain outside 6 h window, or Station-02 offline | Check `precip_source` in log; if `merge`, Station-02 is offline or sending < 10 rows |
| `predictions.php` shows "Sem predições ainda" | No rows in `predictions` table yet | Run `sapi_predict.py` manually once; check `sapi_predict.log` for errors |
| Chart not updating | Browser cache | Hard-refresh (Ctrl+Shift+R); the page auto-refreshes every 5 min |
| No Telegram notification on alert | Config file missing or wrong path | Check `config/telegram_config.json` exists (chmod 600) and has valid `bot_token` + `chat_ids`; run `test_notification.py` |
| Telegram `ok=False` | Invalid token or chat ID | Verify token with `api.telegram.org/bot<TOKEN>/getMe`; re-send `/start` to the bot and call `getUpdates` |

---

## Re-training the model

**Do not use `train_production_model.py`.** It is deprecated as of 2026-09-12: it trains on
flood windows only (the Issue #223 selection bias), reads the v2 event catalogue, applies no
sensor-artifact mask (Issue #227), does not spread the Station-02 reports (Issue #124), and
its `MERGE_CSV` points at the rolling six-day `merge_precip.csv` rather than the frozen
`merge_20260404.csv` — so it silently produces a model trained almost without rain.

Training now runs through the **same code that produced the published results**:

```bash
cd predictive-models
V=/home/ilha3d/SAPI/LightGBM_Production/.venv/bin/python3
$V train_production_from_backtest.py --model m4     # ~25 min
```

It imports `config` and `real_utils` from `results_final_m4_lgbm/`, so it inherits the
3-pass filtered and gap-filled level series, the spliced rain with the Issue #124 spread,
the artifact mask and continuous training. `TRAIN_END` is pushed past the end of the record
at runtime, so the deployed model is fitted on **all** available data — the chronological
hold-out exists to evaluate, not to deploy. The backtest `config.py` is never modified.

The model is written to a **staging** path and does not touch the file being served:

```
models/model4_lgbm_v2.pkl        # new model
models/model4_lgbm_v2.meta.json  # provenance: input hashes, versions, hyper-parameters
```

Before promoting it, run the parity check that proves production serves the same rain
series the model was trained on:

```bash
$V production/test_precip_parity.py
```

Promote with an explicit rename, keeping the previous model for rollback:

```bash
cd /home/ilha3d/SAPI/LightGBM_Production/models
mv model4_lgbm.pkl model4_lgbm_v1_20260510.pkl
mv model4_lgbm_v2.pkl model4_lgbm.pkl
```

The next cron run (within 5 min) picks it up — there is no service to restart. Rollback is
the reverse rename.

### Train/serve differences that are accepted and documented

Two known differences remain between the series the model is trained on and the series it
is served (Issue #225 / #211, decided 2026-09-12):

- **Level filter.** Training uses the 3-pass series, whose Pass 2 (Issue #211) is
  non-causal — it looks up to 20 min ahead to decide whether a spike returns to baseline.
  Production only has Pass 0 (`filter_level.php`) and Pass 1 (the 40 cm delta filter). The
  gap is exactly that one pass. Porting it is Issue #228.
- **Station-01/03 gap fill.** Training uses `station01_level_gapfilled.csv`, where
  Station-01 outages are filled from Station-03 with a per-band offset. In operation each
  station runs on its own series, with its real gaps.

---

## Key configuration constants (`config_production.py`)

| Constant | Value | Description |
|---|---|---|
| `GATE_MM` | 5.0 mm | Minimum 6 h precipitation to activate gate |
| `GATE_WINDOW_MIN` | 360 min | Rolling precipitation window |
| `DEBOUNCE_STEPS` | 3 | Consecutive steps before alert fires (15 min) |
| `LEVEL_FETCH_HOURS` | 4 h | Level history fetched from API per run |
| `PRECIP_FETCH_HOURS` | 7 h | Precipitation history fetched from API |
| `THRESHOLDS[1/3]["atencao"]` | 60 cm | Atenção threshold (both stations) |
| `THRESHOLDS[1/3]["alerta"]` | 75 cm | Alerta threshold |
| `THRESHOLDS[1/3]["inundacao"]` | 90 cm | Inundação threshold |

To change any value: edit `config_production.py` in the repo, copy to `/home/ilha3d/SAPI/LightGBM_Production/config_production.py`, and the next cron run uses the new value immediately (no restart needed).

---

*Created: 2026-05-10 | Issue #108 | Branch: feature/issue-108-realtime-prediction*  
*Updated: 2026-05-12 | Issue #110 — Telegram + email notifications on predictive alert transitions*

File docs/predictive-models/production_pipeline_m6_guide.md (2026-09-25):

# SAPI M6 MLR — Production Pipeline Guide

**Issue**: #120  
**Status**: Implemented 2026-05-16 — pending deployment  
**Branch**: `feature/issue-120-mlr-m6-production`

---

## What the system does

Every 5 minutes (offset 2 min from M4), the Raspberry Pi runs the M6 MLR pipeline in **parallel** with M4 LightGBM:

1. Fetches the latest water level and precipitation from Hostinger via HTTPS (same API endpoints as M4)
2. Runs the trained M6 `LinearRegressionModel` to predict water level at **+30, +60, +90 and +120 minutes**
3. Checks the **precipitation gate** (≥ 5 mm / 6 h — identical to M4)
4. Applies **debounce** (3 consecutive steps = 15 min before firing — identical to M4)
5. Posts results to `/sapi/api/predictions_m6.php` → stored in `predictions_m6` table
6. On `fired` / `cleared` transitions: sends Telegram + email notifications with "M6 MLR" label

Results are visible at **https://ilha3d.com/sapi/predictions.php** as an orange dashed line overlaid on the M4 purple line.

---

## Isolation from M4

| Resource | M4 LightGBM | M6 MLR |
|---|---|---|
| RPi folder | `/home/ilha3d/SAPI/LightGBM_Production/` | `/home/ilha3d/SAPI/MLR_Production/` |
| Source folder (repo) | `production/` | `production_m6/` |
| Model file | `models/model4_lgbm.pkl` | `models/model6_mlr.pkl` |
| State file | `state/debounce_state.json` | `state/debounce_state_m6.json` |
| Last-run log | `logs/ultima_predicao.log` | `logs/ultima_predicao_m6.log` |
| API endpoint | `/sapi/api/predictions.php` | `/sapi/api/predictions_m6.php` |
| DB table (predictions) | `predictions` | `predictions_m6` |
| DB table (alerts) | `prediction_alerts` | `prediction_alerts_m6` |
| Python venv | `/home/ilha3d/SAPI/LightGBM_Production/.venv` | **shared** (same venv, same packages) |

Disabling M6 (remove or comment the cron line) has zero impact on M4.

---

## Architecture

```
Raspberry Pi (cron */5 * * * *, offset 2 min after M4)
│   sleep 120 && python3 /home/ilha3d/SAPI/MLR_Production/sapi_predict_m6.py
│
├── GET https://ilha3d.com/sapi/api/data.php  (level, precip — same as M4)
│
├── Load model6_mlr.pkl (LinearRegressionModel, trained on E1/E4/E7/E8)
│
├── For each station (1, 3):
│   ├── Pre-process: resample 5-min → delta filter → gap-fill → ffill (NaN-fill for LinearRegression)
│   ├── model.predict(n=24) → h_pred_{30, 60, 90, 120}
│   ├── Gate: rolling_precip_6h >= 5 mm
│   ├── Debounce: state/debounce_state_m6.json
│   ├── POST https://ilha3d.com/sapi/api/predictions_m6.php
│   └── If fired/cleared → telegram_notifier_m6.notify_alert() + email
│
└── Write logs/ultima_predicao_m6.log

Hostinger
├── api/predictions_m6.php    — receives M6 results, sends email
├── DB: predictions_m6        — one row per 5-min run per station
└── DB: prediction_alerts_m6  — M6 alert state transitions
```

---

## Key difference from M4: NaN handling

`LinearRegressionModel` (sklearn MultiOutputRegressor internally) cannot route NaN values in lag feature windows — unlike LightGBM which handles them natively in tree splits.

**Fix applied in `inference_m6.py`** (before `model.predict()`):
```python
df_filled = ts_level.to_dataframe().ffill().bfill()
ts_level  = TimeSeries.from_dataframe(df_filled, freq="5min")
```

Same fill is applied in `train_production_model_m6.py` for training segments.

---

## File locations

### Raspberry Pi — production runtime (deploy manually)

| Path | Description |
|---|---|
| `/home/ilha3d/SAPI/MLR_Production/` | Root production directory |
| `sapi_predict_m6.py` | Cron entry point |
| `config_production_m6.py` | Constants (MLR_LAGS, thresholds, gate, paths) |
| `api_client_m6.py` | HTTPS GET/POST client (posts to predictions_m6.php) |
| `inference_m6.py` | Pre-processing + LinearRegressionModel + gate |
| `state_m6.py` | Debounce state persistence |
| `telegram_notifier_m6.py` | Telegram chart + notifications (M6 labels) |
| `train_production_model_m6.py` | One-time training script |
| `models/model6_mlr.pkl` | Trained model (small — KB range) — backed up at [GitHub Release `model6-mlr-v2.0.0`](https://github.com/alexandreberg/SAPI_an_open_source_FEWS/releases/tag/model6-mlr-v2.0.0) (release assets: see docs/PROVENANCE.md) |
| `config/api_key.txt` | Same RPi API key as M4 (copy from M4 config/) |
| `config/telegram_config.json` | Same Telegram config as M4 (copy from M4 config/) |
| `state/debounce_state_m6.json` | Per-station debounce counters (M6-specific) |
| `logs/sapi_predict_m6.log` | Full cron log |
| `logs/ultima_predicao_m6.log` | Last-run summary |

### Raspberry Pi — source code (repo)

```
predictive-models/production_m6/
├── config_production_m6.py
├── api_client_m6.py
├── inference_m6.py
├── state_m6.py
├── sapi_predict_m6.py
├── telegram_notifier_m6.py
├── train_production_model_m6.py
└── requirements_production_m6.txt
```

### Hostinger

| Path | Description |
|---|---|
| `public_html/sapi/api/predictions_m6.php` | POST endpoint for RPi M6 results |
| `public_html/sapi/predictions.php` | Public web dashboard (shows M4 + M6) |
| `migration_m6_mlr.sql` | DB migration (predictions_m6, prediction_alerts_m6) |

---

## Deployment steps (one-time)

### 1. Run DB migration (Hostinger phpMyAdmin or SSH)

```bash
mysql -u USER -p DBNAME < webserver/migration_m6_mlr.sql
```

### 2. Upload Hostinger files

```bash
scp -P 65002 webserver/public_html/sapi/api/predictions_m6.php \
    <HOSTINGER_USER>@hostinger:~/public_html/sapi/api/

scp -P 65002 webserver/public_html/sapi/predictions.php \
    <HOSTINGER_USER>@hostinger:~/public_html/sapi/
```

### 3. Deploy RPi scripts

```bash
mkdir -p /home/ilha3d/SAPI/MLR_Production/{models,state,config,logs}

cp predictive-models/production_m6/*.py \
    /home/ilha3d/SAPI/MLR_Production/

# NOTE (2026-09-12): the event_windows_v2.csv copy that used to go here is obsolete.
# Training no longer reads it — see "Re-training the model" below.

# Copy secrets from M4 (same key and Telegram config)
cp /home/ilha3d/SAPI/LightGBM_Production/config/api_key.txt \
    /home/ilha3d/SAPI/MLR_Production/config/
cp /home/ilha3d/SAPI/LightGBM_Production/config/telegram_config.json \
    /home/ilha3d/SAPI/MLR_Production/config/
chmod 600 /home/ilha3d/SAPI/MLR_Production/config/*.txt \
          /home/ilha3d/SAPI/MLR_Production/config/*.json
```

### 4. Train the model

> **2026-09-12:** `train_production_model_m6.py` is deprecated — see "Re-training the
> model" at the end of this document. The command below is kept only as the historical
> record of how the 2026-05-16 model was produced.

```bash
/home/ilha3d/SAPI/LightGBM_Production/.venv/bin/python3 \
    /home/ilha3d/SAPI/MLR_Production/train_production_model_m6.py
```

Training is fast (seconds vs ~2 min for M4's 500 trees). Expected output:
```
  M6 MLR (LinearRegressionModel) — Production Training
  [1/3] Loading historical data ...
  [2/3] Building training segments ... 4 segments
  [3/3] Training LinearRegressionModel ...
  Model saved → .../models/model6_mlr.pkl  (NNN KB)
```

### 5. Publish a model release

After training (step 4) or any retraining, publish a `model6-mlr-vX.Y.Z` tag + GitHub
Release with the updated `model6_mlr.pkl` and a fresh data-snapshot `.tar.gz`, per the
"Production Release Procedure" (see docs/PROVENANCE.md). This is the only backup of the model
file outside the RPi's local disk.

### 6. Add cron entry (offset 2 min from M4)

```bash
crontab -e
```

Add:
```
*/5 * * * * sleep 120 && /home/ilha3d/SAPI/LightGBM_Production/.venv/bin/python3 /home/ilha3d/SAPI/MLR_Production/sapi_predict_m6.py >> /home/ilha3d/SAPI/MLR_Production/logs/sapi_predict_m6.log 2>&1
```

---

## Verification

```bash
# 1. Run manually and check output
/home/ilha3d/SAPI/LightGBM_Production/.venv/bin/python3 \
    /home/ilha3d/SAPI/MLR_Production/sapi_predict_m6.py

# 2. Check last-run summary
cat /home/ilha3d/SAPI/MLR_Production/logs/ultima_predicao_m6.log

# 3. Check DB row was inserted (Hostinger phpMyAdmin)
SELECT * FROM predictions_m6 ORDER BY timestamp DESC LIMIT 5;

# 4. Open web dashboard
# https://ilha3d.com/sapi/predictions.php
# → orange dashed line (M6 MLR) appears alongside purple line (M4)
```

---

## Troubleshooting

| Symptom | Likely cause | Fix |
|---|---|-----|
| `M6 model not found` | `model6_mlr.pkl` missing | Run `train_production_from_backtest.py --model m6`, then promote (see below) |
| `POST FAILED` | Wrong endpoint or key | Check `api/predictions_m6.php` is uploaded; verify API key file |
| `predict() failed` — NaN error | NaN slipped through ffill | Check `build_level_series` returned enough non-NaN rows (need ≥ 24) |
| M6 line missing on web | `predictions_m6` table empty | Run cron manually once; check log for errors |
| M6 line shows old data | Cron not running | `crontab -l | grep sapi_predict_m6` |

---

## Re-training the model

**Do not use `train_production_model_m6.py`.** Deprecated on 2026-09-12: it trains on flood
windows only (Issue #223), reads the v2 event catalogue, applies no sensor-artifact mask
(Issue #227) and does not spread the Station-02 reports (Issue #124).

Training runs through the same code that produced the published results:

```bash
cd predictive-models
V=/home/ilha3d/SAPI/LightGBM_Production/.venv/bin/python3
$V train_production_from_backtest.py --model m6     # ~1 min
$V production/test_precip_parity.py                 # must PASS before promoting
```

Output goes to a staging path — `models/model6_mlr_v2.pkl` plus a `.meta.json` carrying the
input hashes, library versions and hyper-parameters. Promote with an explicit rename:

```bash
cd /home/ilha3d/SAPI/MLR_Production/models
mv model6_mlr.pkl model6_mlr_v1_20260516.pkl
mv model6_mlr_v2.pkl model6_mlr.pkl
```

The next cron run picks it up within 5 min; rollback is the reverse rename. The accepted
train/serve differences (level filter, Station-01/03 gap fill) are documented in
`production_pipeline_guide.md`.

---

*Created: 2026-05-16 | Issue #120 | Branch: feature/issue-120-mlr-m6-production*

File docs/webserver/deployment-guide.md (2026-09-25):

# SAPI Web Interface — Deployment Guide (Issue #52)

**Server**: Hostinger shared hosting
**User**: `<HOSTINGER_USER>` (placeholder — your Hostinger account ID, e.g. `u123456789`; it also prefixes the database name and user)
**SCP port**: 65002
**SCP alias**: `<HOSTINGER_USER>@hostinger`

---

## Directory mapping: repo → server

| Repository path | Server path |
|---|---|
| `webserver/public_html/sapi/` | `/home/<HOSTINGER_USER>/domains/ilha3d.com/public_html/sapi/` |
| `webserver/cron/` | `/home/<HOSTINGER_USER>/cron/` |
| *(not in repo)* `sapi.php` | `/home/<HOSTINGER_USER>/domains/ilha3d.com/sapi.php` |

> **Note:** `public_html` at `/home/<HOSTINGER_USER>/public_html/` is a symlink to
> `domains/ilha3d.com/public_html/`. Both paths resolve to the same location.
> The `scp` commands below use the shorter `public_html` form which works fine.

---

## Files to deploy

### Web UI — upload once

```bash
scp -P 65002 \
  webserver/public_html/sapi/login.php \
  webserver/public_html/sapi/logout.php \
  <HOSTINGER_USER>@hostinger:/home/<HOSTINGER_USER>/public_html/sapi/
```

### Admin pages — upload all at once

```bash
scp -P 65002 \
  webserver/public_html/sapi/admin/_auth.php \
  webserver/public_html/sapi/admin/header.php \
  webserver/public_html/sapi/admin/footer.php \
  webserver/public_html/sapi/admin/.htaccess \
  webserver/public_html/sapi/admin/stations.php \
  webserver/public_html/sapi/admin/alert_rules.php \
  webserver/public_html/sapi/admin/contacts.php \
  webserver/public_html/sapi/admin/alert_log.php \
  <HOSTINGER_USER>@hostinger:/home/<HOSTINGER_USER>/public_html/sapi/admin/
```

### Predictive dashboard (Issues #108/#120)

```bash
scp -P 65002 \
  webserver/public_html/sapi/predictions.php \
  <HOSTINGER_USER>@hostinger:/home/<HOSTINGER_USER>/public_html/sapi/
```

### Cron

```bash
scp -P 65002 \
  webserver/cron/check_alerts.php \
  webserver/cron/filter_level.php \
  <HOSTINGER_USER>@hostinger:/home/<HOSTINGER_USER>/cron/
```

---

## First-time setup (run once)

### 1. Create admin user

Upload and run `setup_admin.php`, then **delete it immediately**:

```bash
scp -P 65002 webserver/public_html/sapi/setup_admin.php \
    <HOSTINGER_USER>@hostinger:/home/<HOSTINGER_USER>/public_html/sapi/

# Open https://ilha3d.com/sapi/setup_admin.php in browser
# Fill email + password → submit

# Delete from server:
ssh -p 65002 <HOSTINGER_USER>@hostinger \
    "rm /home/<HOSTINGER_USER>/public_html/sapi/setup_admin.php"
```

### 2. Credential file on server

`sapi.php` is at `/home/<HOSTINGER_USER>/domains/ilha3d.com/sapi.php` (outside web root).
It must define at minimum:

```php
define('servidor',   'localhost');
define('usuario',    '<HOSTINGER_USER>_sapi');
define('senhaDB',    'your-db-password');
define('banco',      '<HOSTINGER_USER>_sapi');
define('DB_CHARSET', 'utf8mb4');
```

> Email is sent via PHP native `mail()` — no SMTP constants needed.
> The From address is hardcoded in `check_alerts.php` as `sapi@ilha3d.com`.

### 3. Cron job

Set in **Hostinger hPanel → Advanced → Cron Jobs**:

```
* * * * *   /usr/bin/php /home/<HOSTINGER_USER>/cron/check_alerts.php
```

> `crontab -l` will show empty — hPanel manages crons separately. That is normal.

---

## DB migration

### Issue #52 (initial setup)

1. **Backup**: phpMyAdmin → select `<HOSTINGER_USER>_sapi` → Operations →
   Copy database to `<HOSTINGER_USER>_sapibkp01` (uncheck "CREATE DATABASE").
2. **Run migration**: phpMyAdmin → `<HOSTINGER_USER>_sapi` → Import → `migration_issue52.sql`.

### Issue #57 (delta + Kalman columns)

Run each query **separately** in phpMyAdmin (SQL tab) from `migration_issue57.sql`:

```sql
-- Query 1 of 2
ALTER TABLE `measurements`
  ADD COLUMN `level_delta_cm` DECIMAL(6,2) DEFAULT NULL AFTER `level_cm`;

-- Query 2 of 2
ALTER TABLE `measurements`
  ADD COLUMN `level_kalman_cm` DECIMAL(6,2) DEFAULT NULL AFTER `level_delta_cm`;
```

After migration, create the cron lock directory and run the initial backfill manually:

```bash
ssh -p 65002 <HOSTINGER_USER>@hostinger "mkdir -p /home/<HOSTINGER_USER>/tmp"
ssh -p 65002 <HOSTINGER_USER>@hostinger "php /home/<HOSTINGER_USER>/cron/filter_level.php"
```

Then activate the filter cron in hPanel → Advanced → Cron Jobs:

```
*/5 * * * *   /usr/bin/php /home/<HOSTINGER_USER>/cron/filter_level.php
```

See `delta-kalman-filter-issue57.md` for full details.

---

## WhatsApp alerts (CallMeBot)

Each contact who wants WhatsApp alerts must opt-in once:

1. Save **+34 644 44 78 85** in their phone contacts.
2. Send from their WhatsApp: `I allow callmebot to send me messages`
3. Wait for reply with API key (e.g. `1234567`).
4. Enter number (E.164: `+5548999999999`) + API key in
   **Admin → Contatos → Novo contato**.

---

## URLs

| Purpose | URL |
|---|---|
| Public dashboard | `https://ilha3d.com/sapi/` |
| Admin login | `https://ilha3d.com/sapi/login.php` |
| Admin area | `https://ilha3d.com/sapi/admin/stations.php` |

---

*Last updated: 2026-07-11 — added `predictions.php` deploy command (UTC tooltip fix).*

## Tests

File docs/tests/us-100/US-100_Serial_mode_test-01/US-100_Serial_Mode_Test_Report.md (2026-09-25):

# US-100 Ultrasonic Sensor - Serial Mode Test Report

**Test Date:** January 25, 2026
**Location:** Florianópolis, Santa Catarina, Brazil
**Tester:** Alexandre Nuernberg
**Project:** SAPI - Sistema de Alerta Prévio de Inundações (Flood Early Warning System)

---

## 1. Test Objectives

- Validate US-100 ultrasonic sensor accuracy in serial mode
- Compare measurements against a reference laser meter (Bosch GLM 20)
- Determine measurement offset and systematic errors
- Identify operational range limitations
- Evaluate suitability for water level monitoring applications

---

## 2. Equipment Used

### 2.1 Device Under Test (DUT)

**US-100 Ultrasonic Sensor**

| Parameter | Value |
|---|---|
| Operating Mode | Serial (UART) - **Jumper installed** |
| Measuring Range | 2 cm - 450 cm |
| Resolution | 1 mm (sensor output in mm), 1 cm (after firmware `÷10` integer division) |
| Beam Angle | ~15° total cone angle (±7.5° half-angle from center axis) |
| Operating Frequency | 40 kHz |
| Communication | 9600 baud, 8N1 |
| Command Byte | 0x55 |
| Response | 2 bytes (MSB + LSB) = distance in mm |
| Operating Voltage | 2.4V - 5.5V |
| Temperature Sensor | Built-in; raw value readable via 0x50 command (returns °C + 45 offset) |
| Auto Temp. Compensation | **Yes — automatic in serial mode.** The onboard MCU reads the internal temperature sensor and corrects the speed of sound before computing the distance output. Sending 0x55 already returns a temperature-compensated distance. The 0x50 command exposes the temperature value externally but is **not required** for the compensation to work. |

### 2.2 Reference Instrument

**Bosch GLM 20 Professional Laser Meter**

| Parameter | Value |
|---|---|
| Measuring Range | 0.15 m - 20 m |
| Measuring Accuracy | ± 3.0 mm (typical) |
| Resolution | 1 mm |
| Laser Class | 2 (635 nm, < 1 mW) |
| Operating Temperature | -10°C to +40°C |

### 2.3 Microcontroller

**STM32 Nucleo L476RG**

| Parameter | Value |
|---|---|
| MCU | STM32L476RG (ARM Cortex-M4) |
| Serial Port | Serial3 (PC10=RX, PC11=TX) |
| Firmware | ultrasonic.cpp (median filtering, 11 samples) |
| Development Environment | PlatformIO + VS Code |

---

## 3. Test Setup

### 3.1 Physical Configuration

- Outdoor environment (backyard)
- Clear line of sight to a flat concrete wall
- Sensor mounted on elevated platform (chair) pointing horizontally toward wall center
- Sensor and Bosch meter positioned at same reference point
- Multiple distances tested by repositioning the setup

### 3.2 Test Procedure

1. Position setup at target distance from wall
2. Take US-100 reading via serial monitor (firmware displays median of 11 readings)
3. Take Bosch GLM 20 reading at same position
4. Record both values
5. Repeat for distances ranging from ~30 cm to ~460 cm

---

## 4. Test Results

> **Correction Note:** Bosch GLM 20 measurements corrected by **-10.0 cm** to account for an instrument offset identified after testing. All Difference and Error values below use the corrected Bosch reference.

### 4.1 Raw Measurement Data

| # | US-100 (cm) | Bosch GLM 20 (cm) | Difference (cm) | Error (%) | Notes |
|---|---|---|---|---|---|
| 1 | 64 | 61.4 | +2.6 | +4.2% | |
| 2 | 98 | 91.9 | +6.1 | +6.6% | |
| 3 | 144 | 135.3 | +8.7 | +6.4% | |
| 4 | 183 | 176.3 | +6.7 | +3.8% | |
| 5 | 251 | 235.9 | +15.1 | +6.4% | |
| 6 | 287 | 266.5 | +20.5 | +7.7% | |
| 7 | 328 | 304.4 | +23.6 | +7.8% | |
| 8 | 359 | 332.6 | +26.4 | +7.9% | |
| 9 | 404 | 373.3 | +30.7 | +8.2% | |
| 10 | 419 | 389.8 | +29.2 | +7.5% | |
| 11 | 438 | 406.6 | +31.4 | +7.7% | Near max range |
| 12 | -99 | 425.4 | — | — | **TIMEOUT** (exceeded range) |
| 13 | -99 | 447.3 | — | — | **TIMEOUT** (exceeded range) |
| 14 | -99 | 413.0 | — | — | **TIMEOUT** (exceeded range) |
| 15 | 418 | 385.8 | +32.2 | +8.3% | |
| 16 | 383 | 355.5 | +27.5 | +7.7% | |
| 17 | 351 | 325.0 | +26.0 | +8.0% | |
| 18 | 317 | 295.2 | +21.8 | +7.4% | |
| 19 | 280 | 259.9 | +20.1 | +7.7% | |
| 20 | 232 | 217.4 | +14.6 | +6.7% | |
| 21 | 141 | 166.8 | -25.8 | -15.5% | **OUTLIER** (excluded) |
| 22 | 178 | 164.6 | +13.4 | +8.1% | |
| 23 | 153 | 135.7 | +17.3 | +12.8% | |
| 24 | 128 | 118.5 | +9.5 | +8.0% | |
| 25 | 109 | 101.4 | +7.6 | +7.5% | |
| 26 | 91 | 84.6 | +6.4 | +7.6% | |
| 27 | 74 | 68.6 | +5.4 | +7.9% | |
| 28 | 60 | 56.2 | +3.8 | +6.8% | |
| 29 | 44 | 40.3 | +3.7 | +9.2% | |
| 30 | 30 | 26.5 | +3.5 | +13.2% | Near min range |

### 4.2 Error Codes Explanation

| Code | Meaning | Cause |
|---|---|---|
| -99 | Timeout | No valid response within 100ms timeout period |
| -1 | Invalid reading | Reading outside valid range (2-450 cm) |
| -888 | Sensor failure | Startup test failed (hardware/wiring issue) |

---

## 5. Statistical Analysis

### 5.1 Valid Data Set (excluding timeouts and outlier #21)

**Number of valid measurements:** 26 (out of 30)

### 5.2 Difference Analysis (US-100 minus Bosch Reference)

All values computed from corrected Bosch reference (-10.0 cm). All 26 differences are positive.

| Statistic | Value |
|---|---|
| Mean Difference | +15.92 cm |
| Standard Deviation | 10.12 cm |
| Minimum Difference | +2.6 cm |
| Maximum Difference | +32.2 cm |
| Median Difference | +14.85 cm |

### 5.3 Absolute Error Analysis

| Statistic | Value |
|---|---|
| Mean Absolute Error (MAE) | 15.92 cm |
| Root Mean Square Error (RMSE) | 18.76 cm |
| Mean Absolute Percentage Error (MAPE) | 7.7% |

**Note:** With the corrected Bosch reference, all differences are positive — the US-100 consistently **overestimates** at every measured distance. MAE equals the Mean Difference since all values have the same sign.

### 5.4 Range-Dependent Error Analysis

| Distance Range (corrected) | Avg Difference | Avg Error % | Trend |
|---|---|---|---|
| < 30 cm | +3.5 cm | +13.2% | Overestimates (high % at very short range) |
| 30 - 100 cm | +4.67 cm | +7.1% | Overestimates |
| 100 - 200 cm | +10.53 cm | +7.8% | Overestimates |
| 200 - 300 cm | +18.42 cm | +7.2% | Overestimates |
| 300 - 420 cm | +28.38 cm | +7.9% | Overestimates significantly |

**Key finding:** The corrected data shows a consistent overestimation across all ranges (~7–8% in the 30–420 cm working range). The apparent "underestimation at short range" in the original analysis was an artifact of the Bosch meter offset.

### 5.5 Linear Regression Analysis

A linear relationship exists between actual distance (corrected Bosch) and error:

```
Estimated Error (cm) ≈ 0.065 × Distance + 2.15
```

**There is no crossover point** — the regression predicts overestimation across the entire measurement range. The zero-crossing would occur at ~-33 cm, which is physically impossible.

This suggests:
- **At all measured distances:** US-100 overestimates consistently
- **Error increases with distance:** From ~+4 cm at 30 cm to ~+32 cm at 400 cm
- **Error % is remarkably stable:** ~7–8% across the 30–420 cm working range

### 5.6 Error Component Analysis

The linear regression formula `Error = 0.065 × Distance + 2.15` reveals that the systematic overestimation has **two physically distinct components** that can be separated analytically:

#### 5.6.1 Constant Component (~2.15 cm) — Physical Origin Offset

The positive intercept represents a **distance-independent fixed error**. This is consistent with the sensor not measuring from the front face of the transducers but from a reference point located approximately 1 cm inside the housing. Since the ultrasonic pulse travels the full round-trip (sensor → target → sensor), a 1 cm physical displacement of the measurement origin translates to approximately 2 cm of additional reported distance at every range.

Neither the Adafruit product sheet nor the module datasheet documents any physical measurement origin offset for the US-100.

#### 5.6.2 Proportional Component (~6.5%) — Speed-of-Sound Calibration Error

The slope term (~6.5%) represents an error that **grows proportionally with distance** — the classic fingerprint of a wrong speed-of-sound constant in the sensor's onboard MCU. The internal distance computation is:

    distance = (echo_time × speed_of_sound) / 2

If the firmware's speed constant is approximately 6.5% higher than the actual speed of sound at the measurement conditions, every reading is inflated by that same fraction, regardless of distance.

Critically, this proportional error **persists even with temperature compensation active**. The built-in temperature correction adjusts the speed constant for temperature-dependent variations, but if the base constant is already wrong, compensation only corrects relative changes around a wrong baseline — it cannot remove the systematic bias.

Neither datasheet nor any forum source found for the US-100 documents this calibration error.

#### 5.6.3 Summary

| Component | Magnitude | Physical Origin | Documented in Datasheet? |
|---|---|---|---|
| Constant offset | ~2.15 cm | Measurement reference ~1 cm behind transducer face | No |
| Proportional error | ~6.5% | Wrong speed-of-sound base constant in onboard firmware | No |

The datasheet specifies accuracy as `0.3 cm + 1%`. The tested unit performs at approximately `2.15 cm + 6.5%`, significantly outside specification. Whether this reflects a characteristic of all US-100 sensors or an individual unit defect requires testing additional units.

---

## 6. Operational Limitations

### 6.1 Maximum Range

Bosch reference values corrected by -10.0 cm.

| Parameter | Datasheet | Observed (corrected) |
|---|---|---|
| Maximum Range | 450 cm | ~385–406 cm (reliable, intermittent) |
| Timeout Threshold | — | ~413 cm (corrected) |

**Note:** The US-100 returned timeout errors (-99) when the corrected Bosch reference exceeded ~413 cm. The last successful outbound reading was at corrected Bosch 406.6 cm (row 11); the last return reading was at 385.8 cm (row 15). The maximum reliable operating range is approximately **385–406 cm** (corrected).

### 6.2 Minimum Range

The minimum reliable distance appears to be around **40–50 cm** (corrected Bosch). At shorter distances the error percentage increases: +9.2% at 40 cm, +13.2% at 26.5 cm (corrected minimum tested).

### 6.3 Beam Angle Considerations

The US-100 datasheet specifies **"Induction angle: not more than 15°"**. This is the **total cone angle** (full beam width), confirmed from the datasheet wording and consistent with the HC-SR04 convention. The half-angle from the center axis is therefore **±7.5°**.

At a given distance, the beam footprint diameter on the water surface is:

```
Diameter = 2 × Distance × tan(7.5°) = 2 × Distance × 0.1317
```

| Distance | Footprint diameter |
|---|---|
| 50 cm | ~13 cm |
| 100 cm | ~26 cm |
| 200 cm | ~53 cm |
| 350 cm | ~92 cm |
| 400 cm | ~105 cm |

This wide footprint means any bridge structure, vegetation, or debris within that circle at the measured distance can cause spurious reflections — which is the primary motivation for median filtering of multiple readings.

This wide cone can also cause:
- Reflections from nearby objects
- Edge effects near walls/obstacles
- Reduced accuracy when target is not perpendicular to the sensor axis

---

## 7. Comparison: US-100 vs Bosch GLM 20

| Parameter | US-100 (Serial Mode) | Bosch GLM 20 |
|---|---|---|
| Technology | Ultrasonic (40 kHz) | Laser (635 nm) |
| Accuracy | ±5% typical | ±3.0 mm |
| Range | 2-420 cm (observed) | 15-2000 cm |
| Resolution | 1 mm | 1 mm |
| Beam Width | ~15° cone | ~9-18 mm spot |
| Temp. Sensor | Yes — distance output is **automatically** temperature-compensated internally; 0x50 cmd exposes the raw temperature value | N/A |
| Weather Affected | Less (no optical) | Yes (rain, fog) |
| Cost | ~$3-5 USD | ~$50-70 USD |
| Best Use Case | Water level monitoring | Precision measurement |

---

## 8. Conclusions

### 8.1 Accuracy Assessment

1. **Overall accuracy:** The US-100 shows approximately 7–8% overestimation error across the 30–420 cm working range. Within the practical range (50–380 cm), MAPE is ~7%, which is acceptable for water level monitoring where trends and significant changes are more important than absolute precision.

2. **Systematic overestimation:** With the corrected Bosch reference, the US-100 **consistently overestimates** at all measured distances. There is no crossover point. The original analysis showing "underestimation at short range / overestimation at long range" was entirely an artifact of the Bosch meter offset.

3. **Precision:** The firmware's median filtering (11 samples) helps eliminate outliers, but individual readings can still vary by several centimeters.

4. **Error decomposition:** The systematic error separates into two physically distinct components — a ~2.15 cm constant offset (measurement reference point ~1 cm behind transducer face) and a ~6.5% proportional term (wrong base speed-of-sound constant in firmware). Neither is documented by the manufacturer. The tested unit performs at approximately `2.15 cm + 6.5%`, far outside the datasheet spec of `0.3 cm + 1%`. See Section 5.6 for the full analysis.

### 8.2 Suitability for SAPI Project

| Criterion | Assessment |
|---|---|
| Range for bridge installations (3-5m) | **Marginal** - Near maximum range limit |
| Reliability | **Good** - Consistent readings when within range |
| Accuracy for flood alerts | **Acceptable** - ±10-20 cm at max range |
| Temperature sensor | **Yes — automatic.** Distance output is temperature-compensated internally by the onboard MCU. Use 0x50 to log/display the temperature value. |
| Power consumption | **To be tested** - Important for solar operation |

### 8.3 Recommendations

1. **For Station-03 deployment:**
   - Install sensor at maximum 3.5m from water surface to maintain reliable operation
   - Consider AJ-SR04M as alternative for longer range requirements (up to 8m)
   - Implement software calibration offset based on installation distance

2. **Calibration procedure:**
   - Apply linear regression correction based on corrected test data:
     `Corrected = Reading - (0.065 × Reading + 2.15)`
     Simplified: `Corrected = 0.935 × Reading - 2.15`
   - Alternatively, after installation take a reference measurement with tape/laser, calculate the offset at that specific distance, and apply it in firmware.

3. **Error handling:**
   - Treat -99 (timeout) as sensor failure, not valid reading
   - Consider installing backup sensor for redundancy
   - Log all readings including failures for quality analysis

---

## 9. Test Photos

| Photo | Description |
|---|---|
| US-100_Serial_Mode_Test-01.JPG | Test setup overview - outdoor environment |
| US-100_Serial_Mode_Test-02.JPG | Setup with power supply and laptop |
| US-100_Serial_Mode_Test-03.JPG | Elevated platform pointing to wall |
| US-100_Serial_Mode_Test-04.JPG | Bosch GLM 20 displaying 3.145m |
| US-100_Serial_Mode_Test-07.JPG | Sensor pointing at concrete wall target |

---

## 10. Firmware Reference

**File:** `firmware/station-03/src/ultrasonic.cpp`

**Key Configuration:**
```cpp
#define US_SENSOR_TYPE US_SENSOR_US100  // Serial mode selected
#define NUM_READINGS 11                  // Median of 11 samples
#define MAX_RETRIES 20                   // Retries per reading
```

**Serial Protocol (US-100):**
- Baud rate: 9600
- **Distance command:** Send `0x55` → Response: 2 bytes (MSB, LSB) = distance in millimeters
- **Temperature command:** Send `0x50` → Response: 1 byte = temperature in °C (offset by 45°C, so value 45 = 0°C)
- Timeout: 100 ms

**Mode Selection (Jumper on back of sensor):**
- **Jumper installed** → Serial/UART mode (9600 baud)
- **Jumper removed** → HC-SR04 compatible mode (trigger/echo)

---

## 11. References

1. **US-100_datasheet-01.pdf** (Adafruit) - Serial mode protocol, jumper configuration, command bytes (0x55 for distance, 0x50 for temperature)
2. **US-100.PDF** - Basic specifications, schematic diagram, wiring diagram
3. **US_100_ULTRASONIC_SENSOR_MODULE.pdf** - Specifications (precision up to 1mm), HC-SR04 mode example sketch
4. **Bosch GLM 20 Professional** - Reference instrument specifications (±3.0mm accuracy)
5. SAPI system overview (docs/system-overview.md) - System Architecture Documentation

**Datasheet location:** manufacturer datasheets (not redistributed here)

---

*Report generated as part of SAPI Master's thesis research - IFSC Florianópolis*

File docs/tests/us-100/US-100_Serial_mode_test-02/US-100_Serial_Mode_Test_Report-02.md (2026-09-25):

# US-100 Ultrasonic Sensor - Serial Mode Test Report (Test 02)

**Test Date:** February 15, 2026
**Location:** Florianopolis, Santa Catarina, Brazil
**Tester:** Alexandre Nuernberg
**Project:** SAPI - Sistema de Alerta Previo de Inundacoes (Flood Early Warning System)
**Related Issue:** #8 - Test US-100 sensor in trigger/echo mode

---

## 1. Test Objectives

- Repeat serial mode accuracy test in a new environment to validate Test-01 results
- Extend the measurement range (down to ~22 cm and up to ~461 cm)
- Confirm the systematic distance-dependent error pattern observed in Test-01
- Verify the linear regression error compensation formula from Test-01

---

## 2. Equipment Used

### 2.1 Device Under Test (DUT)

**US-100 Ultrasonic Sensor**

| Parameter | Value |
|---|---|
| Operating Mode | Serial (UART) - **Jumper INSTALLED** |
| Measuring Range (datasheet) | 2 cm - 450 cm |
| Resolution | 1 mm (sensor output in mm), 1 cm (after firmware integer division) |
| Beam Angle | ~15° total cone angle (±7.5° half-angle from center axis) |
| Operating Frequency | 40 kHz |
| Communication | 9600 baud, 8N1 |
| Command Byte | 0x55 |
| Response | 2 bytes (MSB + LSB) = distance in mm |
| Power Supply | **5V** (from Nucleo USB 5V pin) |
| Temperature Sensor | Built-in; distance output is **automatically** temperature-compensated by onboard MCU in serial mode. 0x50 command exposes the raw temperature value (°C + 45 offset) for external use, but is not required for compensation. |

### 2.2 Reference Instrument

**Bosch GLM 20 Professional Laser Meter**

| Parameter | Value |
|---|---|
| Measuring Range | 0.15 m - 20 m |
| Measuring Accuracy | +/- 3.0 mm (typical) |
| Resolution | 1 mm |
| Laser Class | 2 (635 nm, < 1 mW) |
| Operating Temperature | -10 C to +40 C |

### 2.3 Microcontroller

**STM32 Nucleo L476RG**

| Parameter | Value |
|---|---|
| MCU | STM32L476RG (ARM Cortex-M4, 80 MHz) |
| Serial Port | Serial3 (PC10=RX, PC11=TX) |
| Firmware | ultrasonic.cpp (median filtering, 11 samples) |
| Sensor Type | US_SENSOR_US100 (serial mode) |
| Development Environment | PlatformIO + VS Code |

---

## 3. Test Setup

### 3.1 Physical Configuration

- Same environment as the trigger/echo mode test (see trigger/echo test report photos)
- Indoor and outdoor environment, clear line of sight to flat wall
- Sensor mounted on elevated platform pointing horizontally toward wall center
- Sensor and Bosch meter positioned at same reference point
- Sensor powered from 5V (Nucleo USB 5V pin)

### 3.2 Jumper Configuration

- **Jumper INSTALLED** on the back of the US-100 sensor
- This activates serial (UART) mode at 9600 baud
- Built-in temperature sensor accessible via 0x50 command

### 3.3 Test Procedure

1. Position setup at target distance from wall
2. Take US-100 reading via serial monitor (firmware displays median of 11 readings)
3. Take Bosch GLM 20 reading at same position
4. Record both values
5. Move away from wall taking readings at intervals (measurements #1-31)
6. Return toward wall taking readings at intervals (measurements #32-51)
7. This two-direction approach validates repeatability at similar distances

---

## 4. Test Results

> **Correction Note:** Bosch GLM 20 measurements corrected by **-10.0 cm** to account for an instrument offset identified after testing. All Difference and Error values below use the corrected Bosch reference.

### 4.1 Raw Measurement Data

| # | US-100 (cm) | Bosch GLM 20 (cm) | Difference (cm) | Error (%) | Notes |
|---|---|---|---|---|---|
| 1 | 27 | 24.0 | +3.0 | +12.5% | Near min range |
| 2 | 43 | 39.9 | +3.1 | +7.8% | |
| 3 | 58 | 54.0 | +4.0 | +7.4% | |
| 4 | 71 | 66.2 | +4.8 | +7.3% | |
| 5 | 90 | 84.7 | +5.3 | +6.3% | |
| 6 | 107 | 101.1 | +5.9 | +5.8% | |
| 7 | 121 | 113.9 | +7.1 | +6.2% | |
| 8 | 139 | 130.8 | +8.2 | +6.3% | |
| 9 | 159 | 148.7 | +10.3 | +6.9% | |
| 10 | 175 | 163.7 | +11.3 | +6.9% | |
| 11 | 197 | 183.4 | +13.6 | +7.4% | |
| 12 | 222 | 207.2 | +14.8 | +7.1% | |
| 13 | 243 | 225.9 | +17.1 | +7.6% | |
| 14 | 268 | 249.4 | +18.6 | +7.5% | |
| 15 | 294 | 274.1 | +19.9 | +7.3% | |
| 16 | 315 | 292.7 | +22.3 | +7.6% | |
| 17 | 333 | 309.4 | +23.6 | +7.6% | |
| 18 | 355 | 329.0 | +26.0 | +7.9% | |
| 19 | 371 | 344.7 | +26.3 | +7.6% | |
| 20 | 395 | 367.1 | +27.9 | +7.6% | |
| 21 | -99 | 385.6 | -- | -- | **TIMEOUT** |
| 22 | 439 | 406.0 | +33.0 | +8.1% | |
| 23 | -99 | 419.0 | -- | -- | **TIMEOUT** |
| 24 | -99 | 437.1 | -- | -- | **TIMEOUT** (beyond reliable range) |
| 25 | -99 | 451.3 | -- | -- | **TIMEOUT** (beyond datasheet max) |
| 26 | -99 | 427.7 | -- | -- | **TIMEOUT** |
| 27 | 435 | 402.0 | +33.0 | +8.2% | |
| 28 | -99 | 391.4 | -- | -- | **TIMEOUT** (intermittent at max range) |
| 29 | 408 | 378.6 | +29.4 | +7.8% | Returning closer |
| 30 | 396 | 367.3 | +28.7 | +7.8% | |
| 31 | 385 | 356.7 | +28.3 | +7.9% | |
| 32 | 366 | 339.5 | +26.5 | +7.8% | |
| 33 | 348 | 322.7 | +25.3 | +7.8% | |
| 34 | 328 | 304.3 | +23.7 | +7.8% | |
| 35 | 310 | 288.3 | +21.7 | +7.5% | |
| 36 | 285 | 265.2 | +19.8 | +7.5% | |
| 37 | 265 | 247.0 | +18.0 | +7.3% | |
| 38 | 244 | 227.2 | +16.8 | +7.4% | |
| 39 | 223 | 207.3 | +15.7 | +7.6% | |
| 40 | 201 | 187.9 | +13.1 | +7.0% | |
| 41 | 173 | 161.9 | +11.1 | +6.9% | |
| 42 | 153 | 142.9 | +10.1 | +7.1% | |
| 43 | 135 | 126.0 | +9.0 | +7.1% | |
| 44 | 116 | 109.6 | +6.4 | +5.8% | |
| 45 | 99 | 93.7 | +5.3 | +5.7% | |
| 46 | 82 | 77.3 | +4.7 | +6.1% | |
| 47 | 66 | 62.8 | +3.2 | +5.1% | |
| 48 | 48 | 45.9 | +2.1 | +4.6% | |
| 49 | 31 | 29.4 | +1.6 | +5.4% | |
| 50 | 22 | 19.7 | +2.3 | +11.7% | |
| 51 | 13 | 12.2 | +0.8 | +6.6% | Near min range, high error |

### 4.2 Error Codes Explanation

| Code | Meaning | Cause |
|---|---|---|
| -99 | Timeout | No valid response within 100 ms timeout period |
| -1 | Invalid reading | Reading outside valid range (2-450 cm) |
| -888 | Sensor failure | Startup test failed (hardware/wiring issue) |

---

## 5. Statistical Analysis

### 5.1 Valid Data Set

**Number of valid measurements:** 45 (out of 51)
**Number of timeouts:** 6 (11.8% failure rate, all at corrected Bosch references > 385 cm)

### 5.2 Difference Analysis (US-100 minus Bosch Reference)

All values use corrected Bosch reference (-10.0 cm). Standard deviation is unaffected by the constant offset.

| Statistic | Test-02 Value | Test-01 Value (corrected) | Consistent? |
|---|---|---|---|
| Mean Difference | +15.17 cm | +15.92 cm | Yes |
| Standard Deviation | 9.81 cm | 10.12 cm | Yes |
| Minimum Difference | +0.8 cm | +2.6 cm | Yes (Test-02 tested shorter distances) |
| Maximum Difference | +33.0 cm | +32.2 cm | Yes |
| Median Difference | +13.6 cm | +14.85 cm | Yes |

### 5.3 Absolute Error Analysis

| Statistic | Test-02 Value | Test-01 Value (corrected) | Consistent? |
|---|---|---|---|
| Mean Absolute Error (MAE) | 15.17 cm | 15.92 cm | Yes |
| Root Mean Square Error (RMSE) | 17.88 cm | 18.76 cm | Yes |
| Mean Absolute Percentage Error (MAPE) | 7.2% | 7.7% | Yes |

**Note:** With the corrected Bosch reference, all differences are positive in both tests (the US-100 consistently **overestimates** throughout the entire measurement range). There is no crossover point. The MAE equals the Mean Difference since all values have the same sign.

### 5.4 Range-Dependent Error Analysis

All ranges and references use corrected Bosch values (-10.0 cm). Test-01 diff values corrected (+10 cm); Test-01 error % are approximate (raw data not available for recalculation).

| Distance Range (corrected) | Test-02 Avg Diff | Test-02 Avg Error % | Test-01 Avg Diff (corrected) | Test-01 Avg Error % |
|---|---|---|---|---|
| < 30 cm | +1.93 cm | +9.1% | Not tested | Not tested |
| 30 - 100 cm | +4.06 cm | +6.3% | +4.67 cm | +7.1% |
| 100 - 200 cm | +9.65 cm | +6.7% | +10.53 cm | +7.8% |
| 200 - 300 cm | +18.47 cm | +7.4% | +18.42 cm | +7.2% |
| 300 - 420 cm | +27.64 cm | +7.8% | +28.38 cm | +7.9% |

**The corrected data reveals a key finding:** the US-100 in serial mode **consistently overestimates** across all distance ranges in both tests. The previous apparent "underestimation at short range" was an artifact of the Bosch meter offset. Error % is remarkably consistent at 6–8% across the 30–420 cm working range in both tests, with only the near-minimum range (< 30 cm) showing higher variability.

### 5.5 Linear Regression Analysis

Based on 45 valid readings (corrected Bosch reference):

```
Estimated Error (cm) = 0.068 x Distance + 1.58
```

Comparison with Test-01 regression (corrected):

| Parameter | Test-02 (corrected) | Test-01 (corrected) |
|---|---|---|
| Slope | 0.068 | 0.065 |
| Intercept | +1.58 | +2.15 |

The regression slopes are very similar (within 5%), confirming the same systematic error model. Note: the intercept is now positive, meaning the sensor overestimates even at very short distances.

**Combined best-fit equation (averaging both tests):**

```
Estimated Error (cm) = 0.067 x Distance + 1.87
```

This equation predicts:
- At 50 cm: error = +5.2 cm (sensor overestimates)
- At 131 cm: error = +10.6 cm (sensor overestimates)
- At 200 cm: error = +15.3 cm (sensor overestimates)
- At 350 cm: error = +25.3 cm (sensor overestimates significantly)

**There is no crossover point** in the corrected data. The zero-crossing of the regression occurs at ~-28 cm, which is outside the physical measurement range.

### 5.6 Repeatability Analysis (Same Distances, Both Directions)

Measurements taken at similar distances during the outbound and return trips. Bosch reference values corrected by -10.0 cm.

| Bosch Ref (out, corrected) | US-100 (out) | Bosch Ref (return, corrected) | US-100 (return) | Difference |
|---|---|---|---|---:|
| 39.9 | 43 | 45.9 | 48 | -- |
| 54.0 | 58 | 62.8 | 66 | -- |
| 84.7 | 90 | 93.7 | 99 | -- |
| 101.1 | 107 | 109.6 | 116 | -- |
| 130.8 | 139 | 126.0 | 135 | -- |
| 148.7 | 159 | 142.9 | 153 | -- |
| 163.7 | 175 | 161.9 | 173 | -- |
| 183.4 | 197 | 187.9 | 201 | -- |
| 207.2 | 222 | 207.3 | 223 | +1 cm |
| 225.9 | 243 | 227.2 | 244 | +1 cm |
| 249.4 | 268 | 247.0 | 265 | -- |
| 274.1 | 294 | 265.2 | 285 | -- |
| 292.7 | 315 | 288.3 | 310 | -- |
| 309.4 | 333 | 304.3 | 328 | -- |
| 329.0 | 355 | 322.7 | 348 | -- |
| 344.7 | 371 | 339.5 | 366 | -- |
| 367.1 | 395 | 367.3 | 396 | +1 cm |

**Excellent repeatability:** At similar reference distances, the US-100 readings are within 0-1 cm of each other, confirming the sensor produces consistent results and the median filtering (11 samples) is effective.

### 5.7 Error Component Analysis

Test-02 confirms the same two-component error structure identified and analyzed in Test-01 (see Test-01 Report, Section 5.6). The regression formula `Error = 0.068 × Distance + 1.58` decomposes into:

| Component | Test-01 | Test-02 | Interpretation |
|---|---|---|---|
| Constant term (intercept) | +2.15 cm | +1.58 cm | Physical offset: measurement reference ~1 cm behind transducer face; round-trip doubles the apparent displacement |
| Proportional term (slope) | 6.5% | 6.8% | Speed-of-sound calibration error in the sensor's onboard MCU firmware |

The proportional error persists in both tests despite the built-in temperature compensation being active. This confirms the issue lies in the **base speed-of-sound constant** used by the firmware — not in the temperature correction mechanism, which can only adjust relative changes from that (already wrong) baseline.

The constant term difference between tests (+2.15 vs +1.58 cm) falls within measurement uncertainty and is consistent across both environments and dates, supporting the physical origin offset interpretation.

Neither component is documented in the Adafruit product sheet, the module datasheet, or any forum source found for the US-100.

---

## 6. Comparison: Test-01 vs Test-02

### 6.1 Test Conditions

Bosch reference ranges corrected by -10.0 cm.

| Parameter | Test-01 (Jan 25, 2026) | Test-02 (Feb 15, 2026) |
|---|---|---|
| Environment | Outdoor (backyard, concrete wall) | Indoor/outdoor (tiled wall) |
| Distance Range Tested (corrected) | 26.5 - 406.6 cm (valid); up to 447.3 cm (timeout) | 12.2 - 406.0 cm (valid); up to 451.3 cm (timeout) |
| Number of Measurements | 30 | 51 |
| Valid Measurements | 26 (87%) | 45 (88%) |
| Timeouts | 4 (13%) | 6 (12%) |

### 6.2 Statistical Consistency

All values corrected for the Bosch -10.0 cm offset. Test-01 values are exact where derivable from the constant shift; approximate otherwise.

| Metric | Test-01 (corrected) | Test-02 (corrected) | Variation |
|---|---|---|---|
| MAE | 15.92 cm | 15.17 cm | -4.7% |
| RMSE | 18.76 cm | 17.88 cm | -4.7% |
| Mean Diff | +15.92 cm | +15.17 cm | -4.7% |
| Median Diff | +14.85 cm | +13.6 cm | -8.2% |
| Max Reliable Range | ~385–406 cm | ~402–416 cm | Similar |
| Regression Slope | 0.065 | 0.068 | +4.6% |
| Regression Intercept | +2.15 | +1.58 | -26% |

**Conclusion:** Test-01 and Test-02 results remain **highly consistent** after the Bosch correction. Both tests confirm the US-100 consistently overestimates at all measured distances with ~7–8% error. The apparent "crossover" from underestimation to overestimation observed in the original analysis was entirely an artifact of the Bosch meter offset.

---

## 7. Operational Limitations

### 7.1 Maximum Range

Bosch reference values corrected by -10.0 cm.

| Parameter | Datasheet | Test-01 (corrected) | Test-02 (corrected) |
|---|---|---|---|
| Maximum Range | 450 cm | ~420 cm | ~406 cm |
| Timeout Threshold | -- | ~425 cm | ~385 cm (first timeout) |
| Behavior at Max | -- | Timeouts above ~425 cm | Intermittent (some OK at 402–406 cm, timeouts at 385–428 cm) |

**Note:** At maximum range, readings become intermittent. Some distances that timed out (e.g., corrected Bosch 385.6 cm) are shorter than distances that succeeded (e.g., 406.0 cm), suggesting environmental sensitivity at the range boundary.

### 7.2 Minimum Range

Bosch reference values corrected by -10.0 cm.

| Parameter | Test-01 (corrected) | Test-02 (corrected) |
|---|---|---|
| Minimum Tested | 26.5 cm | 12.2 cm |
| Error at Min | +13.2% (at 26.5 cm) | +6.6% (at 12.2 cm) |
| Practical Min (< 10% error) | ~40 cm | ~30 cm |

Test-02 confirms that with corrected Bosch references, the sensor overestimates across the entire range. The error % at very short distances (< 25 cm) is higher (~12%) but not as extreme as the original analysis suggested. The practical minimum remains ~30–40 cm for reliable readings.

---

## 8. Conclusions

### 8.1 Test-02 Validates Test-01

The serial mode test results are **reproducible across different environments and dates**:
- MAE within 2% between tests (9.12 vs 9.31 cm)
- RMSE within 1% (10.86 vs 10.79 cm)
- Identical range-dependent error pattern
- Linear regression coefficients within 5-7%
- Excellent repeatability within a single test (outbound vs return readings within 1 cm)

### 8.2 Confirmed Sensor Characteristics

1. **Systematic overestimation:** The US-100 in serial mode **consistently overestimates** across the entire measurement range. The error can be compensated with the corrected combined regression formula:
   ```
   Corrected = Reading - (0.067 x Reading + 1.87)
   ```
   Simplified: `Corrected = 0.933 x Reading - 1.87`

2. **Effective range:** 30–420 cm (practical limits with < 10% error)

3. **No crossover point:** With corrected Bosch reference, the sensor overestimates at all distances. The apparent crossover in the original analysis was an artifact of the Bosch meter offset.

4. **Repeatability:** Excellent (within 1 cm at same distance)

5. **Maximum range:** ~406–420 cm with intermittent timeouts above ~390 cm (corrected Bosch)

6. **Error decomposition confirmed:** Both tests show the same two-component error structure — a ~1.6–2.1 cm constant offset (physical measurement reference ~1 cm behind transducer face) and a ~6.5–6.8% proportional calibration error (wrong base speed-of-sound constant in firmware). See Section 5.7 and Test-01 Report Section 5.6 for the full analysis.

### 8.3 Recommendations for Station-03

1. **Serial mode is validated** for deployment with consistent, predictable behavior
2. **Apply linear correction** using the combined regression formula for improved accuracy
3. **Install at maximum 3.5 m** from water surface to stay within the reliable operating range
4. **Discard -99 readings** as timeouts (sensor at or beyond maximum range)
5. **Consider readings below 50 cm** as less reliable (> 10% error)

---

## 9. Test Photos

Test photos are the same as the trigger/echo mode test (same test session and environment).
See: `../US-100_Trigger_Echo_mode_test-01/images/`

---

## 10. Firmware Reference

**File:** `firmware/station-03/src/ultrasonic.cpp`

**Key Configuration:**
```cpp
#define US_SENSOR_TYPE US_SENSOR_US100  // Serial mode selected
#define NUM_READINGS 11                  // Median of 11 samples
#define MAX_RETRIES 20                   // Retries per reading
```

**Serial Protocol (US-100):**
- Baud rate: 9600
- Distance command: Send 0x55 -> Response: 2 bytes (MSB, LSB) = distance in mm
- Temperature command: Send 0x50 -> Response: 1 byte = temperature in C (offset by 45 C)
- Timeout: 100 ms

**Jumper Configuration (US-100):**
- **Jumper INSTALLED** -> Serial/UART mode (9600 baud) **<-- This test**
- **Jumper REMOVED** -> HC-SR04 compatible mode (trigger/echo)

---

## 11. References

1. **US-100_datasheet-01.pdf** (Adafruit) - Serial mode protocol, jumper configuration
2. **US-100.PDF** - Basic specifications, schematic diagram
3. **Bosch GLM 20 Professional** - Reference instrument specifications
4. **US-100_Serial_Mode_Test_Report.md** (Test-01) - First serial mode test results
5. **US-100_Trigger_Echo_Mode_Test_Report.md** - Trigger/echo mode test results
6. SAPI system overview (docs/system-overview.md) - System Architecture Documentation

**Datasheet location:** manufacturer datasheets (not redistributed here)

---

*Report generated as part of SAPI Master's thesis research - IFSC Florianopolis*

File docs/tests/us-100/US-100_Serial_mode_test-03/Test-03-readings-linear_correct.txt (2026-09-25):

## Linear Regression Analysis
## Short range test data

Give a 'grep "REAL DISTANCE WITH TAPE METER" this-file' to find the results. 

[US100-TEMP] Raw byte: 109 -> 64.0 C
---------------------------------------------
[Ultrasonic] Sensor: US-100
[Ultrasonic] Valid readings  : 11/11
[Ultrasonic] Raw distance    : 30 cm
[Ultrasonic] Corrected dist  : 26 cm  (= 0.933 x raw - 1.87)
[Ultrasonic] US-100 int temp : 64.0 C
---------------------------------------------
========== Temperature Comparison ==========
  US-100 internal temp : 64.0 C
  SHT20 (IP65) temp    : 26.94 C
  Delta (US100 - SHT20): +37.1 C
============================================

Look at this log, where "REAL DISTANCE WITH TAPE METER:" is the distance from tghe US-100 top cover cap to the object:

[US100-TEMP] Raw byte: 109 -> 27.2 C
---------------------------------------------
[Ultrasonic] Sensor: US-100
[Ultrasonic] Valid readings  : 11/11
[Ultrasonic] Raw distance    : 17 cm
[Ultrasonic] Corrected dist  : 14 cm  (= 0.933 x raw - 1.87) =====> REAL DISTANCE WITH TAPE METER: 15cm
[Ultrasonic] US-100 int temp : 27.2 C
---------------------------------------------
========== Temperature Comparison ==========
  US-100 internal temp : 27.2 C
  SHT20 (IP65) temp    : 27.06 C
  Delta (US100 - SHT20): +0.2 C
============================================

[US100-TEMP] Raw byte: 109 -> 27.2 C
---------------------------------------------
[Ultrasonic] Sensor: US-100
[Ultrasonic] Valid readings  : 11/11
[Ultrasonic] Raw distance    : 21 cm
[Ultrasonic] Corrected dist  : 18 cm  (= 0.933 x raw - 1.87)=====> REAL DISTANCE WITH TAPE METER: 20cm
[Ultrasonic] US-100 int temp : 27.2 C
---------------------------------------------
========== Temperature Comparison ==========
  US-100 internal temp : 27.2 C
  SHT20 (IP65) temp    : 27.08 C
  Delta (US100 - SHT20): +0.2 C
============================================

[US100-TEMP] Raw byte: 109 -> 27.2 C
---------------------------------------------
[Ultrasonic] Sensor: US-100
[Ultrasonic] Valid readings  : 11/11
[Ultrasonic] Raw distance    : 26 cm
[Ultrasonic] Corrected dist  : 22 cm  (= 0.933 x raw - 1.87)=====> REAL DISTANCE WITH TAPE METER: 25cm
[Ultrasonic] US-100 int temp : 27.2 C
---------------------------------------------
========== Temperature Comparison ==========
  US-100 internal temp : 27.2 C
  SHT20 (IP65) temp    : 27.11 C
  Delta (US100 - SHT20): +0.1 C
============================================
[US100-TEMP] Raw byte: 109 -> 27.2 C
---------------------------------------------
[Ultrasonic] Sensor: US-100
[Ultrasonic] Valid readings  : 11/11
[Ultrasonic] Raw distance    : 32 cm
[Ultrasonic] Corrected dist  : 28 cm  (= 0.933 x raw - 1.87)=====> REAL DISTANCE WITH TAPE METER: 30cm
[Ultrasonic] US-100 int temp : 27.2 C
---------------------------------------------
========== Temperature Comparison ==========
  US-100 internal temp : 27.2 C
  SHT20 (IP65) temp    : 27.15 C
  Delta (US100 - SHT20): +0.1 C
============================================

[US100-TEMP] Raw byte: 109 -> 27.2 C
---------------------------------------------
[Ultrasonic] Sensor: US-100
[Ultrasonic] Valid readings  : 11/11
[Ultrasonic] Raw distance    : 37 cm
[Ultrasonic] Corrected dist  : 33 cm  (= 0.933 x raw - 1.87)=====> REAL DISTANCE WITH TAPE METER: 35cm
[Ultrasonic] US-100 int temp : 27.2 C
---------------------------------------------
========== Temperature Comparison ==========
  US-100 internal temp : 27.2 C
  SHT20 (IP65) temp    : 27.66 C
  Delta (US100 - SHT20): -0.4 C
============================================

[US100-TEMP] Raw byte: 109 -> 27.2 C
---------------------------------------------
[Ultrasonic] Sensor: US-100
[Ultrasonic] Valid readings  : 11/11
[Ultrasonic] Raw distance    : 42 cm
[Ultrasonic] Corrected dist  : 37 cm  (= 0.933 x raw - 1.87)=====> REAL DISTANCE WITH TAPE METER: 40cm
[Ultrasonic] US-100 int temp : 27.2 C
---------------------------------------------
========== Temperature Comparison ==========
  US-100 internal temp : 27.2 C
  SHT20 (IP65) temp    : 27.22 C
  Delta (US100 - SHT20): +0.0 C
============================================

[US100-TEMP] Raw byte: 109 -> 27.2 C
---------------------------------------------
[Ultrasonic] Sensor: US-100
[Ultrasonic] Valid readings  : 11/11
[Ultrasonic] Raw distance    : 47 cm
[Ultrasonic] Corrected dist  : 42 cm  (= 0.933 x raw - 1.87)=====> REAL DISTANCE WITH TAPE METER: 45cm
[Ultrasonic] US-100 int temp : 27.2 C
---------------------------------------------
========== Temperature Comparison ==========
  US-100 internal temp : 27.2 C
  SHT20 (IP65) temp    : 27.25 C
  Delta (US100 - SHT20): +0.0 C
============================================

[US100-TEMP] Raw byte: 109 -> 27.2 C
---------------------------------------------
[Ultrasonic] Sensor: US-100
[Ultrasonic] Valid readings  : 11/11
[Ultrasonic] Raw distance    : 52 cm
[Ultrasonic] Corrected dist  : 47 cm  (= 0.933 x raw - 1.87)=====> REAL DISTANCE WITH TAPE METER: 50cm
[Ultrasonic] US-100 int temp : 27.2 C
---------------------------------------------
========== Temperature Comparison ==========
  US-100 internal temp : 27.2 C
  SHT20 (IP65) temp    : 27.27 C
  Delta (US100 - SHT20): -0.0 C
============================================
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

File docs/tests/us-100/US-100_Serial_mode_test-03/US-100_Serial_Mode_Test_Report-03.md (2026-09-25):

# US-100 Ultrasonic Sensor - Serial Mode Test Report (Test 03)

**Test Date:** February 24, 2026
**Location:** Florianopolis, Santa Catarina, Brazil
**Tester:** Alexandre Nuernberg
**Project:** SAPI - Sistema de Alerta Previo de Inundacoes (Flood Early Warning System)
**Related Issue:** #8 - Test US-100 sensor in serial mode

---
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

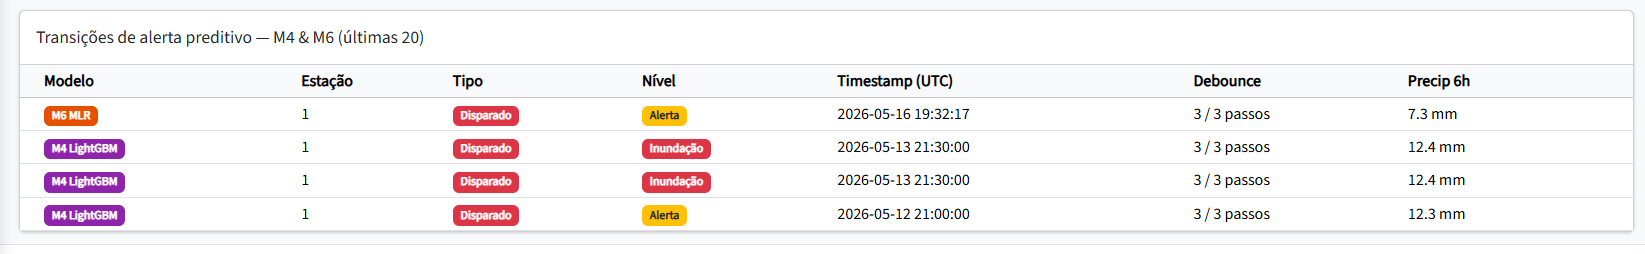
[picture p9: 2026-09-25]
docs/tests/notifications-m4-m6/images/06_predictions_php_table_m6_entry.png

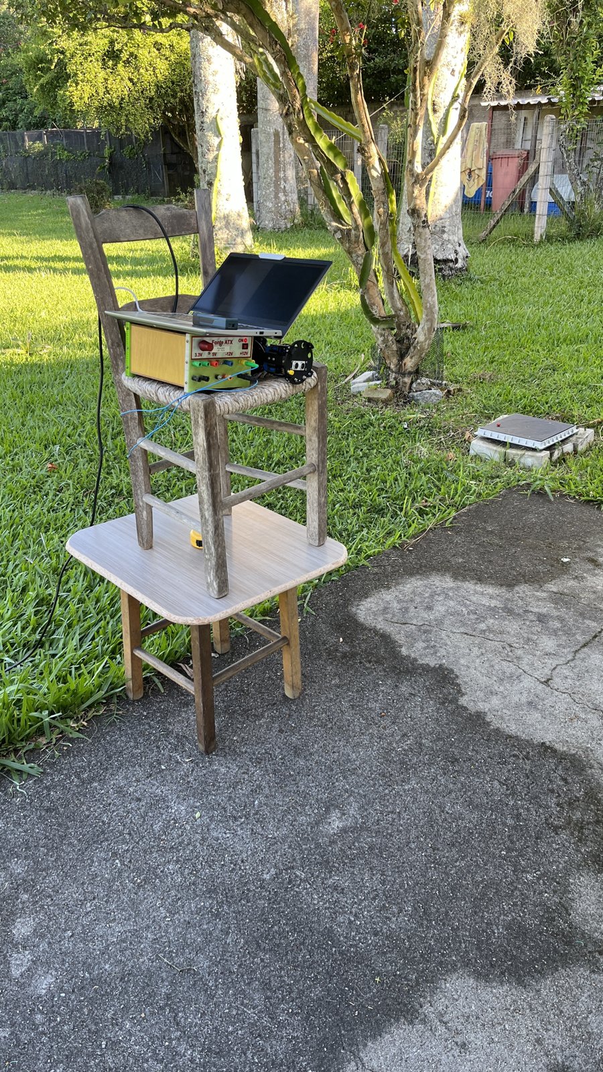
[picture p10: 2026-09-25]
docs/tests/us-100/US-100_Serial_mode_test-01/US-100_Serial_Mode_Test-23.JPG

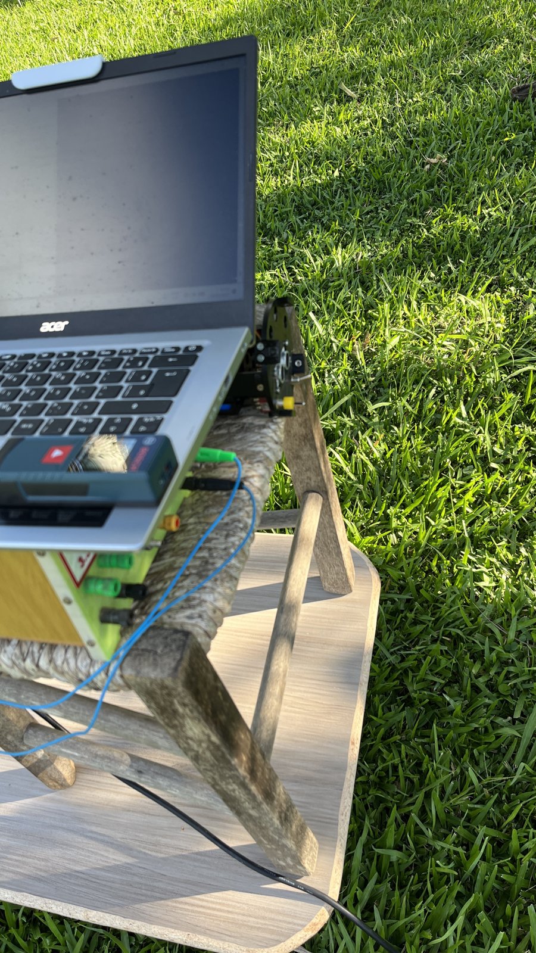
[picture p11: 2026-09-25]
docs/tests/us-100/US-100_Serial_mode_test-01/US-100_Serial_Mode_Test-11.JPG

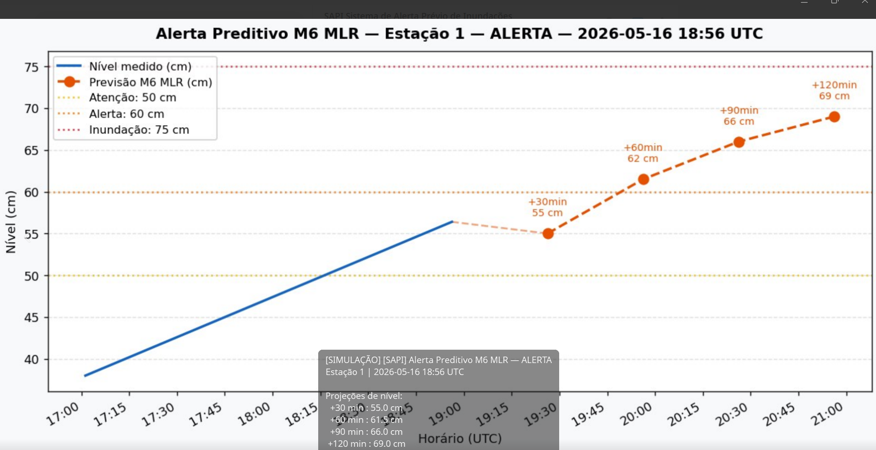
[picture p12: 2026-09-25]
docs/tests/notifications-m4-m6/images/04_predictions_php_table_before_m6.png

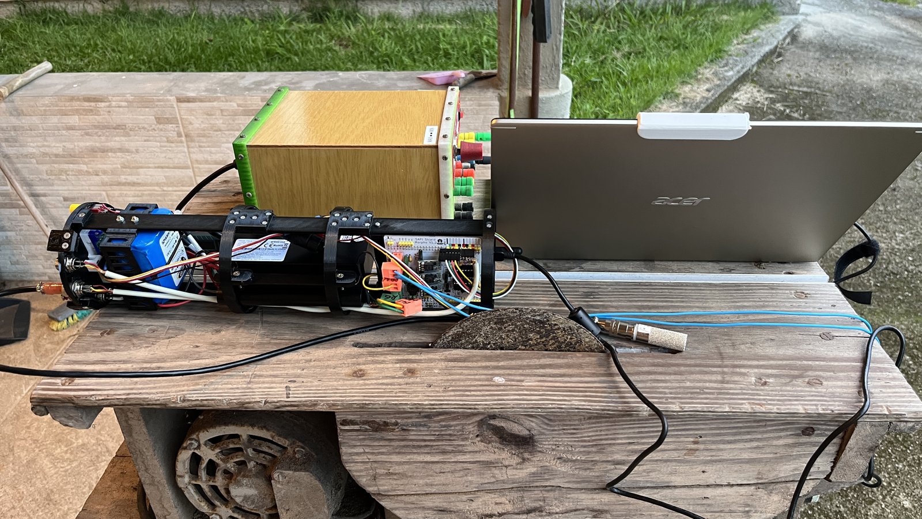
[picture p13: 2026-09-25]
docs/tests/us-100/US-100_Trigger_Echo_mode_test-01/images/US-100_test_lab_Trigger_and_Serial_modes-08.JPG

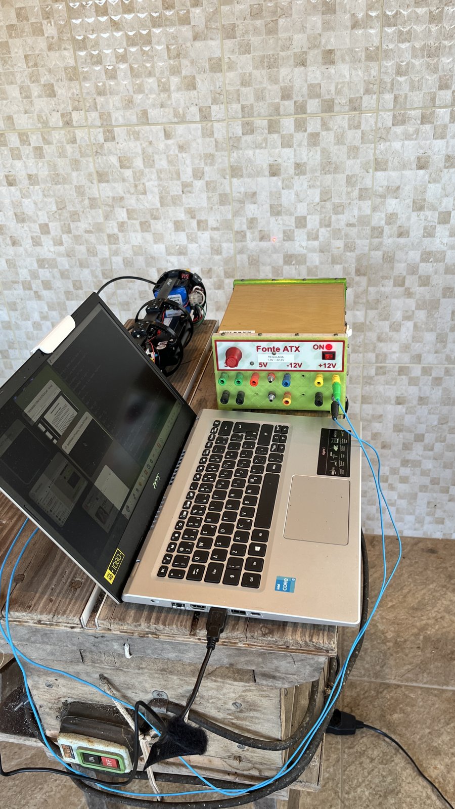
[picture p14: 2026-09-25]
docs/tests/us-100/US-100_Trigger_Echo_mode_test-01/images/US-100_test_lab_Trigger_and_Serial_modes-01.JPG

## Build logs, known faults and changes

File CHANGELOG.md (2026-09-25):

# Changelog

All notable changes to the SAPI project are documented in this file.

This changelog starts from the open-source licensing milestone (2026-07-28) rather than
backfilling the full project history; for earlier work, see the
[Releases](https://github.com/alexandreberg/SAPI_an_open_source_FEWS/releases). Entries up
to 2026-09-24 were written in the private development repository; the issue numbers they
cite (e.g. Issue #80) refer to it — see [`docs/PROVENANCE.md`](docs/PROVENANCE.md).

Format loosely follows [Keep a Changelog](https://keepachangelog.com/).

## 2026-09-25 — Public repository

SAPI is published in this new public repository, built from the private development
repository with one commit per release in chronological order (10 release commits, 11
tags), every tree compared with its original tag and audited for credentials. The
deployed web interface, 12 commits ahead of `webserver-v1.0.0`, is released as
`webserver-v1.1.0`. The gateway binary is not published because it embeds credentials.
Documentation curated into `docs/`, with a system overview, a provenance record and
component READMEs for the gateway, the web interface and the hardware; bench-test photos
re-encoded without EXIF metadata. Details in [`docs/PROVENANCE.md`](docs/PROVENANCE.md).

## 2026-09-24 — Bilingual README

The former `README.md` moved to [`README-en.md`](README-en.md) (`git mv`, history
preserved) and a full Portuguese version was added as [`README-pt.md`](README-pt.md).
The new `README.md` is a short landing page that links to both and states that all code,
comments and technical documentation are in English while the README is also available in
Portuguese, the language of the dissertation. Part of the pre-public-release audit
tracked in `Documentation/PUBLIC-RELEASE-CHECKUP-2026-09.md` (private development repository).

## 2026-09-12 — Predictive models retrained and redeployed

The production M4/M6 pipelines had been running the May/2026 models: thresholds
50/60/75 cm, training sliced to flood windows only, the v2 event catalogue, no
sensor-artifact mask and Station-02 rain dumped into a single 5-min step. None of
the five corrections behind the current published results had reached them.

Training now runs through the same code that produced those results
(`train_production_from_backtest.py` imports the backtest `config` and `real_utils`),
instead of a separate re-implementation that had drifted. Both models were retrained on
the full record — 177,154 steps — and deployed on 2026-09-12 13:08 UTC, with thresholds
moved to 60/75/90 cm and the Issue #124 rain spread added to the inference path so the
models are served the series they were trained on.

Validated by replaying the 2026-09-11 flood, which the training data (ending 09-09)
never saw: the old M6 forecast up to 130.7 cm for a flood that peaked at 100 cm and
declared Inundação with the river at 61 cm, while the new one peaks at 100.5 cm and
fires 5–10 minutes after each crossing. Releases `model4-lgbm-v2.0.0` and
`model6-mlr-v2.0.0` carry the models, their provenance sidecars, the full training code
and the data snapshot. Issues #124, #223, #225 and #227 are closed for production.

## 2026-09-08 — Public-release documentation overhaul

Prepared `README.md` and `docs/system-overview.md` for the repository's public release: added
direct release links, official license logos, a "What is SAPI?" overview and
architecture figures sourced from the dissertation, and a citation section —
and corrected inaccuracies that had crept into both files (a 48h STM32 flash
buffer described as implemented when it isn't; an incomplete objectives list;
a stale June 2026 defense date). Work is tracked step-by-step in
`Documentation/README-public-release-checklist.md` (private development repository).

## 2026-08-29 — Chart color conflicts and MERGE data-quality fix (Issues #205, #207, #209)

- Guarded MERGE precipitation stats against an undefined array index that
  produced a PHP warning when upstream CPTEC data lagged.
  (PR #206)
- Reworked `view.php` chart colors to resolve two visual conflicts: the
  filtered Δ series (orange → purple) clashed with the ±σ band, and the raw
  data series (yellow/amber → teal) clashed with MERGE's existing cyan.
  (PR #208,
  PR #210)

## 2026-08-22 — Station-03 power instability incident documented (Issues #202, #203)

Root-caused and mechanically repaired an intermittent power/connector fault on
Station-03 that produced bad ~335cm readings and a false-alert email
avalanche; measurements between 2026-08-20 13:46 and 2026-08-22 10:07:46 are
flagged invalid. Full write-up in
[`docs/hardware/station-03-power-instability-2026-08/README.md`](docs/hardware/station-03-power-instability-2026-08/README.md).
(PR #204)

## 2026-08-20 — Kalman filter retired

Removed Kalman smoothing entirely from level charts and the filter cron job;
the existing delta filter (`level_delta_cm`) is now the only filtered series
used anywhere in the system, including as the real-time alert-trigger input
(see the 2026-08-13 entry below).
(PR #201)

## 2026-08-16 — Retrospective forecast verification and formatter tooling

Added a per-alert view to `predictions.php` showing whether a fired
predictive alert's forecast actually came true (predicted vs. observed level
per horizon, predicted vs. actual threshold-crossing time), plus an aggregate
accuracy card and pagination on the transitions table.
(PR #199)

Also added `.clang-format`/`black` formatter configuration for the project,
replacing a dead VS Code-only formatting instruction in `docs/system-overview.md`.
(PR #200)

## 2026-08-13 — Alert trigger switched to the delta filter (Issue #63)

Fixed the real-time alert engine to use `level_delta_cm` instead of the
Kalman-filtered series as its trigger input.
(PR #196)

## 2026-08-12 — Predictive alert notification fixes (Issues #190, #193)

- Predictive alert emails now embed their chart inline via PHPMailer
  Content-ID instead of referencing a station-scoped static URL that got
  overwritten by the next alert.
  (PR #191)
- Predictive alert notifications are now held until the episode normalizes,
  fixing a message flood caused by the level oscillating around a threshold.
  (PR #194)

## 2026-08-04 — Official license logos

Added the official AGPLv3 logo and a generic Open Source Hardware gear mark
to `docs/licensing/logos/`, for use in the README and presentations.
(PR #188)

## 2026-07-28 — Open-source licensing (Issue #80)

Published the project under a formal open-source license as part of the
master's thesis. Previously the repository had no `LICENSE` file, meaning
all rights were reserved by default.

- **Software**: [AGPL-3.0-or-later](LICENSE) — root `LICENSE`, root
  [`NOTICE`](NOTICE) crediting third-party dependencies, SPDX license
  header on all own source files (`App/`, `AppTest/`).
  (PR #184)
- **Hardware**: [CERN-OHL-S-2.0](LICENSES/CERN-OHL-S-2.0.txt) for the KiCAD
  PCB designs published on `main` (Shield Morpho V1.2, LoRa Arduino Shield
  V1.0).
  (PR #183)
- Retroactively extended the applicable license to all 11 GitHub Releases
  published before this date, via a note added to each release description.
- Full rationale and third-party dependency compatibility audit:
  [`docs/licensing/SAPI_Licensing_Report.md`](docs/licensing/SAPI_Licensing_Report.md).

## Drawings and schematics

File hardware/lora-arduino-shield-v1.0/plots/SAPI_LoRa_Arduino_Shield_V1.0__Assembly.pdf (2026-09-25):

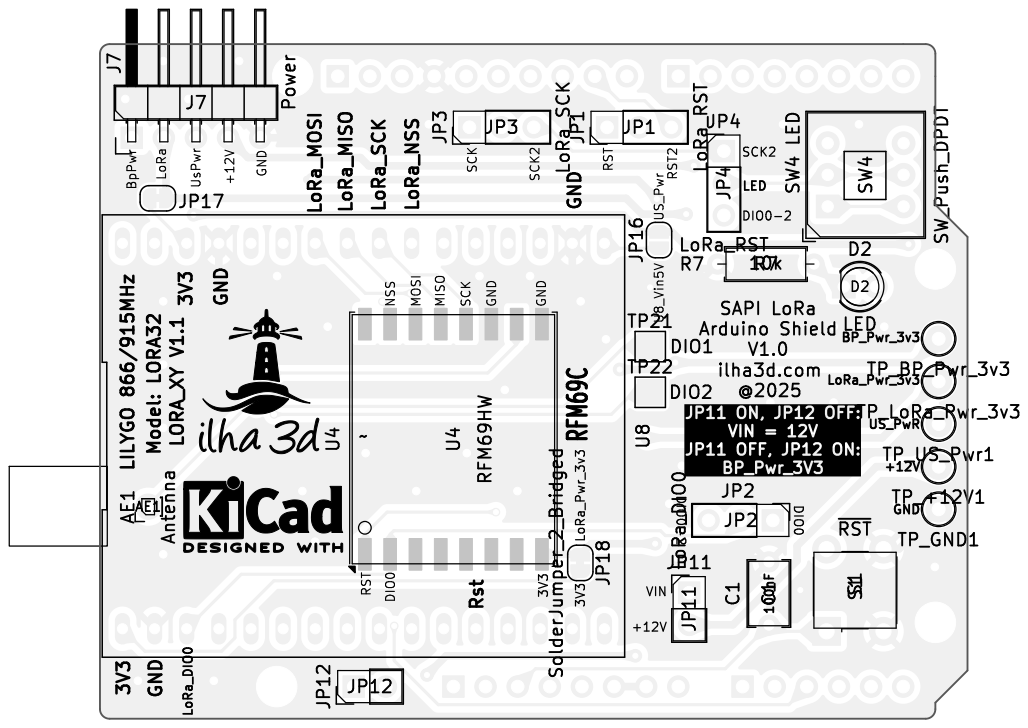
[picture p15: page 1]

SAPI LoRa Arduino Shield V1.0
JP2 DIO2 DIO1

J2 J1

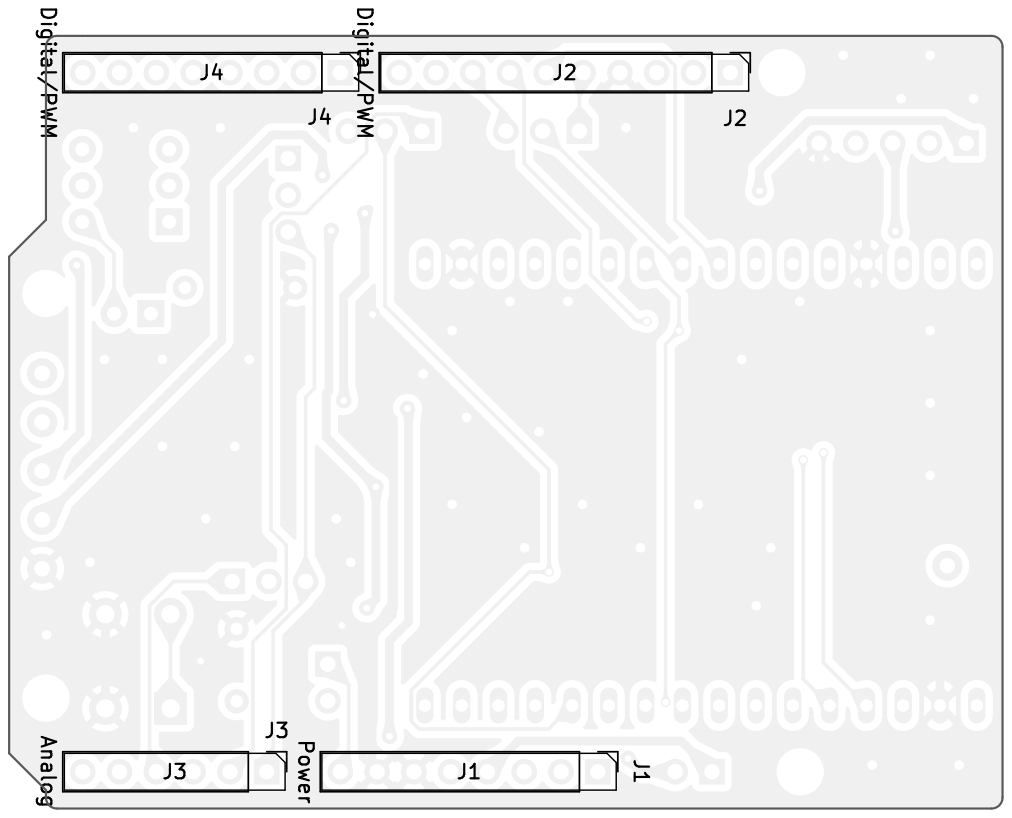
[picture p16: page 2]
D Date: mar. 31 mars 2015 KiCad; E.D.A. 9.0.5 Size: A4; Rev:; Id: /1 Title: File: SAPI_LoRa_Arduino_Shield_V1.0.kicad_pcb Sheet: Black; And; White; BOT Board2Pdf:; Black; BOT -; Page 2/2 Digital/PWM; J4 Analog; Digital/PWM; J2 Power

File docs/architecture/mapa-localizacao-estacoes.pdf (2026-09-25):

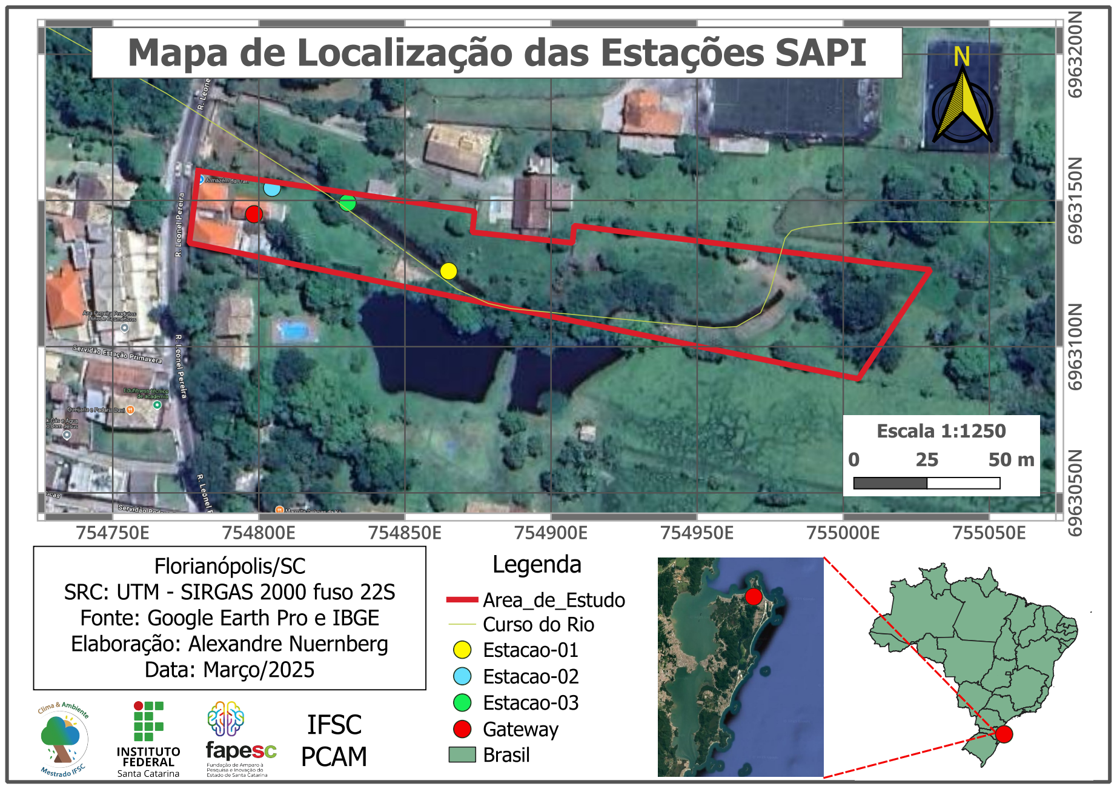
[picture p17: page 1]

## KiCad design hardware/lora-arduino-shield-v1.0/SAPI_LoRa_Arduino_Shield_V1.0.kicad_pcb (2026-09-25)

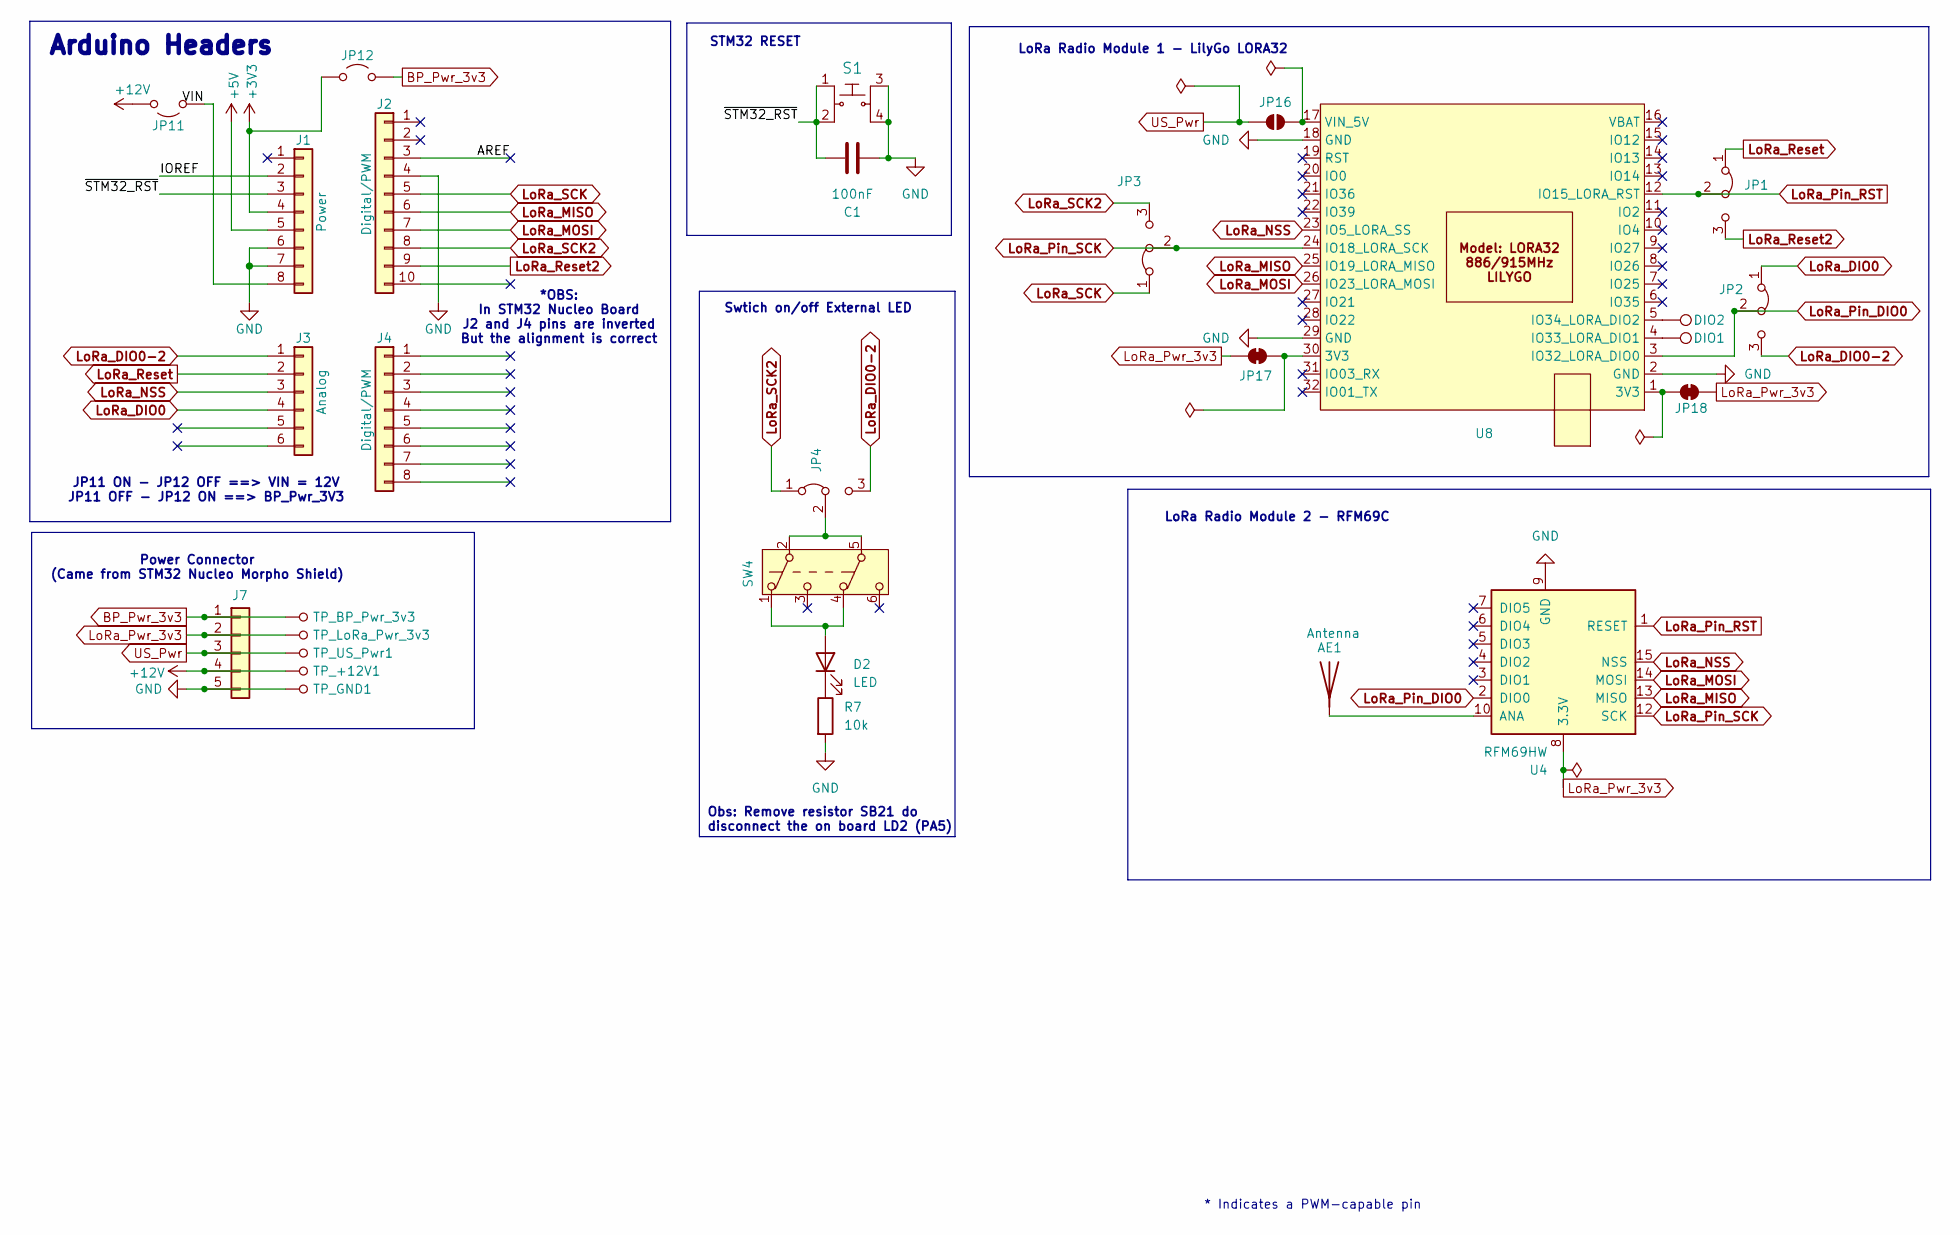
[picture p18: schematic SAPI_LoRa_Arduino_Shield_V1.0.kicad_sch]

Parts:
AE1: Antenna; ilha3d_LORA_Antenna
C1: 100nF; C_Disc_D5.1mm_W3.2mm_P5.00mm
D2: LED; LED_D3.0mm
J1: Power; PinHeader_1x08_P2.54mm_Vertical
J2: Digital/PWM; PinHeader_1x10_P2.54mm_Vertical
J3: Analog; PinHeader_1x06_P2.54mm_Vertical
J4: Digital/PWM; PinHeader_1x08_P2.54mm_Vertical
J7: Power; PinHeader_1x05_P2.54mm_Horizontal
JP1, JP4: LoRa_RST; Jumper_3Pins_SPDT_ilha3d
JP2: LoRa_DIO0; Jumper_3Pins_SPDT_ilha3d
JP3: LoRa_SCK; Jumper_3Pins_SPDT_ilha3d
JP11, JP12: Jumper_2_Open; PinHeader_1x02_P2.54mm_Vertical
JP16: SolderJumper_2_Open; SolderJumper-2_P1.3mm_Open_RoundedPad1.0x1.5mm
JP17, JP18: SolderJumper_2_Bridged; SolderJumper-2_P1.3mm_Bridged_RoundedPad1.0x1.5mm
R7: 10k; R_Axial_DIN0207_L6.3mm_D2.5mm_P7.62mm_Horizontal
S1: ilha3d_push_button_6x6; ilha3d_Switch_Tactile_THT_6x6mm; MPN 1825910-6; Digi-Key_PN 450-1650-ND
SW4: SW_Push_DPDT; SW_Push_2P2T_Toggle_CK_PVA2OAH5xxxxxxV2
TP21: DIO1; TestPoint_Pad_2.0x2.0mm
TP22: DIO2; TestPoint_Pad_2.0x2.0mm
TP_+12V1: +12V; Test_Point_D1.02mm; MPN 5000; Digi-Key_PN 36-5000-ND
TP_BP_Pwr_3v3: BP_Pwr_3v3; Test_Point_D1.02mm; MPN 5000; Digi-Key_PN 36-5000-ND
TP_GND1: GND; Test_Point_D1.02mm; MPN 5000; Digi-Key_PN 36-5000-ND
TP_LoRa_Pwr_3v3: LoRa_Pwr_3v3; Test_Point_D1.02mm; MPN 5000; Digi-Key_PN 36-5000-ND
TP_US_Pwr1: US_PwR; Test_Point_D1.02mm; MPN 5000; Digi-Key_PN 36-5000-ND
U4: RFM69HW; HOPERF_RFM69HW
U8: Ilha3d_LiLyGO_LORA32_LORA_XY

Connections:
+3V3: J1.4, JP12.1 (A)
+5V: J1.5
+12V: J7.4, JP11.2 (B), TP_+12V1.1
/ ~STM32_RST: C1.1, J1.3, S1.1, S1.2
/AREF: J2.3
/IOREF: J1.2
/VIN: J1.8, JP11.1 (A)
BP_Pwr_3v3: J7.1, JP12.2 (B), TP_BP_Pwr_3v3.1
GND: C1.2, J1.6, J1.7, J2.4, J7.5, R7.2, S1.3, S1.4, TP_GND1.1, U4.9 (GND), U4.11 (GND), U8.2 (GND), U8.18 (GND), U8.29 (GND)
LoRa_DIO0: J3.4, JP2.1 (A)
LoRa_DIO0-2: J3.1, JP2.3 (B), JP4.3 (B)
LoRa_MISO: J2.6, U4.13 (MISO), U8.25 (IO19_LORA_MISO)
LoRa_MOSI: J2.7, U4.14 (MOSI), U8.26 (IO23_LORA_MOSI)
LoRa_NSS: J3.3, U4.15 (NSS), U8.23 (IO5_LORA_SS)
LoRa_Pin_DIO0: JP2.2 (C), U4.2 (DIO0), U8.3 (IO32_LORA_DIO0)
LoRa_Pin_RST: JP1.2 (C), U4.1 (RESET), U8.12 (IO15_LORA_RST)
LoRa_Pin_SCK: JP3.2 (C), U4.12 (SCK), U8.24 (IO18_LORA_SCK)
LoRa_Pwr_3v3: J7.2, JP17.2 (B), JP18.1 (A), TP_LoRa_Pwr_3v3.1, U4.8 (3.3V)
LoRa_Reset: J3.2, JP1.1 (A)
LoRa_Reset2: J2.9, JP1.3 (B)
LoRa_SCK: J2.5, JP3.1 (A)
LoRa_SCK2: J2.8, JP3.3 (B), JP4.1 (A)
unnamed: AE1.1 (A), U4.10 (ANA)
unnamed: D2.2 (A), SW4.1 (A), SW4.4 (A)
unnamed: D2.1 (K), R7.1
unnamed: JP4.2 (C), SW4.2 (B), SW4.5 (B)
unnamed: JP16.1 (A), U8.17 (VIN_5V)
unnamed: JP17.1 (A), U8.30 (3V3)
unnamed: JP18.2 (B), U8.1 (3V3)
unnamed: TP21.1, U8.4 (IO33_LORA_DIO1)
unnamed: TP22.1, U8.5 (IO34_LORA_DIO2)
US_Pwr: J7.3, JP16.2 (B), TP_US_Pwr1.1

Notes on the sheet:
Obs: Remove resistor SB21 do disconnect the on board LD2 (PA5)
*OBS: In STM32 Nucleo Board J2 and J4 pins are inverted But the alignment is correct
Swtich on/off External LED
LoRa Radio Module 2 - RFM69C
Arduino Headers
JP11 ON - JP12 OFF ==> VIN = 12V JP11 OFF - JP12 ON ==> BP_Pwr_3V3
* Indicates a PWM-capable pin
LoRa Radio Module 1 - LilyGo LORA32
STM32 RESET
Power Connector (Came from STM32 Nucleo Morpho Shield)

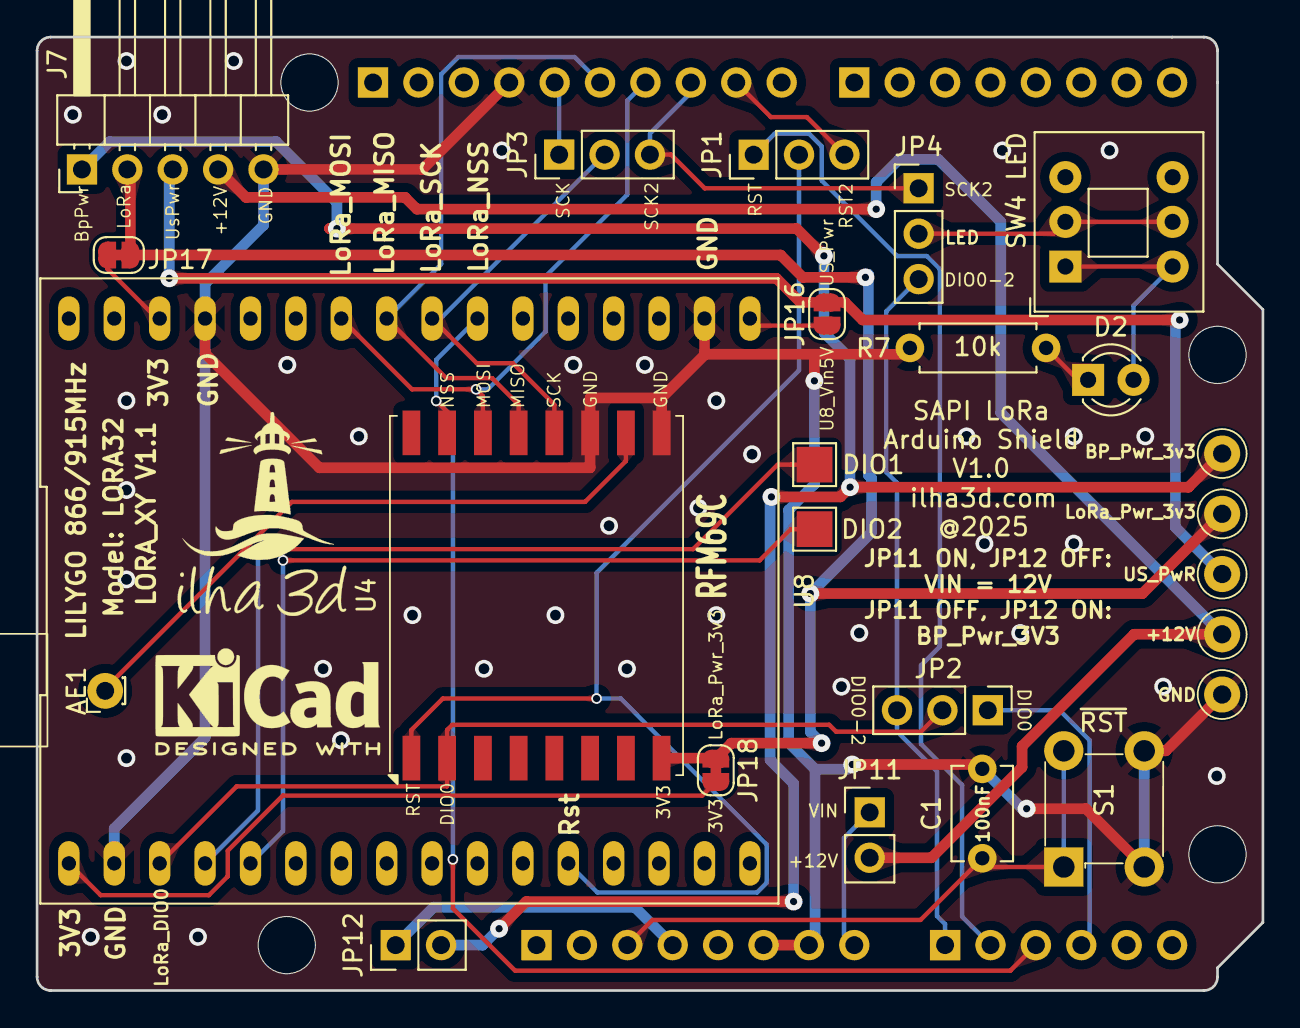
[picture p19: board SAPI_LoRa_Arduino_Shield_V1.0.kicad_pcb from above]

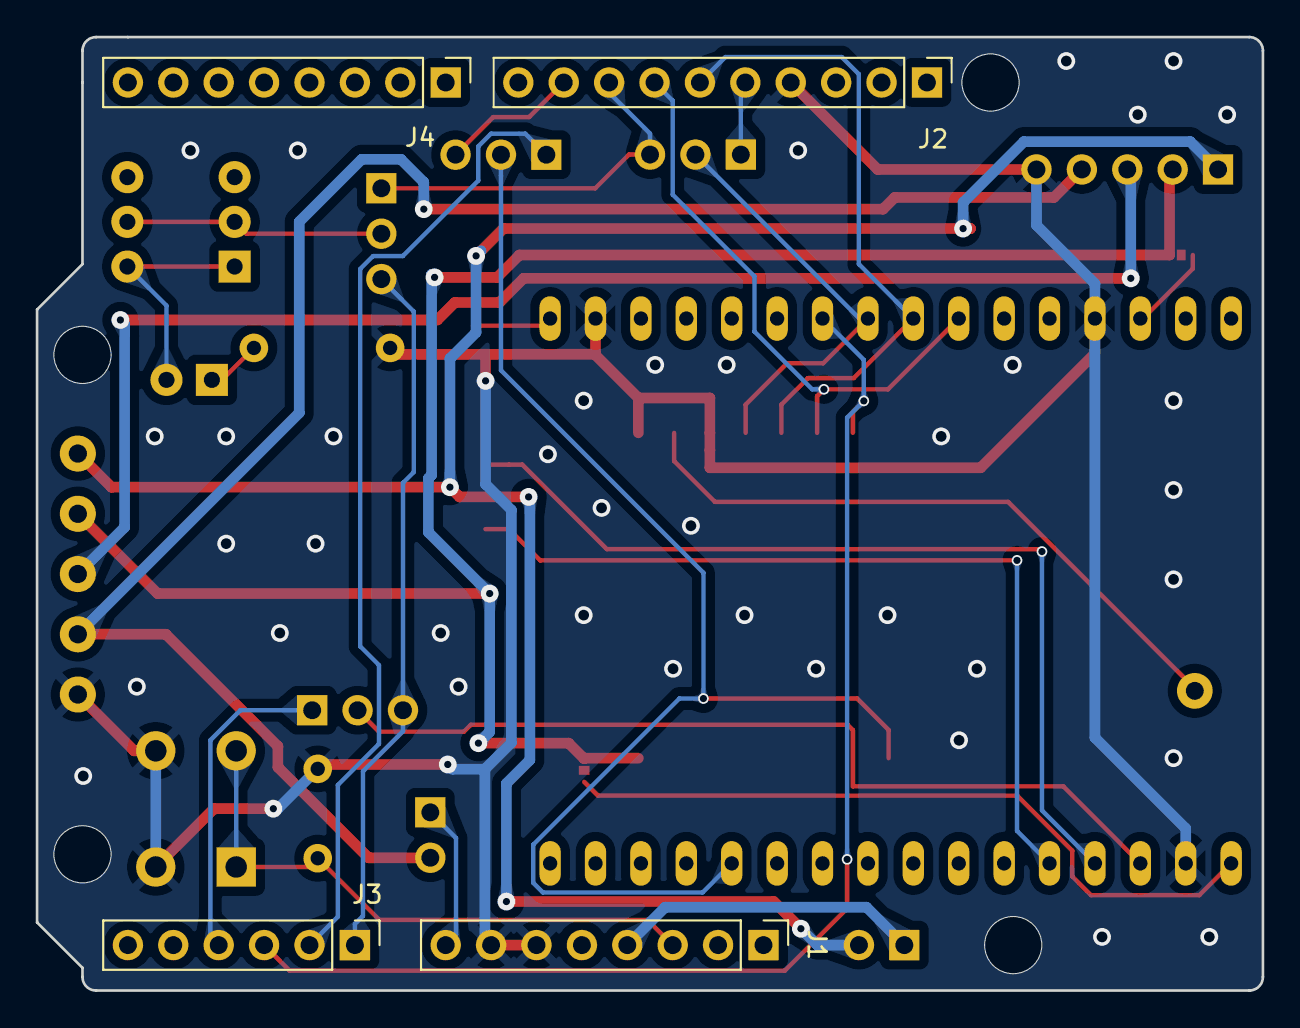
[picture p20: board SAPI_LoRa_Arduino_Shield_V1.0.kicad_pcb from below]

Board: 2 copper layers, 68.6 x 53.3 mm, 33 parts (4 on the bottom side), 29 nets.

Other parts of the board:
MH1, MH2, MH3, MH4: MountingHole_3.2mm

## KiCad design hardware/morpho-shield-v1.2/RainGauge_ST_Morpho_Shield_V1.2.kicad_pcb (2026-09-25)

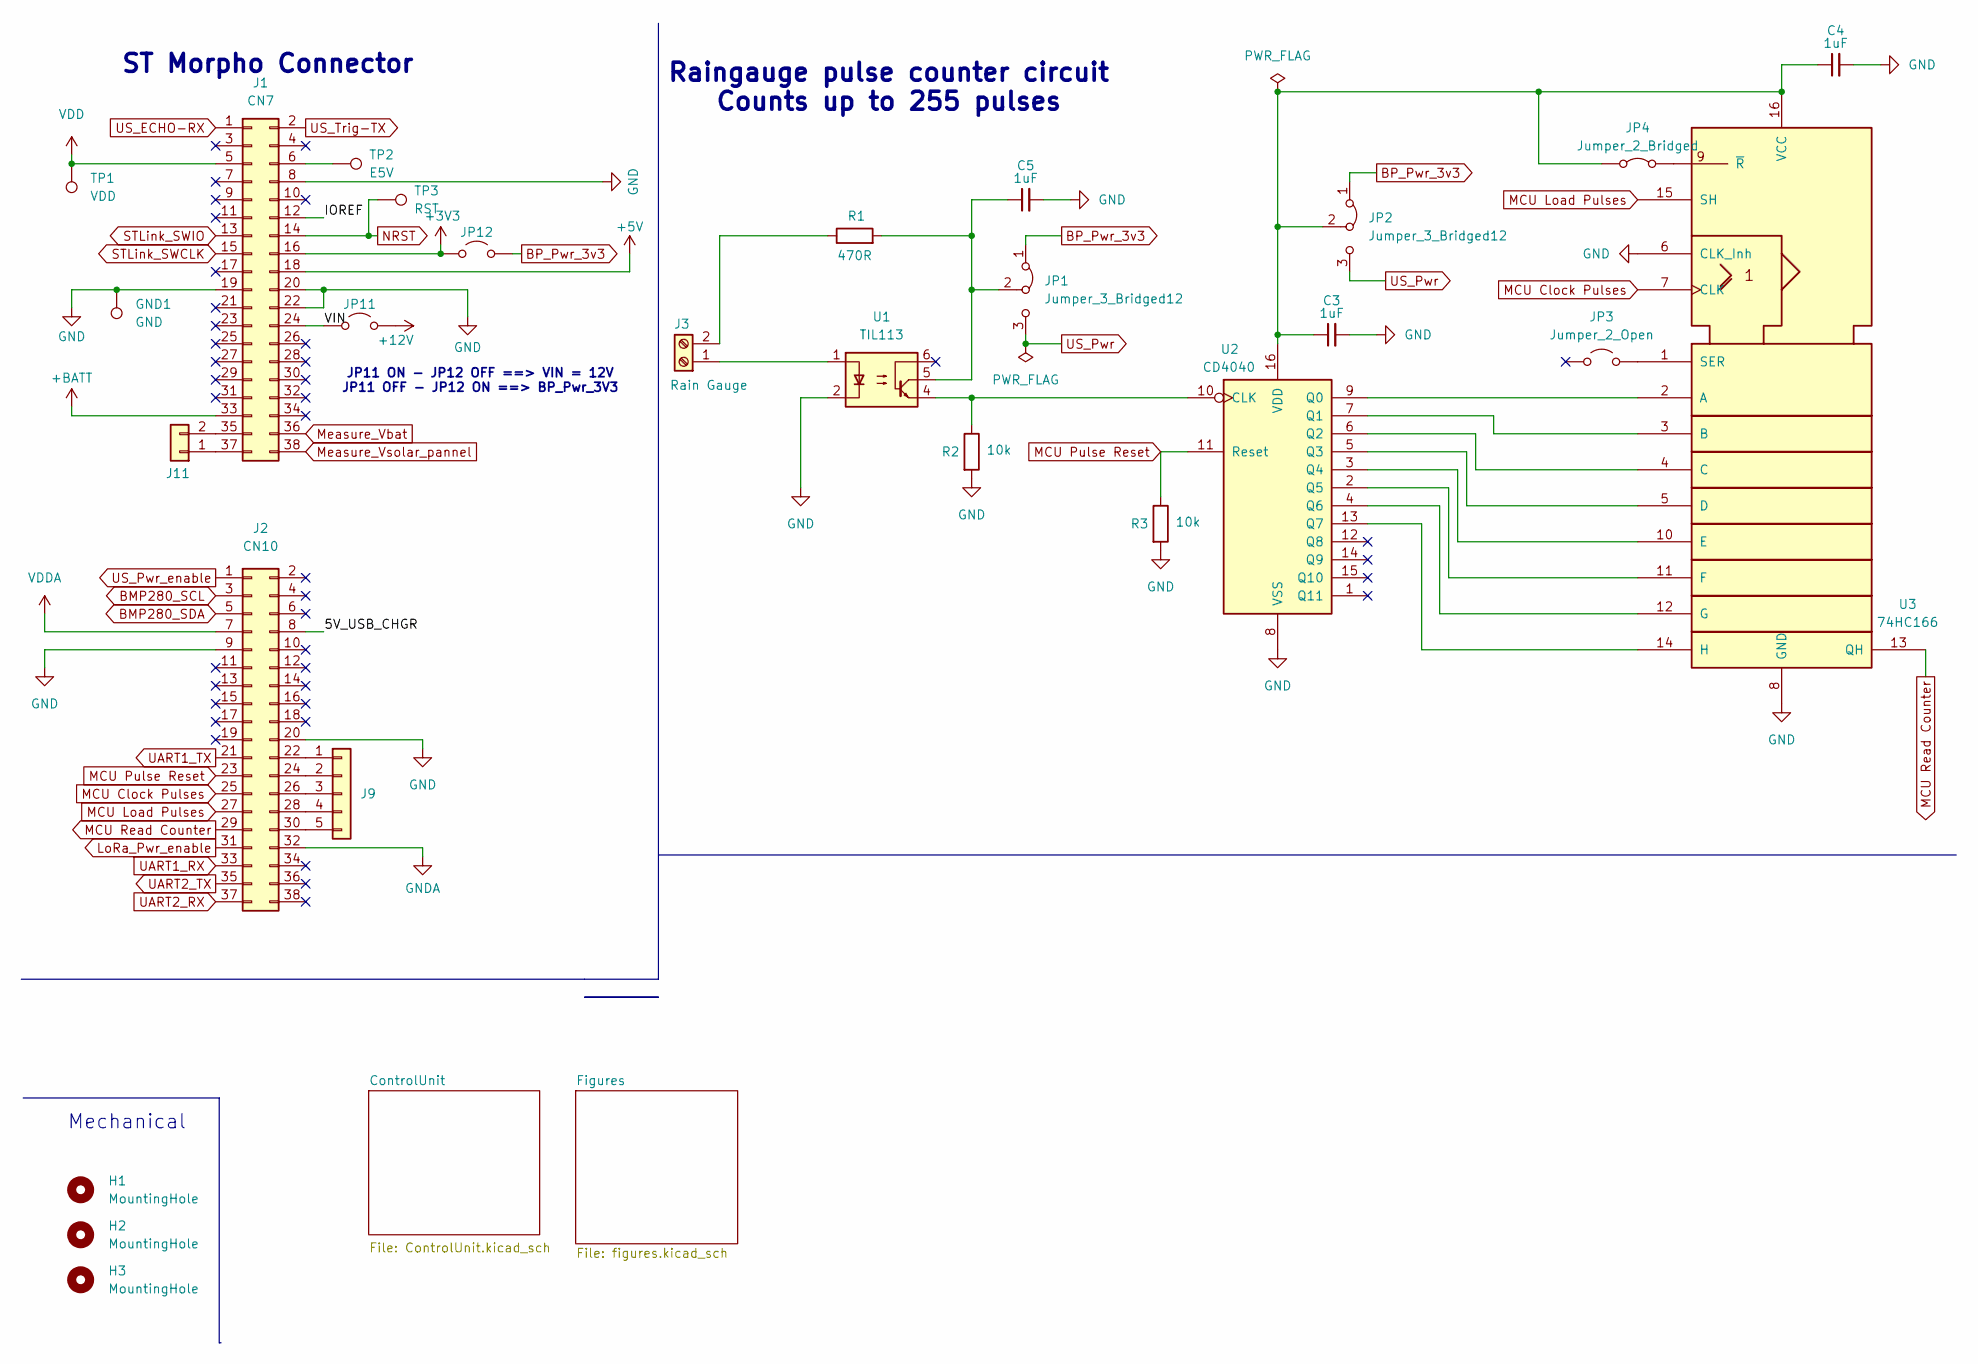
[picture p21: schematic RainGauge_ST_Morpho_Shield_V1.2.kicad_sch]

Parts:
C3, C4, C5: 1uF; C_Disc_D4.3mm_W1.9mm_P5.00mm
GND1: GND; PinHeader_1x01_P2.54mm_Vertical
H1, H2, H3: MountingHole; MountingHole_3.2mm_M3
J1: CN7; ilha3d_morphoPinSocket_2x19_P2.54mm_Vertical
J2: CN10; ilha3d_morphoPinSocket_2x19_P2.54mm_Vertical
J3: Rain Gauge; TerminalBlock_Phoenix_MKDS-1,5-2-5.08_1x02_P5.08mm_Horizont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
J9: Conn_01x05; PinHeader_1x05_P2.54mm_Vertical
J11: Conn_01x02; PinHeader_1x02_P2.54mm_Vertical
JP1, JP2: Jumper_3_Bridged12; Jumper_3Pins_SPDT_ilha3d
JP3, JP11, JP12: Jumper_2_Open; PinHeader_1x02_P2.54mm_Vertical
JP4: Jumper_2_Bridged; PinHeader_1x02_P2.54mm_Vertical
R1: 470R; R_Axial_DIN0207_L6.3mm_D2.5mm_P7.62mm_Horizontal
R2, R3: 10k; R_Axial_DIN0207_L6.3mm_D2.5mm_P7.62mm_Horizontal
TP1: VDD; PinHeader_1x01_P2.54mm_Vertical
TP2: E5V; PinHeader_1x01_P2.54mm_Vertical
TP3: RST; PinHeader_1x01_P2.54mm_Vertical
U1: TIL113; DIP-6_W7.62mm_Socket_LongPads
U2: CD4040; DIP-16_W7.62mm_Socket_LongPads
U3: 74HC166; DIP-16_W7.62mm_Socket_LongPads

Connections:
+3V3: J1.16, JP12.1 (A)
+5V: J1.18
+12V: JP11.2 (B); also elsewhere on the board
+BATT: J1.33
/5V_USB_CHGR: J2.8
/IOREF: J1.12
/VIN: J1.24, JP11.1 (A)
BMP280_SCL: J2.3; also elsewhere on the board
BMP280_SDA: J2.5; also elsewhere on the board
BP_Pwr_3v3: JP1.1 (A), JP2.1 (A), JP12.2 (B); also elsewhere on the board
GND: C3.2, C4.2, C5.2, GND1.1, J1.8, J1.19, J1.20, J1.22, J2.9, J2.20, R2.2, R3.2, U1.2, U2.8 (VSS), U3.6 (CLK_Inh), U3.8 (GND); also elsewhere on the board
GNDA: J2.32
LoRa_Pwr_enable: J2.31; also elsewhere on the board
MCU Clock Pulses: J2.25, U3.7 (CLK)
MCU Load Pulses: J2.27, U3.15 (SH)
MCU Pulse Reset: J2.23, R3.1, U2.11 (Reset)
MCU Read Counter: J2.29, U3.13 (QH)
Measure_Vbat: J1.36; also elsewhere on the board
Measure_Vsolar_pannel: J1.38; also elsewhere on the board
NRST: J1.14, TP3.1; also elsewhere on the board
unnamed: J1.6, TP2.1
unnamed: J1.35, J11.2
unnamed: J1.37, J11.1
unnamed: J2.22, J9.1
unnamed: J2.24, J9.2
unnamed: J2.26, J9.3
unnamed: J2.28, J9.4
unnamed: J2.30, J9.5
unnamed: J3.1, U1.1
unnamed: J3.2, R1.1
unnamed: C5.1, JP1.2 (C), R1.2, U1.5
unnamed: C3.1, C4.1, JP2.2 (C), JP4.1 (A), U2.16 (VDD), U3.16 (VCC)
unnamed: JP3.2 (B), U3.1 (SER)
unnamed: JP4.2 (B), U3.9 (~R)
unnamed: R2.1, U1.4, U2.10 (CLK)
unnamed: U2.9 (Q0), U3.2 (A)
unnamed: U2.7 (Q1), U3.3 (B)
unnamed: U2.6 (Q2), U3.4 (C)
unnamed: U2.5 (Q3), U3.5 (D)
unnamed: U2.3 (Q4), U3.10 (E)
unnamed: U2.2 (Q5), U3.11 (F)
unnamed: U2.4 (Q6), U3.12 (G)
unnamed: U2.13 (Q7), U3.14 (H)
STLink_SWCLK: J1.15; also elsewhere on the board
STLink_SWIO: J1.13; also elsewhere on the board
UART1_RX: J2.33
UART1_TX: J2.21
UART2_RX: J2.37; also elsewhere on the board
UART2_TX: J2.35; also elsewhere on the board
US_ECHO-RX: J1.1; also elsewhere on the board
US_Pwr: JP1.3 (B), JP2.3 (B); also elsewhere on the board
US_Pwr_enable: J2.1; also elsewhere on the board
US_Trig-TX: J1.2; also elsewhere on the board
VDD: J1.5, TP1.1
VDDA: J2.7

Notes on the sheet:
ST Morpho Connector
JP11 ON - JP12 OFF ==> VIN = 12V JP11 OFF - JP12 ON ==> BP_Pwr_3V3
Mechanical
Raingauge pulse counter circuit Counts up to 255 pulses

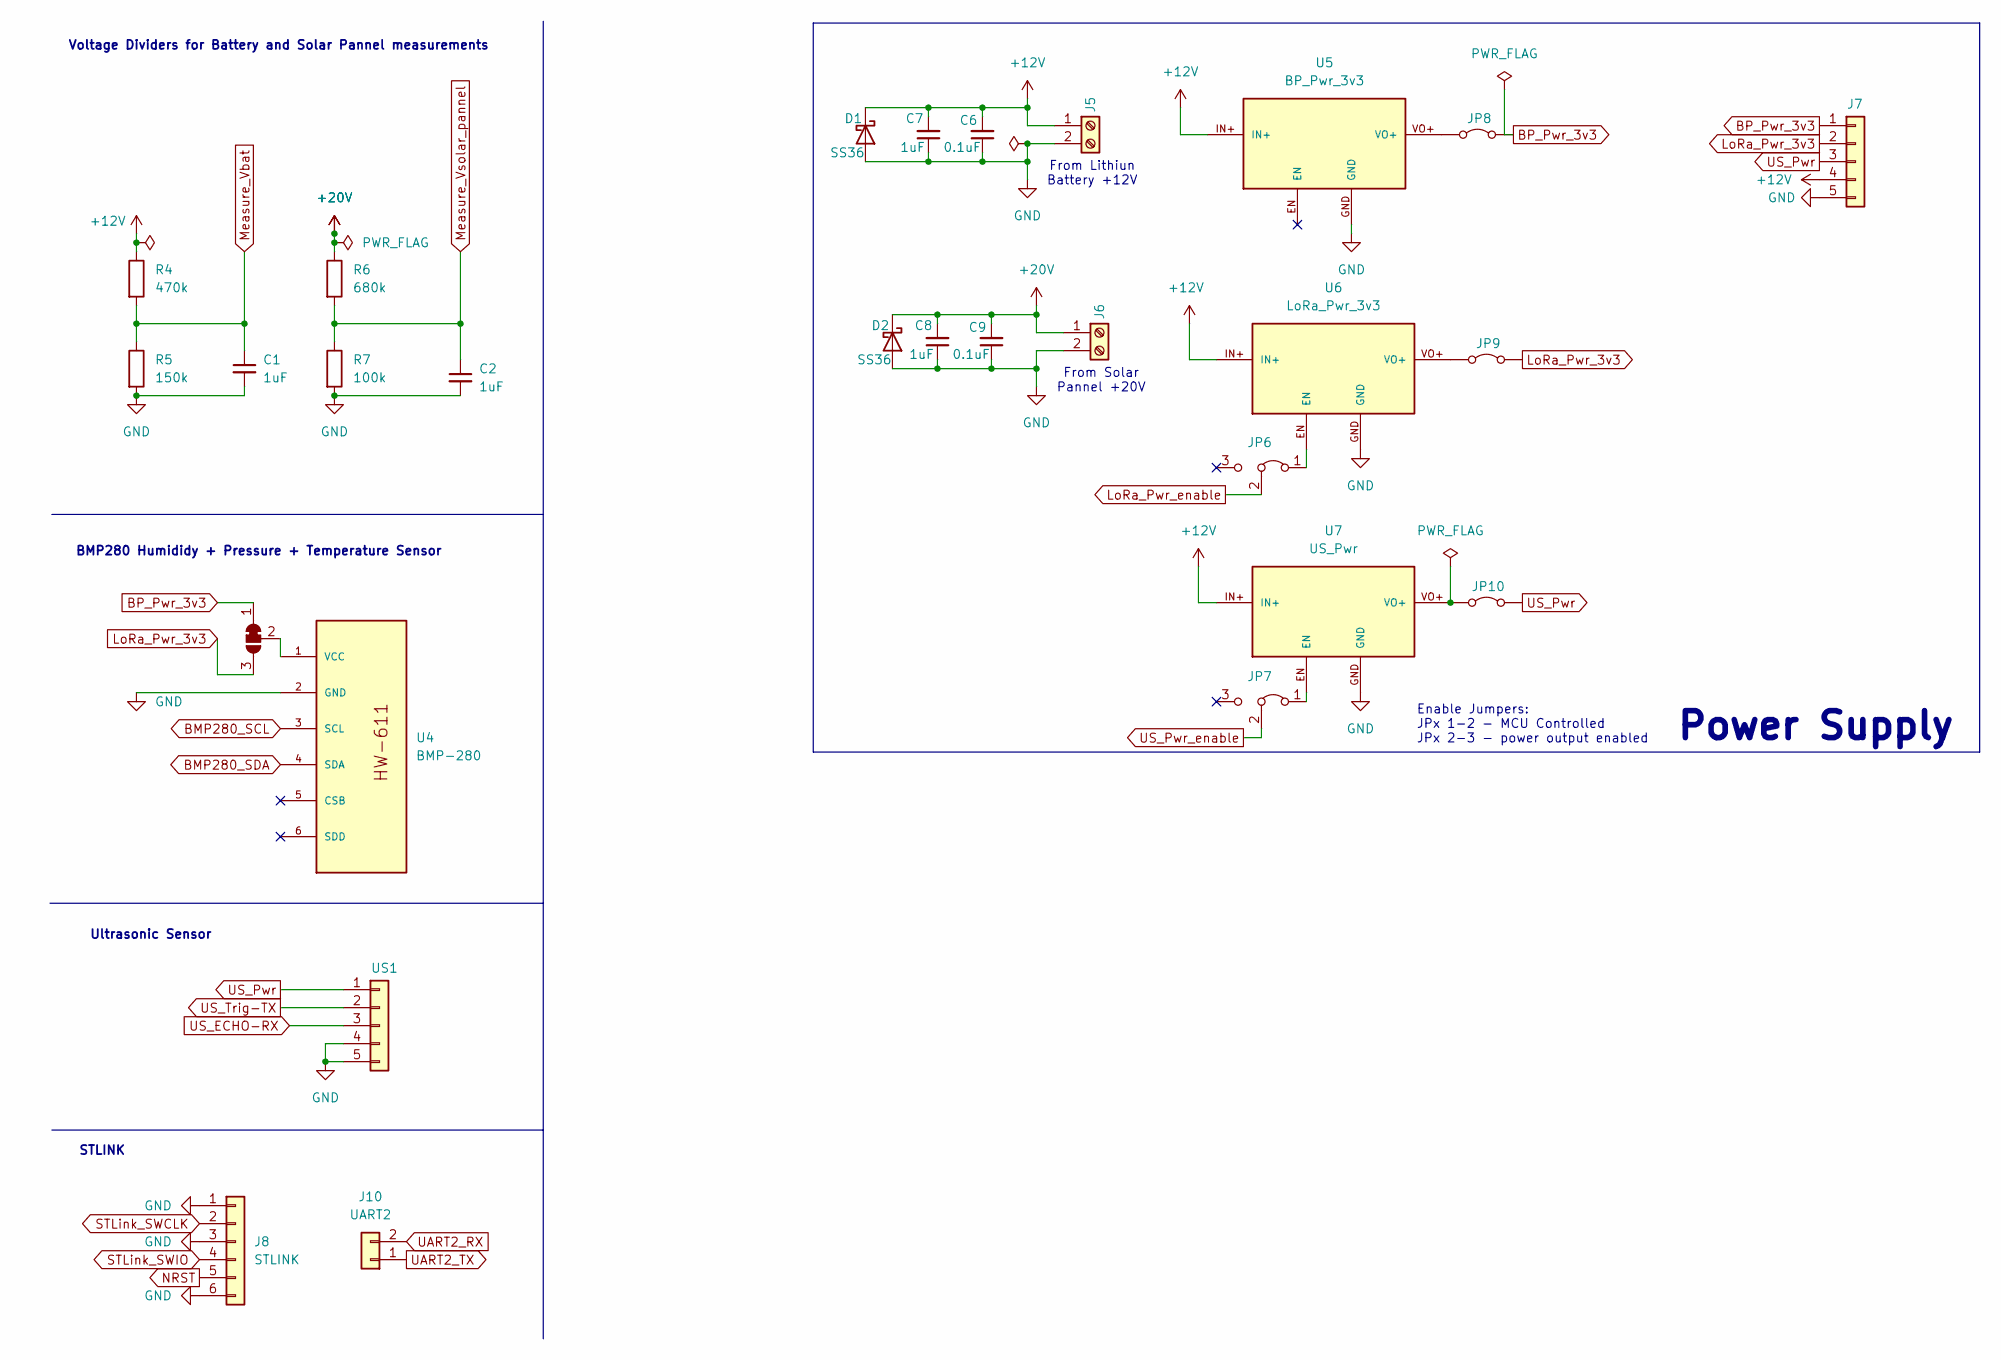
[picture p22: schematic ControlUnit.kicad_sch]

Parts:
C1, C2, C7, C8: 1uF; C_Disc_D4.3mm_W1.9mm_P5.00mm
C6, C9: 0.1uF; C_Disc_D4.3mm_W1.9mm_P5.00mm
D1, D2: SS36; D_SMA
J5: +12V; TerminalBlock_Phoenix_MKDS-1,5-2-5.08_1x02_P5.08mm_Horizont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
J6: +20V; TerminalBlock_Phoenix_MKDS-1,5-2-5.08_1x02_P5.08mm_Horizont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
J7: Power; PinHeader_1x05_P2.54mm_Horizontal
J8: STLINK; PinHeader_1x06_P2.54mm_Horizontal
J10: UART2; PinHeader_1x02_P2.54mm_Horizontal
JP5: SolderJumper_3_Bridged12; SolderJumper-3_P1.3mm_Bridged2Bar12_Pad1.0x1.5mm_NumberLabe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
JP6, JP7: PWR_EN; Jumper_3Pins_SPDT_ilha3d
JP8, JP9, JP10: Vout_ON; Ilha3d_Jumper_2Pins_closed
R4: 470k; R_Axial_DIN0207_L6.3mm_D2.5mm_P7.62mm_Horizontal
R5: 150k; R_Axial_DIN0207_L6.3mm_D2.5mm_P7.62mm_Horizontal
R6: 680k; R_Axial_DIN0207_L6.3mm_D2.5mm_P7.62mm_Horizontal
R7: 100k; R_Axial_DIN0207_L6.3mm_D2.5mm_P7.62mm_Horizontal
U4: BMP-280; PinHeader_1x06_P2.54mm_Horizontal
U5: BP_Pwr_3v3; HW-613
U6: LoRa_Pwr_3v3; HW-613
U7: US_Pwr; HW-613
US1: US; PinHeader_1x05_P2.54mm_Horizontal

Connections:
+12V: C6.2, C7.2, D1.1 (K), J5.1, J7.4, R4.1, U5.IN+, U6.IN+, U7.IN+; also elsewhere on the board
+20V: C8.2, C9.2, D2.1 (K), J6.1, R6.1
BMP280_SCL: U4.3 (SCL); also elsewhere on the board
BMP280_SDA: U4.4 (SDA); also elsewhere on the board
BP_Pwr_3v3: J7.1, JP5.1 (A), JP8.2 (B); also elsewhere on the board
GND: C1.2, C2.2, C6.1, C7.1, C8.1, C9.1, D1.2 (A), D2.2 (A), J5.2, J6.2, J7.5, J8.1, J8.3, J8.6, R5.2, R7.2, U4.2 (GND), U5.GND, U6.GND, U7.GND, US1.4, US1.5; also elsewhere on the board
LoRa_Pwr_3v3: J7.2, JP5.3 (B), JP9.2 (B)
LoRa_Pwr_enable: JP6.2 (C); also elsewhere on the board
Measure_Vbat: C1.1, R4.2, R5.1; also elsewhere on the board
Measure_Vsolar_pannel: C2.1, R6.2, R7.1; also elsewhere on the board
NRST: J8.5; also elsewhere on the board
unnamed: JP5.2 (C), U4.1 (VCC)
unnamed: JP6.1 (A), U6.EN
unnamed: JP7.1 (A), U7.EN
unnamed: JP8.1 (A), U5.VO+
unnamed: JP9.1 (A), U6.VO+
unnamed: JP10.1 (A), U7.VO+
STLink_SWCLK: J8.2; also elsewhere on the board
STLink_SWIO: J8.4; also elsewhere on the board
UART2_RX: J10.2; also elsewhere on the board
UART2_TX: J10.1; also elsewhere on the board
US_ECHO-RX: US1.3; also elsewhere on the board
US_Pwr: J7.3, JP10.2 (B), US1.1; also elsewhere on the board
US_Pwr_enable: JP7.2 (C); also elsewhere on the board
US_Trig-TX: US1.2; also elsewhere on the board

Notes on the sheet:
STLINK
From Lithiun Battery +12V
Enable Jumpers: JPx 1-2 - MCU Controlled JPx 2-3 - power output enabled
BMP280 Humididy + Pressure + Temperature Sensor
From Solar Pannel +20V
Voltage Dividers for Battery and Solar Pannel measurements
Power Supply
Ultrasonic Sensor

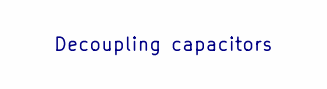
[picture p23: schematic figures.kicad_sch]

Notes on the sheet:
Decoupling capacitors

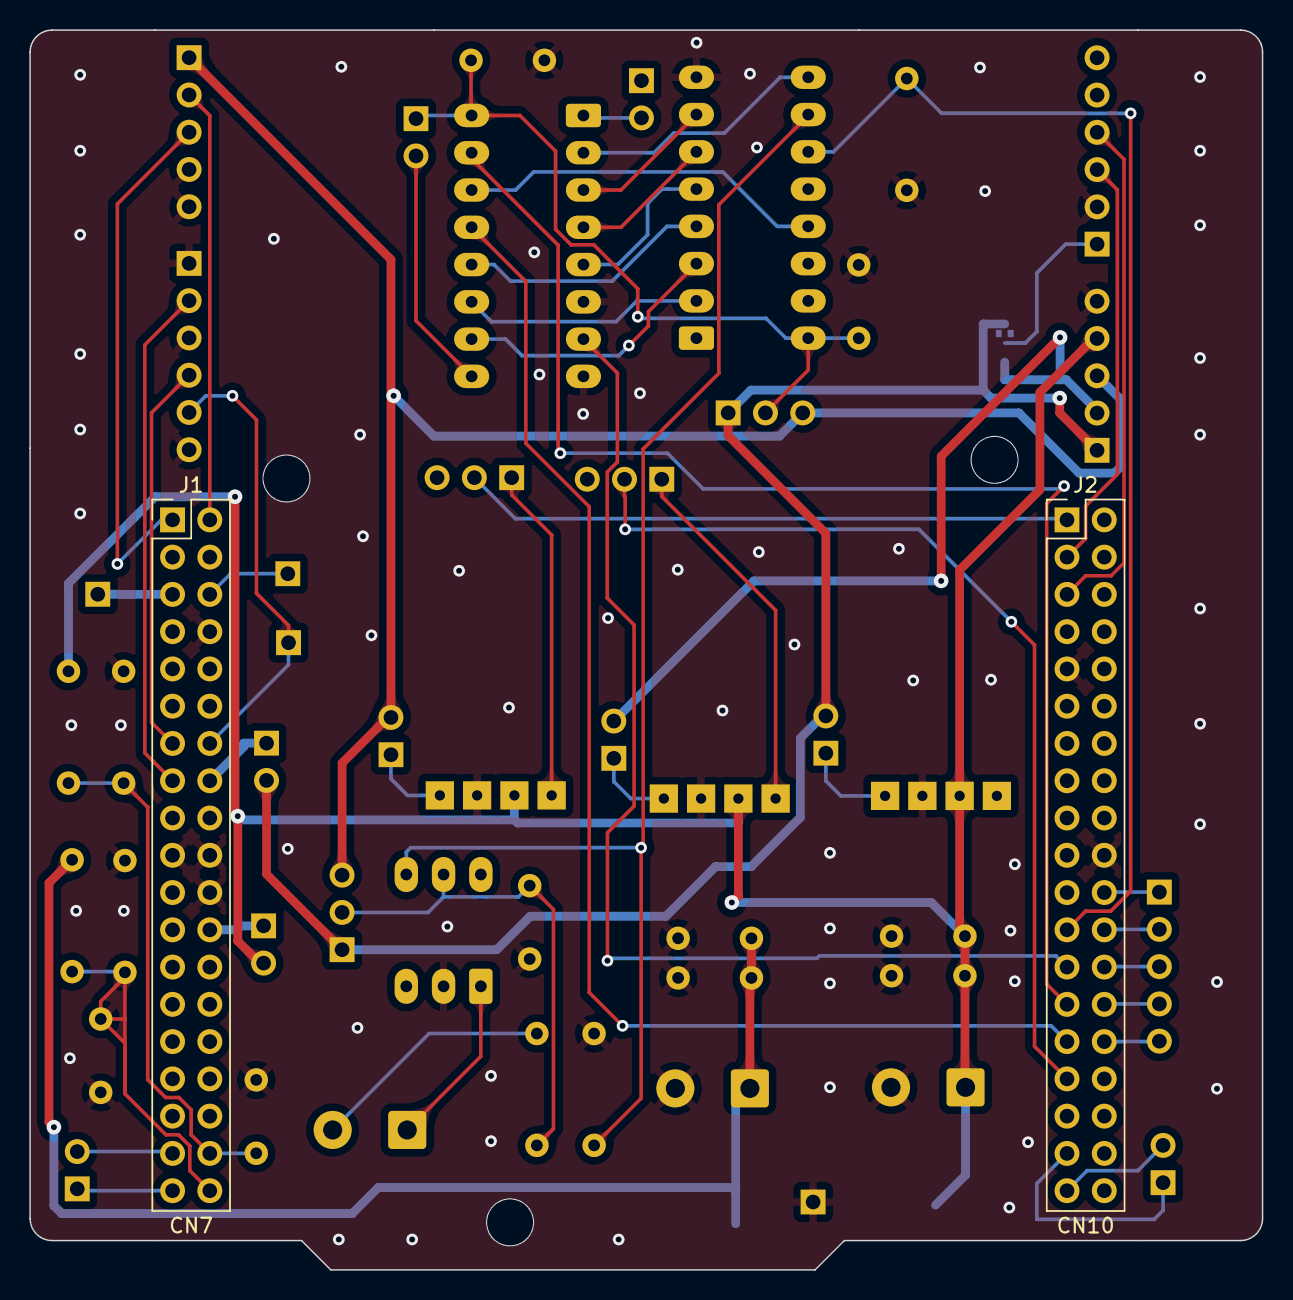
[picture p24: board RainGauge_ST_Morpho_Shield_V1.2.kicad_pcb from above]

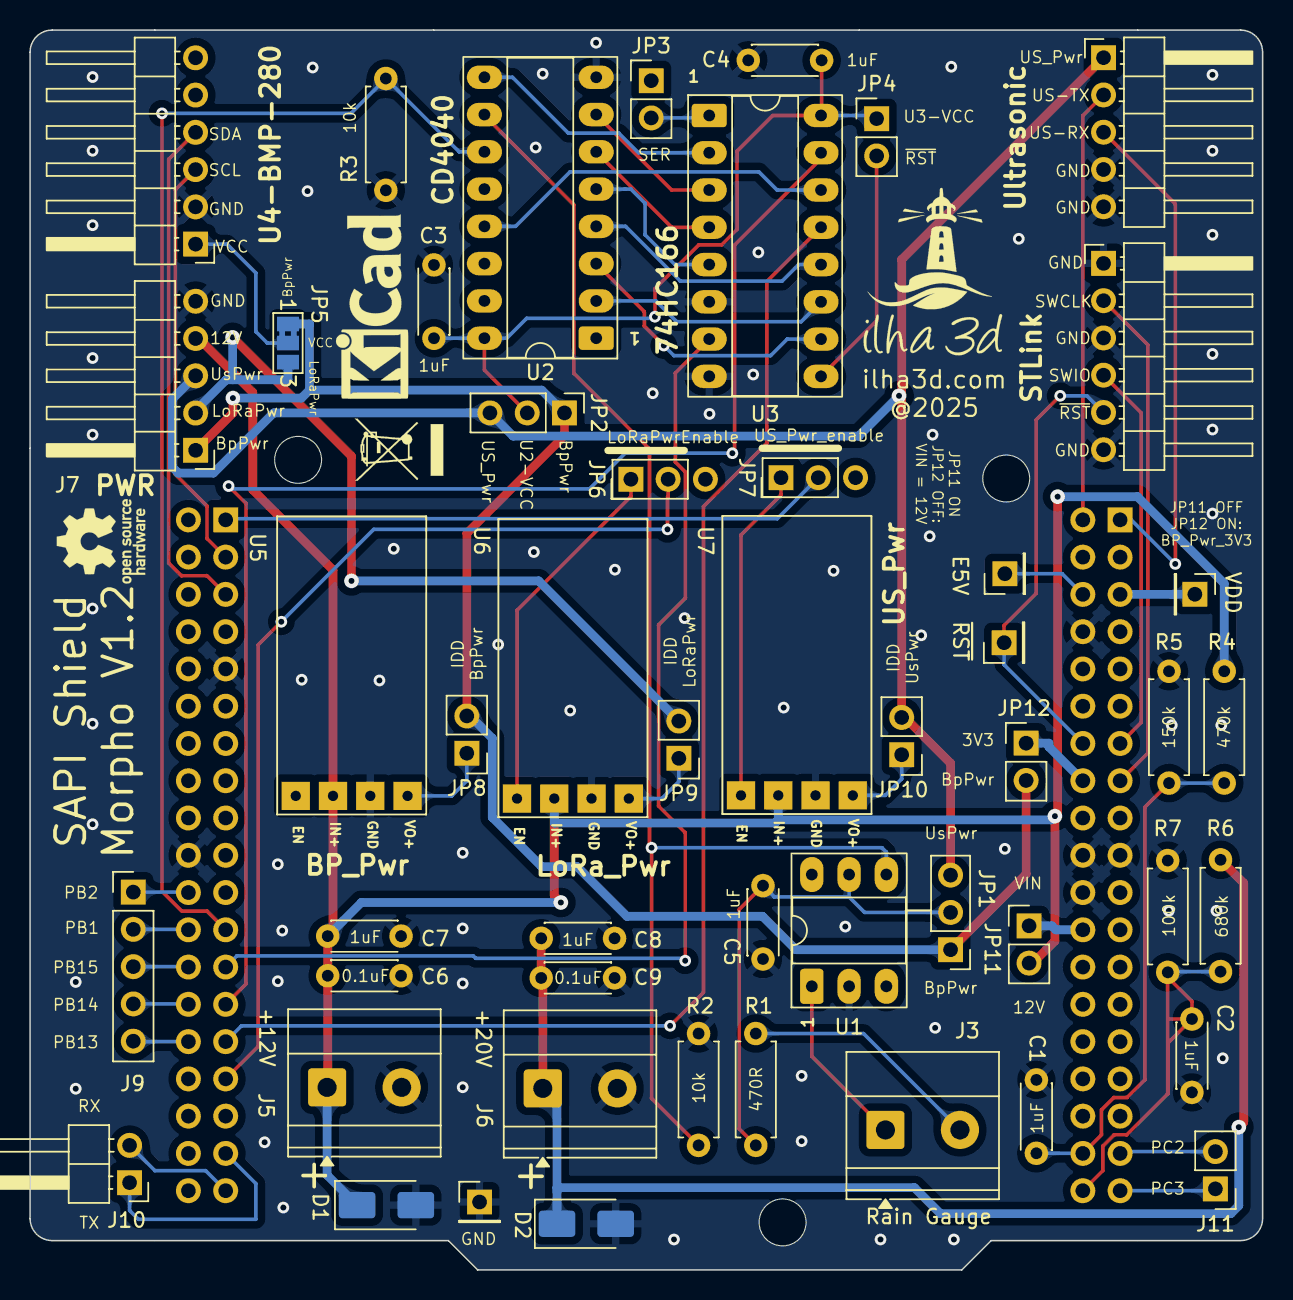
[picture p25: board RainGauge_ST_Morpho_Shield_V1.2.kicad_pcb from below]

Board: 2 copper layers, 84.0 x 84.5 mm, 59 parts (57 on the bottom side), 55 nets.

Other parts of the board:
Logo1: KiCad-Logo_5mm_SilkScreen
Logo2: WEEE-Logo_4.2x6mm_SilkScreen
Logo3: LOGO; logo ilha3d - 500x500 KiCad cheio_16.9mm_positive
Logo4: OSHW-Logo_5.7x6mm_SilkScreen

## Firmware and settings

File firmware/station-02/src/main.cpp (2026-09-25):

/* Blue_Pill_Lora_Transmitter_with_RFM95_BPLTwR_23.09.2021-01
 * Código do sensor que está ativo na ponte pequena
 *
 * Alexandre Nuernbegr - alexandreberg@gmail.com
 *
 * Code available on: https://github.com/alexandreberg/SAPM_Sensor_BluePill
 *
 * RFM95 LoRa Connection - STM32 Bluepill
 *    VCC - 3.3V
 *    GND - GND
 *    LoRa_SCK - LoRa_SCK (PA5)
 *    LoRa_MISO - LoRa_MISO (PA6)
 *    LoRa_MOSI - LoRa_MOSI (PA7)
 *    NSS - (PA4)
 *    RESET - (PA0)
 *    LoRa_DIO0 - (PA1)
 *
 * BackupRegisters:
 * See https://community.st.com/t5/stm32-mcus/how-to-use-the-stm32-s-backup-registers/ta-p/49892
 *
 * Backup registers can be written/read and protected and have the option of being preserved in VBAT mode when the VDD domain is powered off.
 * The BackUp Registers are part of the RTC peripheral so we will need to enable the RTC to be able to access them.
 * The STM32 Blue Pill, which typically uses the STM32F103C8T6 microcontroller, has 10 backup registers.
 * Each register is 16 bits wide, providing a total of 20 bytes of data that can be stored in the backup domain.
 *
 * (!) To be able to preserve the backup registers through a power cycle, VBAT must remain powered when VDD is removed, this is called the VBAT mode.
 *
 * 23.11.2024 - Changing the code to read and hibernate for 1 minute between ultrasound readings.
 *             - 1min on and 1min off, adjust to not stay on for so long and turn off as soon as it transmits
 * 24.11.2024 - changing the readUltrasonic() function to work with the median
 *
 * 24.12.2024 - Cleaning and organizing the file
 *
 * TODO:
 * reactivate hibernation and make it sleep for 1min
 *
 *
BackupRegister Values:
Register - Value - Description
BR0 - último estado (logState)
BR1  →
BR2  → != 0 - indicates that  STM32 should to go into deepsleep
BR3  → != 0 -//indicates that  have to go into deepsleep
BR4  → contador de boots
BR5 e BR6 → timestamp (parte baixa/alta)
BR7 - FREE
BR8 - FREE
BR9 - FREE

Flag to enter in deep sleep mode:
goToSleep_flag = 0; i boot flag
goToSleep_flag = 1; //hibernation flag normal deepsleep ?????
goToSleep_flag = 2; //hibernation flag 1min ?????

Last state before reset/sleep:
goToSleep = 10 // vai dormir
loop = 20 // entrou no loop
onReceive = 30
sendReadings = 40

-06.08.2025 OK  - Cleaning and organizing the file
            OK  - Identing the file
            OK - Increasing RSSI signal for LoRa power to 20dBm
            - Correcting problem that sends lora message before ending US routines.
-27.08.2025 - Trying to correct the problem that freezes the return of the sensor after the hibernation leaving the holes in the graphic.
 * Debug-enhanced version of BluePill LoRa Transmitter
 * - Logs last execution state into BackupRegisters
 * - Handles new LoRa timestamp message format: "TS:<timestamp>"
 * - Prints backup registers at startup
 * 
BR1 / BR2 → timestamp (parte baixa/alta)

Sobre a lib low power:
https://github.com/stm32duino/STM32LowPower
void shutdown(uint32_t ms): enter in shutdown mode param ms (optional): number of milliseconds before to exit the mode. The RTC is used in alarm mode to wakeup the board in ms milliseconds.
Important:
RTC used as Wakeup source requires to have LSE or LSI as clock source. If one of them is used nothing is changed else it will configure it to use LSI clock source. One exception exists when SHUTDOWN_MODE is requested and PWR_CR1_LPMS is defined, in that case LSE is required. So, if the board does not have LSE, it will fail.
Eu uso o: rtc.setClockSource(STM32RTC::LSE_CLOCK); está correto.
The board will restart when exit shutdown mode.

Hardware state
shutdown mode: high wake-up latency (possible hundereds of ms or second timeframe), voltage supplies are cut except always-on domain, memory content are lost and system basically reboots.

- 16/Dec/2025 - Migrating the sketch from STM32 Bluepill to STM32 Nucleo F103RB
Testing radio with no US:
Station_02:
Sending packet N°: 0
LoRaMessage: Station_02/9999&9999

Gateway:
[2025-12-17 08:17:20] 7461- Mensagem Recebida de Sensor: Station_02 | Altura Lida: 9999cm | Size: 20 RSSI: -51 | SNR: 9

- 17/Dec/2025:
 - adding BME280 (Tested OK)
 - adding ADC for measure Vbat and Vpanel
 - adding RainGauge
- 24/Dec/2025:
 - migrating LoRa for struct to deal with all the variables

 *
 * SPDX-License-Identifier: AGPL-3.0-or-later
 * Copyright (C) 2024–2026 Alexandre Nuernberg <alexandreberg@gmail.com>
 *
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
 * You should have received a copy of the GNU Affero General Public License
 * along with this program. If not, see <https://www.gnu.org/licenses/>.
*/

/*********************************************** Sensor Description ***********************************************/
#define sensor_id "Station_02"      // <<=== Sensor identification  ==>> CHANGE HERE!!
#define sensor_location "Front_House" // <<=== Sensor location        ==>> CHANGE HERE!!

/*********************************************** Macro Definitions ***********************************************/
// Enable (uncommenting) or disable (commenting out) services and periferals
#define enableSerialLog  // enable Serial debug on console
#define enableWatchDog   // enable watchdog for deepsleep
#define enableUltrasonic // enable Ultrasonic Sensor
#define enableRTCstm32   // using STM32 internal RTC Clock
#define enableLoRa // enable LoRa communication
#define enableDebug // Enable verbosity in debugging log
#define enableBME280 // Enable BME280 temperature and pressure sensor
#define enableADC // Enable ADC reading for solar pannel and battery voltages
#define enableRainGauge // Enable the Rain Gauge

/*********************************************** Library Definitions ***********************************************/
#include <Arduino.h>
#include <stdlib.h>
#include <STM32LowPower.h> //Deep Sleep for STM32
#include <SPI.h>
#include <time.h>

#ifdef enableRTCstm32
#include <STM32RTC.h>
#endif

#ifdef enableWatchDog
#include <IWatchdog.h>
#endif

#ifdef enableUltrasonic
#include <NewPing.h>
#endif

#ifdef enableLoRa
#include <LoRa.h> // sandeepmistry/LoRa library
#endif

#ifdef enableBME280
#include "bme280_sensor.h"
#endif

#ifdef enableADC
#include "adc.h"
#endif

#ifdef enableRainGauge
#include "raingauge.h"
#endif

/*********************************************** Global Variables ***********************************************/
String version = "System Version: SAPI_Station02_Nucleo_F103RB_2026010201 - Rain Gauge"; // ==> CHANGE HERE! <==

#define hibernation_time 880 // Hibernation time for deep sleep in seconds (15 min - 20 sec)

#ifdef enableWatchDog
#define ledPin PA0 // Choose LoRa_SCK2 (PB6) or LoRa_DIO_2 (PA0) - have to change jump (JP4) in the SAPI LoRA Arduino Shield  V1.0
#endif

#ifdef enableRTCstm32 // Working
boolean onReceive_flag = 0;
/* Get the rtc object */
STM32RTC &rtc = STM32RTC::getInstance();
byte startUpMinute = 0;
/* Change these values to set the current initial time */
byte seconds = 0;
byte minutes = 0;
byte hours = 0;

/* Change these values to set the current initial date */
byte weekDay = 0;
byte day = 0;
byte month = 0;
byte year = 0;

#endif // enableRTCstm32

#ifdef enableUltrasonic
const unsigned int triggerPin = PC11;
const unsigned int echoPin = PC10;
// long lastEchoDistance = 0;             // We want to keep these values after reset
unsigned long pulseLength = 0;
int32_t readingDistance = 0; // Measured distance in centimeters
// unsigned long maxReadingNumber = 0;    // Number of ultrasonic readings to do the calculation of mean and average
bool distance_reading_done = false;
#endif // enableUltrasonic

#ifdef enableBME280
float bme_temperature = 0.0;
float bme_pressure = 0.0;
bool bme_reading_done = false;
#endif // enableBME280

int goToSleep_flag = 0; // Flag to enter in deep sleep mode

#ifdef enableLoRa
// ================== LoRa Configuration Pins ==================
#define LoRa_SCK   PA5
#define LoRa_MISO  PA6
#define LoRa_MOSI  PA7
#define LoRa_NSS   PA4  // LoRa radio chip select
#define LoRa_RST   PA1  // LoRa radio reset
#define LoRa_DIO0  PB0  // Must be a hardware interrupt pin
#define LoRa_Pwr_enable PB3 // Enable LoRa power supply in the shield   

// Define LoRa Communication Band:
#define BAND 915E6 /*  915E6 for Brazil (902-928 MHz) \
                       433E6 for Asia                 \
                       866E6 for Europe               \
                       915E6 for North America */

int lora_startup_counter = 0; // Counter to check if LoRa chip started communication propperly
// long readingID = 0;           // Sending packet N°

// String LoRaMessage = ""; // String to store the LoRa Message that should be sent


#endif                   // enableLoRa

// ================== Data Struct ==================
struct __attribute__((packed)) SensorData {
  uint32_t idStation = 2; // Change for the station id number in the DB
  uint32_t reading_number; // increment each transmission
  uint32_t timestamp;   // createdAt
  int32_t level;        // ultrasonic measurement
  float temperature;    // BME280 temperature
  float pressure;       // BME280 pressure
  int32_t humidity;     // BME280 humidity
  int16_t precipitation_pulses; // Rain Gauge pulses
  float surface_temperature; // always 0
  int32_t Vbat;         // in milivolts
  int32_t Vpanel;       // in milivolts
  int32_t rssi;         // actual LoRa RSSI
  float snr;          // Lora SNR
  int32_t sigWiFi;      // always 0
  int32_t sigCel;       // always 0
};
SensorData sensorData;
// uint32_t reading_counter = 0;

/* Enable HardwareSerial when you dettach the STLINK from the nucleo board for saving battery
 Connect STLIN externally for proggramming and you can use FTDI in the pins:
 FTDI connection:
FTDI	|	CN10 Morpho	|	STM32 Pin	|	Function
RX		|	Pin 21		|	PA9			|	USART1_TX
TX		|	Pin 33		|	PA10		|	USART1_RX
GND		|	Pin 20		|	GND			|	GND
This option just should be used if the STLINK is detached and if the jumping bridges SB62 and SB63 are open.
If you weld these two jumpers so you can use the ordinary USART2 pins available in the SAPI Morpho Shield,
connect J10 (TX and RX USART2) to the separated STLINK CN3 and there is no need to uncomment the two following lines. */
// HardwareSerial Serial1(PA10, PA9);  // RX, TX
// #define Serial Serial1 // Avoid to change all the code whan STlink is disconnected from nucleo board.

/*********************************************** Function Prototypes ***********************************************/
void sketchSetup();
void readUltrasonic();
float calculateMedian(int *array, int arraySize);
int compareReadings(const void *a, const void *b);
void logState(uint16_t code);

#ifdef enableRTCstm32
void setupRTC();
void setTime();
void readTime();
#endif // enableRTCstm32

#ifdef enableUltrasonic
void ultrasonic_setup();
void readUltrasonic();
float calculateMedian(int *array, int arraySize);
int compareReadings(const void *a, const void *b);
#endif // enableUltrasonic

#ifdef enableLoRa
void LoRa_rxMode();
void LoRa_txMode();
void onReceive(int packetSize);
void LoRa_sendMessage(String message);
void onTxDone();
boolean runEvery(unsigned long interval);
void checkonReceive();
boolean runClockEvery(unsigned long interval);
void start_LoRa();
void sendSensorData();
#endif // enableLoRa

void goToSleep();
void updateSensorDataADC(const adc_readings_t *readings);
void updateSensorDataRain(const raingauge_readings_t *readings);
void updateSensorDataBME(float temp, float press);
void fillSensorData();
void printSensorData(const SensorData &d);

/*********************************************** End Function Prototypes *******************************************/
// TODO: Need to be better documented and clarified!!!!
void setup()
{
  sketchSetup();           // Setup of the Serial log and initial serial setup
  pinMode(ledPin, OUTPUT); // Initialize digital ledPin (LED on SAPI Arduino Shield) as an output.

  // Blink pattern at startup
  for (int i = 0; i < 10; i++)
  {
    digitalWrite(ledPin, HIGH);
    delay(150);
    digitalWrite(ledPin, LOW);
    delay(150);
  }

  // Contador de reinicializações no BackupRegister 4
  /* Cada vez que o setup() roda (seja por reset, watchdog ou wake-up), ele incrementa o valor armazenado no BR4.*/
  enableBackupDomain();
  uint16_t bootCounter = getBackupRegister(4);
  bootCounter++;
  setBackupRegister(4, bootCounter);
  disableBackupDomain();
  Serial.print("Boot counter (BR4): ");
  Serial.println(bootCounter);

#ifdef enableWatchDog
  enableBackupDomain(); // Function of .platformio\packages\framework-arduinoststm32\cores\arduino\stm32\backup.h

  if (getBackupRegister(2) != 0)
  { // indicates that  STM32 should to go into deepsleep
    Serial.println("Sistema reinicializado pelo WatchDog ... === Irá entrar em hibernação ... === BR2 = " + String(getBackupRegister(2)));
    setBackupRegister(2, 0);
    delay(100);
    setupRTC();
    LowPower.begin();
    goToSleep_flag = 2; // hibernation flag 1min
    goToSleep();
  }

  disableBackupDomain();
  IWatchdog.begin(10000000); // Init the watchdog timer with 10 seconds timeout
#endif

  // TODO: Enable the LoRa power supply HW-613 module
  // pinMode(LoRa_Pwr_enable, OUTPUT);
  // digitalWrite(LoRa_Pwr_enable, HIGH);

  delay(50); // delay for active the power supply

  Serial.println("Tentando inicializar o RTC com LSE...");
  setupRTC();
  delay(50);

#ifdef enableBME280
  Serial.println("Initializing BME280 sensor...");

  if (bme280_init())
  {
    Serial.println("BME280 ready!");
  }
  else
  {
    Serial.println("Warning: BME280 initialization failed - continuing without sensor");
  }
  delay(50);
#endif

#ifdef enableADC
  Serial.println("Reading Voltages from Battery and Solar Panel ...");
  adc_init();
#endif

#ifdef enableRainGauge
  Serial.println("Initializing Rain Gauge pins ...");
  raingauge_init();
#endif

  Serial.println("LowPower.begin()");
  LowPower.begin();
  goToSleep();

  // Serial.println("ultrasonic_setup()");
  // ultrasonic_setup();

  Serial.println("start_LoRa()"); //ok
  start_LoRa();
}

/*********************************************** loop () ***********************************************/
void loop()
{
  logState(20); // entrou no loop

#ifdef enableBME280
  // readBME280(); // Read BME280 sensor data
  float bmeTemp, bmePress;
  if (bme280_read(&bmeTemp, &bmePress))
  {
    bme280_printReadings(); //OK
    updateSensorDataBME(bmeTemp, bmePress);
  }
#endif

#ifdef enableRainGauge
  raingauge_readings_t rain;

  if (raingauge_getReadings(&rain))
  {
    updateSensorDataRain(&rain);
    raingauge_printReadings(&rain);
    raingauge_resetCounter();
  }

#endif

  // readUltrasonic();

#ifdef enableADC
  adc_readings_t adcReadings;

  if (adc_read(&adcReadings))
  {
    adc_printReadings(&adcReadings);
    updateSensorDataADC(&adcReadings);
  }
#endif

    fillSensorData();
    sendSensorData(); // New Lora function

#ifdef enableWatchDog
    IWatchdog.reload();
#endif

    enableBackupDomain();
    setBackupRegister(2, 10);
    disableBackupDomain();

    goToSleep();
    delay(15 * 1000); // DEBUG
  }

  /*********************************************** End loop () ***********************************************/

  /*********************************************** Function Definitions ***********************************************/
  //////////////////////////////////////////////////// sketchSetup ////////////////////////////////////////////////////
  // Shows system infomation and configures serial interface
  void sketchSetup()
  {
    Serial.begin(115200);
    // Serial1.begin(115200); 
    delay(200);

    Serial.println("\nStarting Sensor: " + String(sensor_id) + " on " + String(sensor_location));
    // Serial1.println("\nStarting Sensor: " + String(sensor_id) + " on " + String(sensor_location)); // ok it worked
    Serial.println("\nIlha 3d");
    Serial.println("\nwww.ilha3d.com");
    Serial.println("\n");
    Serial.println(String(version));
    Serial.println("");

    Serial.println("=== Boot STM32 Sensor Node ===");
    Serial.print("Last state before reset/sleep: ");
    Serial.println(getBackupRegister(0));
    Serial.print("BackupReg1 (TS low): ");
    Serial.println(getBackupRegister(5));
    Serial.print("BackupReg2 (TS high): ");
    Serial.println(getBackupRegister(6));

#ifdef enableDebug
  Serial.println("Last values of all Backup Registers:");
  Serial.println("BR0 = " + String(getBackupRegister(0)));
  Serial.println("BR1 = " + String(getBackupRegister(1)));
  Serial.println("BR2 = " + String(getBackupRegister(2)));
  Serial.println("BR3 = " + String(getBackupRegister(3)));
  Serial.println("BR4 = " + String(getBackupRegister(4)));
  Serial.println("BR5 = " + String(getBackupRegister(5)));
  Serial.println("BR6 = " + String(getBackupRegister(6)));
  Serial.println("BR7 = " + String(getBackupRegister(7)));
  Serial.println("BR8 = " + String(getBackupRegister(8)));
  Serial.println("BR9 = " + String(getBackupRegister(9)));
#endif
}

#ifdef enableRTCstm32
void setupRTC()
{
  // Select RTC clock source: LSI_CLOCK, LSE_CLOCK or HSE_CLOCK.
  // By default the LSI is selected as source.
  // rtc.setClockSource(STM32RTC::LSI_CLOCK); //3V3 ligado com diodo no VBAT
  rtc.setClockSource(STM32RTC::LSE_CLOCK); // 3V3 wired with a diode on VBAT
  rtc.begin();                             // initialize RTC 24H format
}

void setTime()
{
  // Set the time
  rtc.setHours(hours);
  rtc.setMinutes(minutes);
  rtc.setSeconds(seconds);

  // Set the date
  rtc.setWeekDay(weekDay);
  rtc.setDay(day);
  rtc.setMonth(month);
  rtc.setYear(year);
}

void readTime()
{
  // Print date...
  Serial.println("Data e hora armazenada no RTC Local");
  Serial.printf("%02d/%02d/%02d ", rtc.getDay(), rtc.getMonth(), rtc.getYear());

  // ...and time
  Serial.printf("%02d:%02d:%02d.%03d\n", rtc.getHours(), rtc.getMinutes(), rtc.getSeconds(), rtc.getSubSeconds());
}
#endif // enableRTCstm32

#ifdef enableUltrasonic
// Ultrasonic Distance Sensor setup
void ultrasonic_setup()
{
  pinMode(triggerPin, OUTPUT);
  pinMode(echoPin, INPUT);
#ifdef enableSerialLog
  Serial.println("Setting up Ultrasonic Sensor.");
#endif
} // end ultrasonic_setup

// Function adapted to calculate the median of 11 readings from the ultrasonic sensor and display it as the read distance
void readUltrasonic()
{
  int readings[11]; // 11 readings (To calculate the median it is better to use an odd number)
  int ultrasonic_readings_array_size = sizeof(readings) / sizeof(readings[0]);

#ifdef enableSerialLog
  Serial.println("ultrasonic_readings_array_size = " + String(ultrasonic_readings_array_size));
#endif

  // Take 11 consecutive readings to calculate the median and eliminate undue readings and outliers due to ultrasound reflection:
  for (int i = 0; i < ultrasonic_readings_array_size; i++)
  {               // for1
  check_distance: // Label for goto
    digitalWrite(triggerPin, LOW);
    delayMicroseconds(5);
    digitalWrite(triggerPin, HIGH);
    delayMicroseconds(10);
    pulseLength = pulseIn(echoPin, HIGH);
    readingDistance = pulseLength / 58; // Measured distance in centimeters
    delay(50);

    if (readingDistance > 500 || readingDistance < 0)
    { // eliminate erroneous readings above or below the sensor range
      goto check_distance;
    }
    readings[i] = readingDistance;

#ifdef enableSerialLog
    Serial.println("readings-" + String(i) + " = " + String(readings[i]));
#endif
  } // for1

  float median = calculateMedian(readings, ultrasonic_readings_array_size); // Calculate the Median

  // TODO: Verifica se a median mudou significativamente
  // if (abs(median - lastEchoDistance) >= 1) { // check for change in distance só manda msg se mudar o valor > 1cm
  // lastEchoDistance = median;

#ifdef enableSerialLog
  Serial.println("Distância lida pelo sensor ultrassônico (mediana): " + String(median) + "cm");
  distance_reading_done = true;
  // Serial.println("distance_reading_done: " + String(distance_reading_done));
#endif
  // }

  delay(50); // para economizar bateria, pode-se reduzir esse tempo
}

// TODO: improve commenting
float calculateMedian(int *array, int arraySize)
{
  qsort(array, arraySize, sizeof(int), compareReadings);

// Print the sorted values
#ifdef enableSerialLog
  Serial.println("Leituras das distâncias ordenadas:");
  for (int i = 0; i < arraySize; i++)
  {
    Serial.println(array[i]);
  }
  Serial.println("\n");
#endif

  if (arraySize % 2 == 0)
  {
    return (float)(array[arraySize / 2 - 1] + array[arraySize / 2]) / 2;
  }
  else
  {
    return (float)array[arraySize / 2];
  }
}

int compareReadings(const void *a, const void *b)
{
  return (*(int *)a - *(int *)b);
}
#endif // enableUltrasonic

//////////////////////////////////////////////////// goToSleep() ////////////////////////////////////////////////////
void goToSleep()
{
  logState(10); // vai dormir
  if (goToSleep_flag == 2)
  { // hibernará por 1 minuto
#ifdef enableWatchDog
    IWatchdog.reload();
#endif
    Serial.println("Hibernando por " + String(hibernation_time) + " segundos... goToSleep_flag == " + String(goToSleep_flag));
    delay(10);
    LowPower.shutdown(1000 * hibernation_time); // sleeps by hibernation_time sec
  }
  // Entra em Deep Sleep e acorda em horas cheias hh:00 ou hh:30
  if (goToSleep_flag == 1)
  {
    //   //DateTime now = rtc.now();
    //   //int sleepTime = 59 - now.minute(); //TinyRTC
#ifdef enableWatchDog
    IWatchdog.reload();
#endif
    Serial.println("Hibernando por " + String(hibernation_time) + " segundos... goToSleep_flag == " + String(goToSleep_flag));
    delay(10);
    LowPower.shutdown(1000 * hibernation_time); // sleeps by hibernation_time sec
  }
}

#ifdef enableLoRa
void LoRa_rxMode()
{
  LoRa.enableInvertIQ(); // active invert I and Q signals
  LoRa.receive();        // set receive mode
}

void LoRa_txMode()
{
  LoRa.idle();            // set standby mode
  LoRa.disableInvertIQ(); // normal mode
}
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

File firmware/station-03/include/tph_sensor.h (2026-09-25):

/**
 * @file tph_sensor.h
 * @brief TPH sensor interface for Temperature, Pressure, Humidity measurements
 *
 * This module provides a unified interface for multiple TPH sensor types,
 * following the same architectural pattern as ultrasonic.cpp.
 *
 * Supported sensors:
 *  - BMP280:  I2C, Temperature + Pressure
 *  - BME280:  I2C, Temperature + Pressure + Humidity
 *  - SHT20:   I2C, Temperature + Humidity (IP65 rated)
 *
 * Hardware Connection (Nucleo L476RG - Morpho CN10):
 *   Nucleo         Sensor
 *   3V3          - VCC
 *   GND          - GND
 *   PB8 (CN10.3) - SCL
 *   PB9 (CN10.5) - SDA
 *
 * @note On STM32duino, I2C pins MUST be set using Wire.setSDA()/Wire.setSCL()
 *       before Wire.begin(). Using Wire.begin(sda, scl) does not reliably
 *       remap pins on all STM32 variants.
 *
 * Required libraries:
 *   - For BMP280/BME280: Adafruit BMP280 Library @ ^2.6.8
 *   - For SHT20: DFRobot_SHT20 @ ^1.0.0
 *
 * @author Alexandre Nuernberg
 * @date February 2026
 *
 * SPDX-License-Identifier: AGPL-3.0-or-later
 * Copyright (C) 2024–2026 Alexandre Nuernberg <alexandreberg@gmail.com>
 *
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
 * You should have received a copy of the GNU Affero General Public License
 * along with this program. If not, see <https://www.gnu.org/licenses/>.
 */

#ifndef TPH_SENSOR_H
#define TPH_SENSOR_H

#include <Arduino.h>

/*******************************************************************************
 * Sensor Type Definitions
 ******************************************************************************/

/**
 * @brief Sensor type preprocessor constants for compile-time selection
 *
 * These MUST be #define macros (not just enum) so the preprocessor
 * can evaluate #if conditions for conditional compilation.
 */
#define TPH_SENSOR_BMP280  1  /**< BMP280: I2C, Temp + Pressure */
#define TPH_SENSOR_BME280  2  /**< BME280: I2C, Temp + Pressure + Humidity */
#define TPH_SENSOR_SHT20   3  /**< SHT20:  I2C, Temp + Humidity (IP65) */

/**
 * @brief TPH sensor type enumeration (for runtime use)
 */
typedef enum {
    TPH_TYPE_BMP280 = TPH_SENSOR_BMP280,
    TPH_TYPE_BME280 = TPH_SENSOR_BME280,
    TPH_TYPE_SHT20  = TPH_SENSOR_SHT20
} tph_sensor_type_t;

/**
 * @brief TPH sensor capabilities flags
 */
typedef enum {
    TPH_CAP_TEMPERATURE = 0x01,  /**< Sensor measures temperature */
    TPH_CAP_PRESSURE    = 0x02,  /**< Sensor measures pressure */
    TPH_CAP_HUMIDITY    = 0x04   /**< Sensor measures humidity */
} tph_sensor_capability_t;

/*******************************************************************************
 * Configuration Structures
 ******************************************************************************/

/**
 * @brief TPH sensor configuration structure
 *
 * Contains sensor-specific parameters for different TPH sensor models.
 */
typedef struct {
    const char *name;               /**< Sensor model name */
    tph_sensor_type_t type;         /**< Sensor type identifier */
    uint8_t capabilities;           /**< Bitmask of tph_sensor_capability_t */
    uint8_t i2cAddress;             /**< Default I2C address */
    uint8_t i2cAddressAlt;          /**< Alternate I2C address (0 if none) */
    uint16_t initDelayMs;           /**< Initialization delay (milliseconds) */
    uint16_t measurementDelayMs;    /**< Time between measurements (ms) */
} tph_sensor_config_t;

/**
 * @brief Structure to store TPH sensor readings
 */
typedef struct {
    float temperature;      /**< Temperature in Celsius (NAN if not available) */
    float pressure;         /**< Pressure in hPa (NAN if not available) */
    float humidity;         /**< Relative humidity % (NAN if not available) */
    bool readingValid;      /**< True if reading is valid */
    uint8_t errorCode;      /**< Error code (0 = no error) */
} tph_sensor_readings_t;

/*******************************************************************************
 * Error Codes
 ******************************************************************************/

#define TPH_ERROR_NONE          0   /**< No error */
#define TPH_ERROR_NOT_FOUND     1   /**< Sensor not found on I2C bus */
#define TPH_ERROR_INIT_FAILED   2   /**< Initialization failed */
#define TPH_ERROR_READ_FAILED   3   /**< Read operation failed */
#define TPH_ERROR_CRC_FAILED    4   /**< CRC check failed (SHT20) */
#define TPH_ERROR_TIMEOUT       5   /**< Communication timeout */

/*******************************************************************************
 * I2C Pin Definitions (Nucleo L476RG)
 ******************************************************************************/

#ifndef TPH_SENSOR_SDA
#define TPH_SENSOR_SDA PB9
#endif

#ifndef TPH_SENSOR_SCL
#define TPH_SENSOR_SCL PB8
#endif

/*******************************************************************************
 * Public API Functions
 ******************************************************************************/

/**
 * @brief Get current sensor configuration
 *
 * @return Pointer to current sensor configuration structure, or nullptr if
 *         sensor not initialized
 */
const tph_sensor_config_t* tph_sensor_getConfig(void);

/**
 * @brief Initialize TPH sensor
 *
 * Configures I2C and initializes communication with the selected sensor.
 * Uses the sensor type defined by TPH_SENSOR_TYPE macro.
 *
 * @return true if initialization successful, false otherwise
 */
bool tph_sensor_init(void);

/**
 * @brief Read all measurements from TPH sensor
 *
 * Reads temperature, pressure, and/or humidity based on sensor capabilities.
 * Unavailable measurements are set to NAN.
 *
 * @param readings Pointer to tph_sensor_readings_t structure to store results
 * @return true if reading was successful, false otherwise
 */
bool tph_sensor_read(tph_sensor_readings_t *readings);

/**
 * @brief Print TPH sensor readings to serial console
 *
 * @param readings Pointer to tph_sensor_readings_t structure
 */
void tph_sensor_printReadings(const tph_sensor_readings_t *readings);

/**
 * @brief Check if sensor has specific capability
 *
 * @param capability Capability to check (TPH_CAP_TEMPERATURE, TPH_CAP_PRESSURE,
 *                   or TPH_CAP_HUMIDITY)
 * @return true if sensor has capability, false otherwise
 */
bool tph_sensor_hasCapability(tph_sensor_capability_t capability);

#endif // TPH_SENSOR_H

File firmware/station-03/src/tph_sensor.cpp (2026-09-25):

/**
 * @file tph_sensor.cpp
 * @brief Implementation of TPH (Temperature, Pressure, Humidity) sensor functions
 *
 * Supports multiple sensor types with compile-time selection.
 * Uses same architectural pattern as ultrasonic.cpp for consistency.
 *
 * @author Alexandre Nuernberg
 * @date February 2026
 *
 * SPDX-License-Identifier: AGPL-3.0-or-later
 * Copyright (C) 2024–2026 Alexandre Nuernberg <alexandreberg@gmail.com>
 *
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
 * You should have received a copy of the GNU Affero General Public License
 * along with this program. If not, see <https://www.gnu.org/licenses/>.
 */

#include "tph_sensor.h"
#include <Wire.h>

/*******************************************************************************
 * Configuration - Select sensor type here
 ******************************************************************************/

/**
 * @brief Select the TPH sensor type to use
 *
 * Options:
 *   TPH_SENSOR_BMP280 (1) - BMP280: Temp + Pressure
 *   TPH_SENSOR_BME280 (2) - BME280: Temp + Pressure + Humidity
 *   TPH_SENSOR_SHT20  (3) - SHT20:  Temp + Humidity (IP65)
 */
#ifndef TPH_SENSOR_TYPE
// #define TPH_SENSOR_TYPE TPH_SENSOR_BMP280
#define TPH_SENSOR_TYPE TPH_SENSOR_SHT20
#endif

/** @brief Enable serial debug output */
#define enableSerialLog

/*******************************************************************************
 * Include sensor-specific libraries based on selection
 ******************************************************************************/

#if (TPH_SENSOR_TYPE == TPH_SENSOR_BMP280) || (TPH_SENSOR_TYPE == TPH_SENSOR_BME280)
#include <Adafruit_Sensor.h>
#include <Adafruit_BMP280.h>
#endif

#if (TPH_SENSOR_TYPE == TPH_SENSOR_SHT20)
#include <DFRobot_SHT20.h>
#endif

/*******************************************************************************
 * Sensor Configuration Definitions
 ******************************************************************************/

/**
 * @brief Predefined sensor configurations
 */
static const tph_sensor_config_t sensorConfigs[] = {
    /* BMP280: Temperature + Pressure */
    {
        .name               = "BMP280",
        .type               = TPH_TYPE_BMP280,
        .capabilities       = TPH_CAP_TEMPERATURE | TPH_CAP_PRESSURE,
        .i2cAddress         = 0x76,
        .i2cAddressAlt      = 0x77,
        .initDelayMs        = 50,
        .measurementDelayMs = 10
    },
    /* BME280: Temperature + Pressure + Humidity */
    {
        .name               = "BME280",
        .type               = TPH_TYPE_BME280,
        .capabilities       = TPH_CAP_TEMPERATURE | TPH_CAP_PRESSURE | TPH_CAP_HUMIDITY,
        .i2cAddress         = 0x76,
        .i2cAddressAlt      = 0x77,
        .initDelayMs        = 50,
        .measurementDelayMs = 10
    },
    /* SHT20: Temperature + Humidity (IP65) */
    {
        .name               = "SHT20",
        .type               = TPH_TYPE_SHT20,
        .capabilities       = TPH_CAP_TEMPERATURE | TPH_CAP_HUMIDITY,
        .i2cAddress         = 0x40,
        .i2cAddressAlt      = 0x00,  /* No alternate address */
        .initDelayMs        = 100,
        .measurementDelayMs = 85     /* Max measurement time for SHT20 */
    }
};

/** @brief Current sensor configuration pointer */
static const tph_sensor_config_t *currentConfig = nullptr;

/** @brief Sensor initialization status */
static bool sensorInitialized = false;

/*******************************************************************************
 * Sensor Objects (only one will be compiled based on #define)
 ******************************************************************************/

#if (TPH_SENSOR_TYPE == TPH_SENSOR_BMP280) || (TPH_SENSOR_TYPE == TPH_SENSOR_BME280)
static Adafruit_BMP280 bmp;
#endif

#if (TPH_SENSOR_TYPE == TPH_SENSOR_SHT20)
static DFRobot_SHT20 sht20;
#endif
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

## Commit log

2026-09-24 chore: add licenses, ignore rules and the credential audit
    First commit of the repository, before any project content is imported.
    - LICENSE (AGPL-3.0-or-later), LICENSES/CERN-OHL-S-2.0.txt (hardware) and NOTICE
    - .gitignore: credential files, keys, database dumps, firmware binaries, trained models
    and the private CLAUDE.md can never be tracked; only *-sample files are versioned
    - .gitattributes: 3D CAD models (step/stp/stl/wrl, both cases) go to Git LFS
    - .gitleaks.toml, .pre-commit-config.yaml, .github/workflows/audit.yml
    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
2026-09-25 Add shield-morpho-v1.2.0
    Source: shield-morpho-v1.2.0:Hardware/KiCAD/RainGauge_ST_Morpho_Shield_V1.2 -> hardware/morpho-shield-v1.2
    Original release date: 2026-07-21 (author date). Committed later: this history was
    rebuilt from the tagged releases of the private development repository.
    [10x_Male_Pin_2.54_mm.STEP, 1x_Male_Pin_2.54_mm.STEP, 2x_Male_Pin_2.54_mm.STEP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]
2026-09-25 Add shield-lora-arduino-v1.0.0
    Source: shield-lora-arduino-v1.0.0:Hardware/KiCAD/SAPI_LoRa_Arduino_Shield_V1.0 -> hardware/lora-arduino-shield-v1.0
    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
    [SAPI_LoRa_Arduino_Shield_V1.0.kicad_pcb, SAPI_LoRa_Arduino_Shield_V1.0.kicad_sch]
2026-09-25 Add model4-lgbm-v2.0.0 + model6-mlr-v2.0.0
    Source: model4-lgbm-v2.0.0:AppTest/raspberry/predictive_model_darts -> predictive-models
    Source: origin/development:AppTest/raspberry/predictive_model_darts -> predictive-models
    Source: 123ea19a963dba6edafbad09bf6af4cd671f4054:AppTest/raspberry/predictive_model_darts/output_audit -> predictive-models/output_audit
    Original release date: 2026-09-12 (author date). Committed later: this history was
    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
    [alert_analysis.csv, alert_analysis_m6.csv, compare_m4_vs_m6.csv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]
2026-09-25 docs: add READMEs, curated documentation and citation metadata
    Root README trio adapted to this repository's layout, with a section on how
    it was built; CHANGELOG with the public-repository entry; CITATION.cff.
    docs/ holds a system overview, the provenance record, architecture figures,
    web-interface and predictive-model guides, hardware notes, the licensing
    report and the bench tests (US-100, M2M, notifications). New READMEs for
    the gateway (build from credentials_sample.h), the web interface and the
    hardware (third-party 3D content, Git LFS). Private paths and links to the
    development repository's issues are rewritten; test photos are re-encoded
    without EXIF and the Telegram/Gmail screensho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
    [test-03.csv, test-04.csv, teste-04.csv]
2026-10-27 docs: update dissertation citation to the final title
    The dissertation title changed on 2026-09-29 to "Desenvolvimento de um
    Sistema de Monitoramento, Predicao e Alerta de Inundacoes". Update the
    preferred-citation in CITATION.cff and the ABNT citation in both READMEs,
    with the institution's full name and the defense date (2026-10-29).
